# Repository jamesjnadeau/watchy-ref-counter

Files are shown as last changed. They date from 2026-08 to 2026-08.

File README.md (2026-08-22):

Intial prompt:

Based on the firmware available here: 

https://github.com/sqfmi/Watchy

I have clone the repo locally at ../Watchy

I'm creating a purpose built countdown timer used for reffing a football game. 

The user should see a countdown on the screen that updates every second. 
The count down should have 2 configurable start timers, start with 40 and 25 as defaults.
The user should use the two buttons on the right hand side of the device to start the timers. The top one should be the longer value
The timer buttons should have a configurable hold down before it acts as a reset of the timer, or to start the timer in general. Make it be 0.5 seconds as a default.

When the timer is up, it should buzz a configurable time, start with 1 second. 
Before the timer reaches a configurable number of seconds, default with 10 seconds, it should buzz a configurable number of times, start with 1. By default it should buzz once at 10 seconds. 

It should count down the last 5 seconds by buzzing at each second mark. So it should buzz at 5, 4, 3, 2, and 1, then do the finall configuable buzz time.
The top left button, after being held down for a configurable ammount of time, different than the above one, default 1 second, should then put the device into low power mode. The device should wake back up to normal operating mode if this button is pressed again, If in lower power mode, it should say sleeping on the display.

Please create a read me seciton below the line that documents the structure of the repo and how to install it on the device.

---

# Watchy Ref Counter

A countdown timer for sports officials, running on a
[Watchy](https://watchy.sqfmi.com) e-paper watch. Seven presets — football,
lacrosse, NCAA and NFHS baseball, NCAA and NFHS softball, and a custom slot —
each with two countdowns, big 7-segment digits, and a buzz pattern you can
follow without looking at your wrist.

**This repo stands alone.** It does not link against the
[Watchy library](https://github.com/sqfmi/Watchy); the panel is driven through
GxEPD2, the RTC chips directly over I2C, NTP through the ESP32 core's own SNTP
client, and the Bluetooth time sync through its BLE stack. Where the behaviour follows that firmware — the menu, the
set-time screen, the pin map — the comments credit it, but none of its code is
here. It builds with the reference repo nowhere on disk.

## Controls

Watchy's four buttons, by physical position:

```
   BACK (top left)  ----+---------+---- UP   (top right)
                        |  200 x  |
   MENU (bottom left) --|  200    |---- DOWN (bottom right)
                        +---------+
```

Watch out for the names: on Watchy, **MENU is the bottom-left button and BACK
is the top-left one**, which is the opposite of what they sound like.

| Button | Action | Default hold |
| --- | --- | --- |
| Top right | Start, or reset, the active preset's **long** clock | 0.5s |
| Bottom right | Start, or reset, the active preset's **short** clock | 0.5s |
| Top left | Enter low power mode; hold again to wake | 1.0s |
| Bottom left | On Ready, open the settings menu; otherwise clear the clock | 0.5s |

The two right-hand buttons always run whichever preset is active — see
*Sports* below — rather than a fixed 40 and 25 seconds.

The bottom-left button does two jobs because on the Ready screen there is no
clock to clear. Hold it there and you get the reference Watchy menu; hold it
while a clock is up and it clears back to Ready.

**A short tap does nothing.** Every action needs a deliberate hold, so a button
brushed against a sleeve mid-game cannot reset the play clock. A short
confirmation buzz fires the instant a hold registers, so you know the clock
started without looking down.

Holding a timer button while that clock is already running restarts it from
its full value.

## Sports

The right-hand buttons run whichever preset is active. Seven ship in the box
— six fixed sports plus one editable Custom slot:

| Name | Description |
| --- | --- |
| Football | football |
| Lacrosse | lacrosse shot |
| Base NCAA | NCAA baseball |
| Base NFHS | NFHS baseball |
| Soft NCAA | NCAA softball |
| Soft NFHS | NFHS softball |
| Custom | user set |

Their clock lengths and buzz marks are in *Buzz pattern*, below. `Football`
reproduces exactly what this firmware shipped with before presets existed, so
a watch that has never opened the menu behaves the same as it always did.

The active choice comes from the menu's `Sport` row, which opens a scrolling
picker: UP/DOWN moves, MENU selects and persists, BACK leaves the stored
choice alone. Like the time zone, it is kept in NVS, so it survives a
reflash — the sport a watch is set to is a property of who is carrying it,
not of the firmware on it.

Each row shows a preset's name and its two clock values; the footer below
shows the highlighted preset's description, its position in the list, and its
two warning marks as `warn <first>/<second>`. The final-countdown value isn't
there — it's 5 for every fixed preset, so it never tells two of them apart,
and it's shown spelled out on the Custom editor instead, the one preset that
can change it.

The six fixed presets are read-only. `Edit Custom` opens the one preset that
can be changed: five fields — Long, Short, Warn 1, Warn 2, Final — with
MENU stepping to the next field and committing once past the last one, BACK
stepping back, and UP/DOWN changing the value under the cursor, the same
interaction Set Time uses. The two clocks clamp to 1–199 seconds; the three
marks clamp to 0–199, where 0 turns that mark off. Editing Custom does not
select it — pick `Custom` from the `Sport` screen to make it active, the same
separation the zone picker keeps between "known" and "in use".

## Buzz pattern

Every preset buzzes on the same four events, at the marks that preset sets:

| Event | Buzz |
| --- | --- |
| First warning, at `warnAtSeconds` remaining | `WARNING_BUZZ_COUNT` (1) short buzz |
| Second warning, at `warn2AtSeconds` remaining | `WARNING_BUZZ_COUNT_2` (2) short buzzes |
| Final countdown, at or below `finalCountdownFrom` | 1 short buzz (150ms) on each second mark |
| Expire, at 0 | 1 long buzz (1000ms) |

A mark of 0 turns it off — Football's second warning ships off, which is why
the stock clock only ever buzzes once early. A mark that falls at or inside
the final countdown is silently swallowed by the per-second buzz, which
already covers it. The two buzz counts and the expire length are global, in
`settings.h`; the marks themselves are per-preset, in `RefSport.cpp`:

| Name | Long | Short | Warn 1 | Warn 2 | Final from |
| --- | --- | --- | --- | --- | --- |
| Football | 40 | 25 | 10 | – | 5 |
| Lacrosse | 120 | 20 | 30 | 10 | 5 |
| Base NCAA | 120 | 20 | 30 | 10 | 5 |
| Base NFHS | 80 | 20 | 30 | 10 | 5 |
| Soft NCAA | 90 | 20 | 30 | 10 | 5 |
| Soft NFHS | 60 | 20 | 20 | 10 | 5 |
| Custom | 40 | 25 | 10 | – | 5 |

Every mark above is in seconds **remaining**, matching what the clock counts
down. This is worth being deliberate about, because
[ReadyRef](https://ready-ref.com/personal-timers/) — the commercial timers
this preset table is modelled on — quote their pre-warnings in seconds
*elapsed*. Their football timer's "30 second pre-warning" on a 40 second
clock is the same moment as Football's `Warn 1` of 10 above: 30 seconds in is
10 seconds left. Getting that backwards would fire the warning at the wrong
end of the play.

Buzzes are deliberately blocking, and fire *before* the screen redraws: the
buzz is the cue you actually react to, and an e-paper refresh takes most of a
second. This costs no accuracy, because remaining time is always recomputed
from the timestamp the clock started at rather than accumulated tick by tick.

## Screens

Every screen carries the wall clock at the top left and a battery gauge at the
top right.

**Ready** — shown at boot and on wake. Both of the active preset's clocks
stacked to line up with the two right-hand buttons that start them. The
footer shows the active sport's name, in capitals, in place of `HOLD TO
START` — the thing worth checking before kickoff is which preset is loaded,
not how the buttons work.

**Running** — the current clock, large, updating every second. The header is
the same wall clock and battery gauge every screen carries; it does not say
which of the two clocks is counting.

**Time expired** — `00` holds for `EXPIRED_HOLD_MS` (3s), long enough to
register the delay of game, then the watch drops back to Ready on its own.
Starting a new clock during that window cancels the return.

**Sleeping** — low power mode.

**Menu** — held open from Ready. Navigation follows the reference: UP/DOWN to
move, MENU (bottom left) to select, BACK (top left) to leave. It also drops
back to Ready by itself after `MENU_TIMEOUT_MS`, so a menu opened by accident
cannot strand you mid-game. Nine entries do not fit the panel at once, so the
list scrolls a seven-row window, keeping the highlighted entry in view the same
way the time zone picker already does. Two of the nine are conditional — **Sync
NTP** and **Sync BT** — and with neither on offer the remaining seven fit
without scrolling at all.

Every screen the menu opens times out on the same rule, and a timeout always
**discards**: Set Time leaves the clock alone, Edit Custom leaves the stored
preset alone, and the two pickers leave their stored choice alone. Only
pressing MENU past the last field commits. This matters more than it sounds —
these screens repaint about twice a second, so one left open would otherwise
hold the panel refreshing until the battery went flat.

| Entry | What it does |
| --- | --- |
| About | Version, board name, battery, time, uptime, last sync, RTC type |
| Sync NTP | Connect and set the clock from `NTP_SERVER`. Only listed once **Setup WiFi** has connected |
| Sync BT | Set the clock from a phone over Bluetooth. Listed whenever `BT_TIME_SYNC` is on |
| TZ: *name* | Pick a US time zone from a scrolling list |
| DST: Auto/Off | Turn the daylight saving rule on or off |
| Set Time | Set the clock by hand, no WiFi needed |
| Setup WiFi | Captive portal to save credentials |
| Sport: *name* | Pick one of the seven presets from a scrolling list |
| Edit Custom | Set the five Custom fields by hand |

The **Sport**, **TZ** and **DST** rows show their current value rather than
fixed text, so the menu doubles as the status display for all three. **DST**
toggles in place and redraws with a fast partial refresh; everything else
opens a screen.

**Sync NTP** is hidden until **Setup WiFi** has connected successfully, since
with no credentials stored it could only ever report a failure. The watch
remembers that in NVS (`RefWifi.cpp`), so it survives a reflash — but a watch
upgraded from a firmware without that flag has nothing stored and will hide the
row until **Setup WiFi** is run once more. A setup that fails or times out
clears the flag again, correctly: that screen wipes the saved credentials
before it raises its access point.

**Sync BT** is the other way round: it needs nothing saved, so it is there from
the first boot. It advertises the watch for `BT_SYNC_TIMEOUT_MS` (60s) and
waits for a phone to write the time; the screen says when a phone has
connected, BACK gives up early, and the result screen names the zone the
conversion used. See *Setting the clock from a phone* below for what to press
on the phone.

There is no "Show Accelerometer". The reference has one, but nothing on a play
clock reads the sensor, and leaving it out means the BMA423 is never powered
up at all. There is no "Vibrate Motor" buzz test either — the buzzer announces
every warning mark and every expiry, so a dedicated screen for it earned a menu
row it did not need.

## Time zones and daylight saving

The RTC holds UTC. The zone offset is applied on the way out, every time the
clock is read, which is what makes the two menu entries cheap: changing zone or
flipping the DST switch takes effect on the next redraw and never rewrites the
clock chip.

The **TZ** entry lists all eleven US zones by name, with their standard offset
on the row and the abbreviations and region underneath:

| Zone | Standard | Daylight | Where |
| --- | --- | --- | --- |
| Eastern | UTC−5 EST | EDT | NY, DC, Atlanta, Miami |
| Central | UTC−6 CST | CDT | Chicago, Dallas, Minneapolis |
| Mountain | UTC−7 MST | MDT | Denver, Salt Lake, Albuquerque |
| Arizona | UTC−7 MST | — | most of Arizona |
| Pacific | UTC−8 PST | PDT | LA, Seattle, SF, Las Vegas |
| Alaska | UTC−9 AKST | AKDT | most of Alaska |
| Aleutian | UTC−10 HST | HDT | western Aleutians |
| Hawaii | UTC−10 HST | — | Hawaii |
| Samoa | UTC−11 SST | — | American Samoa |
| Atlantic | UTC−4 AST | — | Puerto Rico, USVI |
| Chamorro | UTC+10 ChST | — | Guam, N. Marianas |

**DST: Auto** means the US federal rule is applied when the date calls for it —
forward at 02:00 local standard on the second Sunday in March, back at 02:00
local daylight on the first Sunday in November — not that the clock is shifted
year round. Nothing needs doing at a changeover: the offset is computed from
the instant being displayed, so the watch is right on both sides of it and
right again if it is rebooted or asleep across it. **DST: Off** pins the zone
to standard time all year. The five zones with no daylight saving ignore the
switch either way.

Both settings are stored in NVS, so they survive a reflash — the zone is a
property of where the watch is, not of the firmware on it. `DEFAULT_TIME_ZONE`
and `DEFAULT_DST_AUTO` in `settings.h` are only the starting point, used until
the menu has been used once.

The rule is the one in force since 2007 (Energy Policy Act of 2005). It is
verified against the real transition dates for 2024–2027 and 2030 in every
zone; see *Testing* below. Set Time is exact except for the one hour a year
that springing forward deletes — typing 02:30 on that morning stores 01:30,
because 02:30 never happens.

## Timekeeping

The time comes from the watch's RTC chip, which `RefRtc` probes for at boot —
a PCF8563 at 0x51 on the V2.0, an RV-3028-C7 at 0x52 on the C6 board. It
keeps running through low power mode and
through a reflash, so the watch only needs setting once. The About screen
reports which one was found.

The chip is kept in UTC, not local time. That is what lets the zone and DST
settings change with no clock write and no drift, and it means an NTP sync
needs no offset applied to it.

Drift is handled three ways. **Set Time** sets it by hand, in local time.
**Sync BT** sets it from a phone over Bluetooth, with no WiFi involved.
**Sync NTP** sets it from the internet, on demand from the menu. It also runs
itself automatically once WiFi credentials have been saved, on a schedule
that needs both of these to be true: the watch has sat untouched — no button
press, no sleep entry — for `NTP_RESYNC_HOURS` (3 by default), and at least
`NTP_MIN_SYNC_INTERVAL_HOURS` (24) have passed since the last attempt, so a
run of idle moments in a row cannot trigger back-to-back radio activity.
Sleep entry counts as activity in its own right, so putting the watch away
resets the quiet clock rather than letting it tick through the night. Set
`NTP_RESYNC_HOURS` to 0 to only ever sync by hand. A PCF8563 drifts roughly a
minute a month, so even a daily sync keeps that under a second. The C6 board's
RV-3028-C7 is factory trimmed to about half a minute a year, and needs the
sync far less.

The two chips do not share a register layout, and the difference is the kind
that fails quietly: the PCF8563 holds the date at 0x05 and the weekday at
0x06, while the RV-3028 has the weekday at 0x03 and the date at 0x04. Decoding
one with the other's map yields a day of the month between 0 and 6 — wrong,
but shaped like a date. `tests/rtc_test.cpp` pins both layouts against a stub
I2C bus, which is the only part of this that can be checked without hardware.

An automatic sync blocks for several seconds while the radio comes up, which
is why it waits for quiet rather than firing the moment nobody is looking.
That holds even in low power mode: the watch arms a deep-sleep timer against
the same schedule, wakes itself when a sync falls due, syncs, and goes
straight back to sleep — the SLEEPING screen already on the panel is never
touched. It never runs while a clock is counting.

### Setting the clock from a phone

**Sync BT** is for the case WiFi does not cover: a field with no network you
have credentials for, and a phone in your pocket that knows the time.

The watch is the peripheral. While the screen is open it advertises the
standard Bluetooth **Current Time Service** (`0x1805`) under `BT_DEVICE_NAME`,
and the phone connects and *writes* the time into it. That direction is the
only one that works without an app written for this watch: neither iOS nor
Android will hand its clock to an arbitrary peripheral that asks for it, but
writing into a watch's Current Time Service is exactly what the service is
for. It is the same route the open source PineTime firmware takes, which is
why the apps that already do it work here unchanged:

| On the phone | What to do |
| --- | --- |
| **Gadgetbridge** (Android, F-Droid) | Pair the watch as a generic device; it syncs time to a connected device on its own |
| **nRF Connect** (Android / iOS) | Connect, open service `0x1805`, write characteristic `0x2A2B` |
| Anything else that syncs time to a BLE watch | Point it at the Current Time Service |

Two characteristics are accepted, both standard:

| UUID | What it carries |
| --- | --- |
| `0x2A2B` Current Time | year, month, day, hour, minute, second — the clock itself |
| `0x2A0F` Local Time Information | the UTC offset that clock is expressed in |

The first is the one that matters. The second decides how the wall clock a
phone writes becomes the UTC the RTC holds: with it, the phone's own offset is
used and the watch's **TZ** setting does not enter into it; without it, the
time is taken as local to whatever zone the watch is set to, exactly as a time
typed into **Set Time** would be. Most clients send only the first, which is
fine as long as the phone and the watch agree about the zone — and the result
screen says which of the two happened, so an hour out is diagnosable rather
than mysterious. A write is refused outright if it does not parse or falls
outside a sane range, so a stray or malformed packet cannot set the clock to
1970.

Nothing is bonded or encrypted. The only thing a stranger in radio range can
do is set the watch's clock, and only in the minute the screen is open; that
is not worth pairing every phone that might want to set it. The radio is up
only inside that window — `RefBleTime::begin()` starts the controller and
`end()` takes it back down — so a watch that never opens the screen pays
nothing for the feature but the flash it occupies.

Automatic sync stays with NTP by default. Set `BT_AUTO_SYNC_SECONDS` above 0
and a due sync that NTP could not satisfy — no credentials, or a failed
connection — falls back to advertising for that long, which is worth having
only if a companion app on a phone syncs time to this watch by itself. The two
radios are never up at once: WiFi is dropped before Bluetooth starts.

The header clock is repainted on its own partial window when the minute rolls
over, so keeping it live costs one ~400ms refresh a minute rather than a whole
screen. It is deliberately **not** updated while a clock is counting down: the
tick path stays reserved for the countdown, so the time can sit stale for as
long as the active clock runs — up to 199s on Custom at its ceiling — and
catches up as soon as the clock stops.

## Repo structure

```
watchy-ref-counter/
├── README.md          this file
├── platformio.ini     build config; one env per supported board (V2.0, C6)
└── RefCounter/        the sketch (also a valid Arduino IDE sketch folder)
    ├── RefCounter.ino main loop and the IDLE/RUNNING/EXPIRED/SLEEPING states
    ├── settings.h     every tunable number, and nothing else
    ├── board.h        the pin map, per revision, and button polarity
    ├── Buttons.h/.cpp debounced reads with one-shot hold detection
    ├── Buzzer.h/.cpp  vibration motor
    ├── RefPanel.h/.cpp    the GxEPD2 panel instance and its pins
    ├── RefDisplay.h/.cpp  screen layout and e-paper refresh strategy
    ├── RefRtc.h/.cpp      the PCF8563 and RV-3028-C7 clocks, over I2C
    ├── RefClock.h/.cpp    timekeeping, NTP sync, battery
    ├── RefZone.h/.cpp     US time zones and the daylight saving rule
    ├── RefSegments.h/.cpp  where the countdown digits land, host-tested
    ├── RefSport.h/.cpp     sport presets and the custom slot
    ├── RefWifi.h/.cpp      whether WiFi has ever been set up, host-tested
    ├── RefMenuItems.h/.cpp the menu's row order and labels, host-tested
    └── RefMenu.h/.cpp      the settings menu
```

### Dependencies

Three libraries, all from the registry:

| Library | For |
| --- | --- |
| GxEPD2 | the GDEY0154D67 panel, including fast partial update |
| Adafruit GFX | fonts and primitives |
| WiFiManager | the captive portal behind "Setup WiFi" |

Bluetooth adds no fourth: the BLE stack and its GATT server come with the
ESP32 Arduino core, and the Current Time Service is a handful of bytes this
project encodes itself, in `RefCtsTime.cpp`.

Everything else is either this project's own or comes with the ESP32 Arduino
core. Notably there is **no RTC library**: each RTC is a handful of BCD
registers, and talking to them directly avoids a dependency that caused
trouble — one whose `master` no longer compiles against a current core.

The folder is named `RefCounter/` so it satisfies the Arduino IDE's rule that a
sketch folder match its `.ino`, while `platformio.ini` points `src_dir` at the
same folder. One copy of the source, two build systems.

### Design notes

**Why none of the Watchy library is used.** Its `Watchy::init()` is the whole
lifecycle — wake, draw one frame, deep sleep — and it ends in `deepSleep()`
without returning, which cannot work for a clock that ticks every second. That
alone forced an own main loop. Reusing just the menu then proved impossible
too: `Watchy::showMenu()` hard-codes six entries, and `showBuzz()`, `setTime()`
and `showSyncNTP()` each finish by redrawing it, so "Show Accelerometer" could
not be dropped without it flashing back for 2.6s after most actions. With the
menu written here anyway, the remaining pieces — a GxEPD2 wrapper, two RTC
chips and an NTP call — were smaller than the dependency they justified.

**Digits are drawn, not typed.** The countdown is seven filled rectangles per
digit rather than a font glyph. That keeps the countdown's exact bounding box
knowable, which is what lets the partial-update window below be hard-coded
safely — the claim now rests on `layoutCount` in `RefSegments.cpp`, which is
host-tested against its own 199 ceiling, rather than on the countdown always
being exactly two digits — and it drops the 14KB DSEG7 font from the build.
The segment geometry is four numbers (`SegStyle`) per size, instantiated in
`RefDisplay.cpp`, so resizing the digits is a one-line change.

**Refresh strategy.** Three tiers, cheapest first:

| Call | Area | Cost | Used for |
| --- | --- | --- | --- |
| `renderDigits()` | 200x124 window | ~280ms | every second of a running clock |
| `render(v, false)` | whole screen, partial | ~400ms | state changes (start, expire, wake) |
| `render(v, true)` | whole screen, full | ~2.6s | returning to Ready |

`renderDigits()` repaints only the countdown into the framebuffer and calls
GxEPD2's `displayWindow()`, so only 62% of the panel is driven — the header,
footer and battery are left standing. The window widened from 176px to the
full 200px so it always covers the skinny hundreds bar; the extra cost every
second is the price of never leaving a stale leading `1` behind when a clock
crosses back under 100.

Partial refreshes leave faint ghosting, and only a full refresh clears it. Both
routes back to Ready arrange for one, but neither pays for it up front:

- **A clock expires.** `00` holds for three seconds, then the return to Ready
  is itself the full refresh. One redraw does both jobs, and by then play has
  stopped.
- **You clear it by hand.** The return is a *partial* refresh, so the button
  responds in ~400ms rather than freezing for 2.6s. The full refresh is queued
  for `SCREEN_TIDY_DELAY_MS` later and only fires once nothing is happening;
  starting a clock cancels it.

Either way the 2.6s stall never lands mid-down.

**Power.** The CPU drops to 80MHz, and the watch light-sleeps between button
polls whenever no clock is running, waking on a button GPIO with a 250ms timer
as a backstop. Low power mode is a real deep sleep with an `ext1` wake on the
top-left button, plus a timer wake armed against the NTP resync schedule so
the watch can correct its clock unattended. Set `LIGHT_SLEEP_WHEN_IDLE` to
`false` in `settings.h` to fall back to plain polling if your board misbehaves.

**Accuracy.** The countdown is derived from `esp_timer_get_time()` against the
main crystal. Light sleep during e-paper busy-waits is accounted for using the
calibrated RTC slow clock, which drifts a fraction of a percent — on the order
of a tenth of a second across a 40 second count.

## Configuring

Everything lives in [`RefCounter/settings.h`](RefCounter/settings.h). The ones
you are most likely to touch:

```c
static const char     DEFAULT_SPORT[]      = "Football"; // until set in the menu
static const uint16_t CUSTOM_LONG_SECONDS  = 40;  // the Custom slot's factory
static const uint16_t CUSTOM_SHORT_SECONDS = 25;  //   values, likewise only a
static const uint16_t CUSTOM_WARN_SECONDS  = 10;  //   starting point
static const uint16_t CUSTOM_WARN2_SECONDS = 0;   // 0 = off
static const uint16_t CUSTOM_FINAL_FROM    = 5;
static const uint32_t TIMER_HOLD_MS        = 500;  // hold to start / reset
static const uint32_t SLEEP_HOLD_MS        = 1000; // hold for low power mode
static const uint32_t BUZZ_EXPIRE_MS       = 1000; // buzz at zero
static const uint8_t  WARNING_BUZZ_COUNT   = 1;    // buzzes at the first mark
static const uint8_t  WARNING_BUZZ_COUNT_2 = 2;    // buzzes at the second
static const bool     DARK_MODE           = true;  // true = white on black
static const bool     CLOCK_24_HOUR       = false;
static const char     DEFAULT_TIME_ZONE[] = "Eastern"; // until set in the menu
static const bool     DEFAULT_DST_AUTO    = true; // apply the US rule by date
static const uint32_t NTP_RESYNC_HOURS    = 3;  // 0 = only sync by hand
static const uint32_t NTP_MIN_SYNC_INTERVAL_HOURS = 24; // floor since last try
static const bool     BT_TIME_SYNC        = true; // false drops the Sync BT row
static const char     BT_DEVICE_NAME[]    = "Ref Counter"; // as seen by phones
static const uint32_t BT_SYNC_TIMEOUT_MS  = 60000; // how long it waits
static const uint32_t BT_AUTO_SYNC_SECONDS = 0; // 0 = manual Bluetooth only
```

`DEFAULT_SPORT` and the five `CUSTOM_*` values are likewise only a starting
point. The clock lengths themselves moved to the on-watch menu — `Sport` picks
among the six fixed presets, and `Edit Custom` changes the Custom slot's
numbers on the watch, with both choices kept in NVS across a reflash. Editing
these constants and reflashing only changes what a watch starts on before
anyone has touched its menu.

`DEFAULT_TIME_ZONE` and `DEFAULT_DST_AUTO` are only defaults — the menu's
**TZ** and **DST** entries override them and the choice is kept in NVS across
reflashes.

`DARK_MODE` flips the whole theme, panel border included. The stock Watchy
`7_SEG` face ships with its own `DARKMODE true`, which is why it is white on
black; there is no inversion in the display driver itself.

Clock values are limited to 1–199. The display draws two full-size digits
plus, for 100 and up, a skinny leading `1` — just the two vertical bars of a
`1`, one segment thick — to their left; the two full digits shift right to
make room. There is no room for a fourth glyph, which is why 199 is the
ceiling.

The timing values are no longer reflash-only: they sit behind the on-watch
`Sport` and `Edit Custom` entries, which need a deliberate hold from the Ready
screen to reach and time out on their own if left open, the same protection
against a fumbled button that the rest of the menu has. The six fixed presets
cannot be edited at all — only the Custom slot can, and only from the watch.

If the buttons on your unit sit in different positions than the diagram above,
swap the four role defines at the bottom of
[`RefCounter/board.h`](RefCounter/board.h) rather than editing the sketch.

## Installing

This firmware supports two boards: the **Watchy V2.0** (ESP32) and **this
repo's own ESP32-C6-MINI-1 design** in [`board-files/`](board-files/). V1.0,
V1.5 and V3 were dropped — the V1 revisions put the up button and the battery
tap on other pins, V1.0 carries a different RTC chip entirely, and V3's ESP32-S3
target has been superseded by the C6 board. `board.h` stops the build if any of
their revision flags is set, rather than flashing a pin map built for other
hardware.

### Option A — PlatformIO (recommended)

Requires [PlatformIO Core](https://platformio.org/install/cli) or the VS Code
extension.

Nothing to check out first — the three libraries are pulled from the registry
on the first build. Plug the watch in, then build and flash. Pick the env for
your board — `watchy_v2` (the default) or `watchy_c6`:

```bash
pio run -e watchy_v2 -t upload
```

`watchy_c6` pulls a different PlatformIO platform — the pioarduino fork —
because the official `espressif32` tops out at Arduino-ESP32 2.0.17, which has
no ESP32-C6 support at all. Note that the board has never been fabricated, so
nothing in that env has run on anything.

The first build downloads about 1.5GB of ESP32 toolchain and takes a few
minutes; later builds take under a minute.

### Option B — Arduino IDE

1. **Board support.** In *Preferences → Additional Board Manager URLs* add:
   `https://raw.githubusercontent.com/espressif/arduino-esp32/gh-pages/package_esp32_index.json`
   then install **esp32** (2.0.5 or newer) from *Tools → Board → Boards Manager*.

2. **Libraries.** *Tools → Manage Libraries*, then install **GxEPD2**,
   **Adafruit GFX Library** and **WiFiManager** (tzapu). Accept the dependency
   prompts. Do *not* install the Watchy library; this sketch does not use it.

3. **Board target.** *Tools → Board → ESP32 Arduino* → **ESP32 Dev Module**
   for the V2.0. The pin map is this project's own, so the board only has to
   be the right chip. (The C6 board is PlatformIO-only here; the IDE's ESP32-C6
   support depends on a 3.x core that this project does not otherwise require.)

   Then set the revision. The IDE has no build-flag field, so uncomment this
   line near the top of [`RefCounter/board.h`](RefCounter/board.h) — it has to
   go in that header, which every source file includes, not in the `.ino`,
   which would only set it for itself:

   ```c
   // #define ARDUINO_WATCHY_V20
   ```

   Under PlatformIO this is handled by `build_flags` and no edit is needed.

   Also set *Tools → Partition Scheme* to **Huge APP**, or the WiFi and
   Bluetooth stacks will not fit.

4. **Open and upload.** Open `RefCounter/RefCounter.ino`, select the serial
   port under *Tools → Port*, and hit Upload.

### If upload fails

The watch must be awake to enumerate over USB. If it is in low power mode, hold
the top-left button to wake it first.

On the **C6 board**, there is no button to hold: the download-boot strapping
pin is IO9, and this board deliberately puts no button on it, so a stuck or
dirty button can never drop the watch into the bootloader by accident.
Forcing download mode means shorting the **TP1** test pad to ground at
reset. The V2.0 has no button on GPIO 0 and relies on the USB serial chip's
auto-reset instead, so there is no button to hold there either; if
auto-reset is not working, it is a cable or port problem rather than a
timing one.

## Testing

`RefZone.cpp`, `RefSegments.cpp`, `RefSport.cpp`, `RefWifi.cpp`,
`RefCtsTime.cpp` and `RefMenuItems.cpp` carry no panel, no GPIO and no radio,
so they compile on a host and the daylight saving rule, the digit layout, the
preset table, the WiFi flag, the Bluetooth time payloads and the menu's row
order are all checked off the watch — this is exactly the kind of bug (a
changeover date, a digit running off the panel, a clamp, a menu row in the
wrong place, a Bluetooth packet believed when it should not be) that is
expensive to find on hardware and cheap to catch here.

```bash
./tests/run.sh
```

`tests/tz_test.cpp` walks the exact transition instants for 2024, 2025, 2026,
2027 and 2030, checks January and July in all eleven zones, checks that
**DST: Off** pins every zone to standard time, and round-trips 1,460 local
times through local → UTC → local. `tests/tz_edges.cpp` prints what Set Time
does inside the two transition hours. Both build the shipped `RefZone.cpp`
against a stub `Preferences` that reports nothing stored, so the `settings.h`
defaults apply.

`tests/segments_test.cpp` pins `layoutCount`'s numbers for the two styles the
panel actually uses — the two-digit and three-digit layouts, the exact pixel
`x` positions, the 100/99 boundary where the hundreds bar appears and
disappears, and clamping above 199 — then checks, exhaustively and for both
the big (RUNNING/EXPIRED) and small (Ready) styles, that no digit runs off
either edge of the panel for every value 0 through 199. SMALL is not a
theoretical case: the Ready screen draws both of the active preset's clocks
in it, and Lacrosse, Base NCAA and Custom all reach past 100. It checks
`layoutRows` the same way, including the invariant that the upper, middle
and lower segment rows abut with no gap or overlap.

`tests/sport_test.cpp` checks the shipped preset table against the numbers in
*Buzz pattern* above, that `Custom` is always the last entry, that an out-of-range index
falls back to the first preset rather than reading off the end of the table,
and that every name and description fits the menu row and picker footer they
render into. It also exercises persistence itself: the stub `Preferences`
gained a switch (`PreferencesStub::enable`) so a test can turn storage on,
which the time zone tests deliberately never do. With it on, `sport_test`
confirms the selected sport and the edited Custom fields both survive a
simulated reboot (a fresh `RefSport::begin()` call), and that a garbage index
left in NVS clamps back to the first preset rather than being trusted.

`tests/wifi_test.cpp` checks that a watch with nothing stored — or with NVS
unavailable — reads as never set up, and that the flag survives a simulated
reboot in both directions.

`tests/cts_time_test.cpp` covers the Bluetooth Current Time payloads: the ten
byte layout a phone writes, every field's range, the month lengths and the
leap year rule, the year window that throws out a phone whose own clock has
never been set, the short writes that are still understood and the ones that
are not, that a rejected write leaves the caller's `struct tm` untouched, and
that a wrong day-of-week in the packet is recomputed rather than trusted. It
does the same for Local Time Information — negative zones, half hour zones,
the "unknown" values — and round-trips what the watch publishes back through
its own parser, since a phone reading the watch and a phone writing to it must
agree about the same offset.

`tests/menu_items_test.cpp` pins the menu's row order for all four
combinations of its two conditional rows, that **Sync NTP** is absent until
WiFi is set up and **Sync BT** is present from the first boot, and that
**Setup WiFi** shifts from slot 4 to slot 6 as they appear above it — which is
the case the menu's redraw depends on, since running **Setup WiFi** inserts a
row above the one the user is standing on. It also checks that every label fits
the 18 glyphs the panel has room for, and that the removed buzz test has not
crept back in.

Nothing else here has automated tests, and none of this has run on hardware —
see below.

`tests/board_test.cpp` and `tests/board_c6_test.cpp` add a second kind of
check: they assert the V2.0 and C6 pin maps and each board's `BOARD_NAME`,
which until now nothing did for the C6 at all. `tests/run.sh` then compiles
`board.h` three more times, once per retired revision flag, to confirm each is
rejected rather than quietly building the V2.0 map.

`tests/rtc_test.cpp` runs the real `RefRtc` against a stub I2C bus
(`tests/stub/Wire.h`), where a device is a flat file of registers. It covers
both chips' BCD decoding, both register layouts, the two "the time is not set"
flags — the PCF8563's low-voltage bit and the RV-3028's power-on reset bit —
and a write-then-read round trip. Mutating the RV-3028 reader to use the
PCF8563's date register, or to skip the power-on reset check, fails it.

## Known limitations

- **None of this has been run on a watch.** It builds clean for both supported
  boards and the time zone, digit-layout and sport-preset logic are tested
  on a host, but no part of it has been exercised on real hardware. The least
  proven pieces are `RefPanel::begin()` (GxEPD2's stock init rather than the
  reference firmware's tuned one), light sleep, and whether the four buttons
  are physically where `board.h` says they are. `RefRtc`'s BCD decoding and
  chip probing used to head that list; they are now covered by
  `tests/rtc_test.cpp` against a stub bus. That covers the register layouts,
  the BCD conversion in both directions and the failure paths; it says nothing
  about whether either chip answers at its address on a real board, and the
  stub models none of clock stretching, arbitration or the RV-3028's bus
  timeout.
- Sport presets add their own untested territory: whether the leading `1`
  actually clears from the panel when a clock crosses 100 → 99 (the widened
  refresh window is the fix; only a real panel confirms it), whether nine
  menu rows scroll legibly with the highlight landing on the right row, and
  whether the Custom editor's five rows fit without the descenders clipping.
  NVS is assumed to survive a reflash for the `refsport` namespace the way it
  reportedly does for `refzone`, but that has never been confirmed either.
- Longer presets mean longer runs of partial refreshes: a 40s Football clock
  was already 39 consecutive `displayWindow` ticks before the deferred full
  refresh, but a 120s Lacrosse clock is 119 and Custom at its 199 ceiling is
  198. The full refresh on the way back to Ready still runs and still clears
  it, so nothing is broken, but how much ghosting a run that long leaves on a
  real panel in between is untested like everything else here.
- Buttons are not sampled during a buzz or a screen refresh. A hold that starts
  and ends inside one of those windows is missed; a hold you keep held is
  always caught, up to ~400ms late.
- Continuous running is the worst case for battery. Expect several hours of
  active use on a full charge; use low power mode between games.
- Bringing up WiFi for an NTP sync blocks for several seconds, and buttons are
  ignored for that whole time. It only happens after 60s untouched, and never
  during a countdown, but it is a real pause if you catch it.
- Only US time zones are listed. Elsewhere, pick whichever standard offset
  matches and turn **DST** off, or add a row to the table in `RefZone.cpp`.
- The daylight saving rule is the current US one, hard-coded. If Congress makes
  daylight saving permanent, this needs a firmware change.
- Adding WiFi grew the binary from 402KB to 1.13MB and RAM use from 29KB to
  55KB. Both are comfortably within a 4MB / 320KB device. Bluetooth adds the
  BLE stack on top of that; the `huge_app` partition leaves room for it, but
  the exact figure has not been measured here — see below.
- **The Bluetooth sync has not been run against a phone.** The byte layouts
  are host-tested and the GATT calls are written to the API that every
  Arduino-ESP32 backend shares, but nothing has confirmed that a real phone
  finds the watch, writes to it and lands on the right minute. Nor has the
  build itself been compiled: the toolchain could not be fetched in the
  environment this was written in, so the firmware figures above are the
  pre-Bluetooth ones.
- A phone will not volunteer its clock. **Sync BT** needs an app on the phone
  that writes the Current Time Service — Gadgetbridge does it by itself, nRF
  Connect does it by hand — and there is no route that works from a stock
  phone with nothing installed.
- Nothing is bonded or encrypted, so anyone in radio range can set the clock
  while the **Sync BT** screen is open. That window is a minute long and the
  worst outcome is a wrong time, which is why it is left open.
- A phone that sends no zone with the time is assumed to be in the zone the
  watch is set to. Travel to a different zone with **TZ** left behind and the
  clock lands an hour or more out; the result screen says which assumption it
  made.

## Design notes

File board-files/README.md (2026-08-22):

# Watchy Ref — ESP32-C6-MINI-1 / RV-3028-C7 board

A Watchy-compatible watch board carrying an ESP32-C6-MINI-1 module and an
RV-3028-C7 real-time clock, with the accelerometer, the USB-serial bridge and
the UART console deleted and USB-C in place of micro-USB. Derived from
[sqfmi/watchy-hardware](https://github.com/sqfmi/watchy-hardware) `v2.0`
(MIT), which supplies the e-paper, charging, power and motor circuitry
unchanged.

Design rationale, with the reasoning behind every decision:
[`docs/superpowers/specs/2026-08-18-c6-mini-rv3028-board.md`](../docs/superpowers/specs/2026-08-18-c6-mini-rv3028-board.md).

> **Never fabricated, never powered, never tested.** Read
> [`UNVERIFIED.md`](UNVERIFIED.md) before doing anything with these files.

## The design is code

The electrical design is not a drawn schematic. It is
[atopile](https://atopile.io) source under `elec/src/`, compiled to a KiCad
netlist. Reading `elec/src/watchy.ato` top to bottom tells you what is
connected to what, and `git diff` on it says exactly what a change did —
which is not true of a `.kicad_sch`.

The tradeoff is real and worth stating: there is no schematic sheet to print
and hand to someone. `ato view` draws a block diagram, but it is not a
schematic. If you want one, KiCad's netlist import gives you a rat's nest, not
a drawing.

```
board-files/
  ato.yaml                          project and build config
  requirements.txt                  the compiler version, pinned exactly
  elec/src/watchy.ato               the board: every part and every connection
  elec/src/parts.ato                passives, discretes, connectors, switches
  elec/src/mcu.ato                  ESP32-C6-MINI-1
  elec/src/rtc.ato                  RV-3028-C7
  elec/src/usb.ato                  USB-C receptacle and the ESD array
  elec/footprints/footprints.pretty custom footprints
  elec/layout/default/              the PCB (see "Layout" below)
  checks/netlist_check.py           design assertions against the netlist
  checks/drc_check.py               runs KiCad's DRC and judges the result
  checks/make_bom.py                fab BOM generator
  checks/run.sh                     build, assert, generate, check the board
  elec/layout/v2-baseline.kicad_pcb V2's layout, untouched; the overlap reference
  scripts/apply_netlist.py          netlist -> PCB, headless (mutates the board)
  scripts/route.py                  routes the board, headless (mutates it too)
  scripts/check_board.py            asserts the PCB matches the netlist
  fab/BOM.csv                       generated, committed
  vendor/                           upstream licence notices
```

## Building and checking it

```bash
python3 -m venv ~/.venvs/ato
~/.venvs/ato/bin/pip install -r requirements.txt
ATO=~/.venvs/ato/bin/ato ./checks/run.sh
```

That compiles the sources to `build/default.net`, runs the assertions, writes
`fab/BOM.csv`, checks the board against the netlist and runs DRC. Expect
`0 problem(s)` and 54 placements.

**Install from `requirements.txt`, not `pip install atopile`.** The pin is
`atopile==0.2.67` and it is exact on purpose: the floating install now gets
0.12.6, which refuses to run at all ("the CLI has been replaced by the app at
app.atopile.io"). `checks/run.sh` checks the version and stops if it is
wrong. `requirements.txt` records what every newer release does — the short
version is that 0.3 through 0.11 reject these sources, 0.12 is dead, 0.14 and
0.15 need Python 3.14, and 0.16+ is a hosted application rather than a CLI.
There is no upgrade that keeps this a headless build.

The assertions encode the constraints the spec cares about and that no
compiler can see:

| Check | What it catches |
| --- | --- |
| pin map | any GPIO that drifted from the spec's table |
| deep-sleep wake pins | a button or `RTC_INT` on a pin above IO21, which cannot wake `ext1` |
| battery ADC on ADC1 | the battery tap landing on ADC2, which is dead while WiFi is on |
| strapping pins | anything but the `TP_BOOT` test pad touching IO9 |
| USB-C CC pulldowns | a missing or shared 5.1k, and D+/D- halves left untied |
| RV-3028-C7 wiring | `VDD` off `+BATT`, or `VBACKUP` fed from a rail |
| bus pull-ups | I2C or `RTC_INT` pulled to `+BATT`, putting 4.2V on C6 inputs |
| buttons active low | a switch still wired to `+3V3`, or a leftover pull-down |
| battery divider | the divider back at 100k, or missing its filter cap |
| MCU power | the `-N4R2` variant, a floating module ground pad, EN misrouted |
| V2 blocks carried over | any drift across the 106 pads of the 43 parts transcribed from V2 |
| deleted parts | the PICO-D4, CP2102, BMA423, PCF8563, crystal or antenna creeping back |

And on the board (`scripts/check_board.py`):

| Check | What it catches |
| --- | --- |
| components | a netlist part with no footprint, or a footprint the netlist does not name |
| nets | any pad on the wrong net, or on a net where the netlist says nothing |
| mechanical | the four switches, the FPC and the battery connector drifting off V2's coordinates |
| stackup | the board falling back to 2 layers, or a missing GND / +3V3 plane |
| outline | Edge.Cuts not closing, or a cutout reappearing inside the board |
| pads on board | any pad off the edge — this is how the USB-C was found facing the wrong way |
| antenna | the module's keepout allowing pour, or not overhanging the board edge |

And DRC itself (`checks/drc_check.py`), which runs `kicad-cli pcb drc` and
holds the result to a policy rather than to a count: zero unconnected items,
zero errors except an allowlist that names each accepted violation and says
why. It also reports allowlist entries that no longer occur, so the list
cannot quietly rot.

All of these were mutation-tested: the netlist or the board was deliberately
broken in the way each check describes, and the check caught it. A check that
cannot fail is not a check.

**What is not checked: ERC — and it cannot be.** `kicad-cli sch erc` reads a
`.kicad_sch`, and this project has none; the design is atopile source
compiled straight to a netlist. Nothing looks for driven-output conflicts or
unconnected pins beyond what the assertions above happen to cover. That is a
standing cost of defining the design in code, not a temporary gap. See
[`UNVERIFIED.md`](UNVERIFIED.md).

## Layout

`elec/layout/default/watchy-ref-c6.kicad_pcb` started as V2's board, converted
from KiCad 5 and switched to a 4-layer stackup. Two scripts turn it into this
design, in order, and both are re-runnable:

```bash
python3 scripts/apply_netlist.py --dry-run   # report only
python3 scripts/apply_netlist.py             # placement, nets, planes, outline
python3 scripts/route.py                     # copper
python3 scripts/check_board.py               # verify, independently
```

They need the interpreter KiCad's `pcbnew` bindings were built against — the
system `python3`, not a venv.

### apply_netlist.py — everything except the copper

KiCad's "Import Netlist" is a GUI dialog and `kicad-cli` has no equivalent, so
this does the job with `pcbnew`. It removes the interior cutouts from
Edge.Cuts and the rule areas V2 no longer needs, deletes the parts the netlist
dropped, replaces the ones whose footprint changed *while preserving V2's
position* (most of those swaps are only a KiCad 5→7 library rename, and losing
placement over a rename would defeat the point of pinning the designators),
adds the new parts, assigns all 249 pads to their 73 nets, and lays the GND,
`+3V3` and `VBUS` pour outlines.

It also strips V2's branding — the `watchy` and `SQFMI` lettering on the mask
layers, and the two sqfmi logo footprints. This is a derivative reference
design and should not be fabricated carrying another project's marks; the
attribution belongs in this file, not etched into the board. It happens to be
worth 119 DRC errors as well: mask lettering is drawn as *apertures*, so the
word is bare copper, and every via, track and pad passing beneath one bridged
to it. The display outline (`REF**` on B.Fab) is kept — it comes from the same
library and carries the name, but it is a mechanical outline rather than a
mark, and it is what stops anything being placed under the panel.

Placement comes from a table in the script, and that table is authoritative —
it is re-applied on every run, to parts already on the board as well as to new
ones. The board is generated from these sources, so a position that only
exists because somebody dragged it in the GUI is a position nothing records.
Move a part by editing the table; the script reports every courtyard overlap
the table produces, and the fix is to edit the table again.

### route.py — the copper

There is no autorouter in KiCad and no routing API, so this is a maze router
written against `pcbnew`. It deletes every existing track and via first —
V2's routing was still on the board, and routed for V2's netlist it shorted
nets rather than connecting them — then:

- drops a via into each of the module's thermal pads. It has to: the array is
  1.2mm pads on a 1.65mm pitch, and the 0.45mm gaps are too narrow for a pour
  to enter and too narrow for a via to sit beside. Espressif's reference
  layout does the same.
- ties every pad on a poured net to its pour through its own via, except
  where the pour already touches the pad. Which nets are poured, and which of
  their pads the pour reaches, are read off the board rather than listed in
  the router -- so the two scripts cannot drift apart, and a pour that covers
  only part of its net leaves the rest as ordinary routing work.
- routes the signal nets with A* on F.Cu and B.Cu over a 0.1mm grid, hardest
  first: the differential pair and the charge-pump loop before anything can
  cross them, then whichever nets have the least room to escape their pads.
- rips up and re-routes. A net that cannot get through has usually lost a lane
  to one that went first, so a second search finds which nets are in the way,
  deletes their copper, puts the stuck net through the gap and re-routes them
  somewhere else. This is what takes the board from "almost" to finished.
- stitches GND between F.Cu, In1.Cu and B.Cu on a 3mm grid, last, in whatever
  room the signals left.
- fills the zones and reports what is still unconnected.

Power is mostly not routed as copper. GND and `+3V3` are whole-board planes
on In1.Cu and In2.Cu and a pad reaches them through a via, which is what buys
the space to route everything else on two layers.

`VBUS` is a third pour, and a bounded one. It carries the charge current -- in
at the USB-C, out through the Schottky to VSYS and into the TP4054 -- so it
wants copper rather than a track, and as eleven thin tracks fighting for lanes
it was the net the router most often failed to place. It sits on In2.Cu at a
higher priority than `+3V3`, over the block that actually carries the current:
`J2`'s four VBUS pads, `U3.5`, `C11.2`, `R14.1`, `Q4.1` and `U5.4`.

It is sized to that block and not to the net. A hull around all eleven VBUS
pads is a 202mm2 diagonal band that reaches clear across the board to collect
`D4` and `D5`, and swallows `U2.5` -- the LDO 3V3 output -- on the way, which
would strand it. Bounded to the block it costs 82mm2, traps nothing, and
leaves `D4` and `D5` as two ordinary tracks, which is what they are: stubs
hanging off the block.

In2.Cu rather than B.Cu, which is where an earlier note here suggested putting
it. Both work, but In2.Cu is already a power layer so the pour costs no
routing space, whereas the same shape on B.Cu would sit straight on top of the
`J2`/`U3`/`U5`/`Q4` congestion -- the most contested copper on the board. The
cost is a split in the `+3V3` plane under one corner of B.Cu, a return-path
discontinuity for anything crossing it, which at SPI and 12Mbps USB is not a
real concern. `VBUS_POUR_LAYER` in `apply_netlist.py` moves it.

The pour is not free. The nine covered pads are all on F.Cu, so each needs a
through via to reach In2.Cu, and a through via blocks all four layers -- nine
of them land in the tightest part of the board. `VBUS` itself routes now, and
one fewer net fails overall, but those vias took lanes `USB_DM` and `VSYS` had
been using. It is the right shape for the current path either way; it is not
the thing that finishes the board.

Every via the router places is tented on both sides. Half of them sit in a pad
field or inside a thermal pad, where a bare mask aperture would bridge to the
neighbouring pad and wick solder off the joint.

#### The board is the only source of truth

The router keeps an occupancy grid to search over, and the grid has to agree
with the copper. It used not to. There were three stores of truth rather than
two: the board, the grid, and `owned` -- a side table of which items belong to
which net -- and the grid was rebuilt from `owned`, never from the board. Any
copper that fell out of that table, or was added without updating it, was
still physically on the board and completely invisible to the router.

That is not a hypothetical. It is where `SCL` came to cross `EPD_DC` and
`EPD_BUSY` on B.Cu: a failed attempt left a partial path behind, `owned` was
overwritten with the retry, and every later rebuild pretended the old copper
was not there. Eight shorts, and nothing in the router could have noticed.

So `rebuild()` now stamps from `board.GetTracks()` and the grid is a pure
function of the board. `owned` survives as an index -- it is how a net's items
are found when it is ripped up -- but nothing is derived from it. A net can
drop out of it and the grid stays correct.

That needed one snapshot split into two, because they were doing different
jobs under one name:

| | |
| --- | --- |
| `blank` | the board with **no** copper: outline, keepouts, pads, holes. `rebuild()` and `audit()` start here, so a recomputation owes nothing to the router's own record of itself |
| `immovable` | `blank` plus the power copper. What the rip-up scout treats as *hard*: a cell blocked here is a pad or a plane drop and cannot move, while one blocked only in the live grid is some signal's track and can be ripped |

Handing the scout `blank` would let it plan routes straight through power it
may not touch, which is the bug you get for free by moving the snapshot
without noticing it had two roles.

Searching still stamps incrementally -- rebuilding after every track would be
far too slow -- so correctness rests on the incremental path matching a fresh
one. `audit()` proves it: recompute from the board, compare cell by cell,
report any difference with its coordinates and both values. This is sound
because stamping is monotone: a cell goes free -> one net -> contested and
never back, so re-stamping the same items always lands in the same state
whatever order they arrive in. A fresh rebuild is therefore the ground truth
an incrementally-updated grid must equal.

It runs every pass and prints under "GRID DISAGREED WITH THE BOARD". Anything
it reports is a bug in `route.py`; no board can legitimately make the grid and
the copper disagree. It is mutation-tested in both directions -- copper added
to the board without telling the grid, and copper removed from it -- and
catches each with the cell coordinates and both values.

#### What it does not finish

The router does not get everything. It routes the power, every ground pad and
41 of the 44 signal nets; **three are left unrouted** — `EPD_SCK` at `U1.28`,
`PREVGH` at `J1.21` and `USB_DM` at `J2.A7` — for 3 unconnected items on the
board. `route.py` exits non-zero, and `drc_check.py` and `checks/run.sh` fail,
until they are cleared. That is deliberate: a board that is 93% routed should
not be able to look finished.

`route.py` also exits non-zero on a stranded ground pad — one the pours never
reached and no via was dropped into — because a floating return is a defect
and not a cosmetic complaint. There are none at present, but they are the
failure this board produces when the right-hand side gets crowded, and they
were invisible until the pour slivers hiding them were deleted.

Which nets and which pads move between runs — the router is not deterministic
across attempts, because each attempt feeds the previous one's failures back
in. The counts are stable; the names are not.

What the router does lay down is clean. On the current board it produces **no
shorts, no crossing tracks and no clearance violations of its own**, and DRC
reports **zero errors that are not on `drc_check.py`'s accepted list** — every
clearance and hole-clearance error left is internal to a footprint (`Q4`/`R15`
at 0.165mm, inherited from V2; `J2`'s own mounting holes against its own
pads). Getting there took four fixes, each found by DRC rather than by design,
and they are worth knowing before trusting the next change:

| Bug | Symptom |
| --- | --- |
| overlapping clearance halos resolved last-writer-wins | a cell claimed by two nets became one net's, and that net then routed through the other's clearance. 96 clearance errors |
| diagonal steps cut corners | a 45° step passes between two cells it never occupies, so two opposite diagonals cross without ever sharing one. KiCad calls that a short |
| the grid went stale after rip-up | ground stitching dropped vias on top of signal vias, 0.4mm apart |
| pads keyed by (ref, name) | `J2` has four separate shield pads all called `S1`, and covering one counted as covering all four |
| pads were treated as their bounding boxes | the test points are 1mm circles and the motor's pad is an oval, so the bbox corners are outside the copper. A track that ended in one stopped short of the pad it had been routed to — and the router counted the net done, because its own reachability test used the same bbox. Six nets were "routed" and not connected |
| fill islands with nothing to reach | a pour pinched off between two tracks is still copper, still floating, and counted as unconnected. `route.py` now vias any island big enough to take one, and `apply_netlist.py` sets the zones to delete the rest |
| drilled holes were invisible to the router | an NPTH pad is a hole with no copper, so it is on no copper layer, so the pad loop skipped it entirely. Tracks routed straight over `J2`'s mounting holes and the four switches' |
| the design rules reverted behind the router's back | the rules live in the `.kicad_pro`, and loading a second board anywhere in `apply_netlist.py` makes KiCad's settings manager flush a stale copy of the project over them. 0.15 went quietly back to 0.2, and a board routed at 0.15 came back with 76 clearance errors against a rule nobody had meant to change. `apply_netlist.py` now writes them last and `check_board.py` asserts them |

Finish them in the GUI, or improve the router. What was already tried, so the
next person does not repeat it:

| Lever | Result |
| --- | --- |
| via cost swept 6 → 80 | 25 is the best; cheap vias cost more board than they save |
| ordering by pad count, by escape room, by span | all help a little; none alone gets below 5 |
| re-ordering by accumulated failure pressure, 14 attempts | the natural order won every time |
| rip-up and re-route | 5 → 3, and the only thing that moved the number much |
| search budget 80k → 250k | fixed searches that were being cut off, not the remainder |
| `VBUS` as a pour instead of a signal net | `VBUS` routes, and one fewer net fails overall — but the nine through vias it needs land in the tightest part of the board, and cost `USB_DM` and `VSYS` their lanes |

Those that remain are not walled in — each routes on its own on an empty
board — so this is congestion, not geometry, and measurably so: the pads that
*failed* have more room around them than the ones that succeeded. `J1`'s
tightest pins have 177 free cells within 1.2mm and all of them routed; the
eight that did not had 201 to 542, against a board median of 383. Nothing
failed for want of space at the pad. They failed for want of a lane, and the
lane went to whichever net asked first.

Five of the seven are at the display connector `J1` or the module pins feeding
it, which is the densest corner of the board. The lever there is not the FPC
pinout — that is fixed by the panel — but the *module* side: `EPD_SCK`,
`EPD_MOSI`, `EPD_CS`, `EPD_DC`, `EPD_RST` and `EPD_BUSY` are assigned to
`IO15`, `IO14`, `IO8`, `IO18`, `IO19` and `IO20` in `elec/src/watchy.ato`,
and those are general-purpose pins. Re-ordering them so the fan-out crosses
itself less is a change to the source, which is where this design's decisions
are supposed to live, and it is the one move the router cannot make for
itself.

Clearance is modelled as the true offset of each pad shape, not its bounding
box grown by the clearance. The difference is only at the corners, and the
corners are the whole game on a 0.5mm-pitch connector: a pad in a row that
close can only be escaped along its own axis, and squaring off the
neighbours' clearance closes exactly that lane. With bounding boxes, six of
the USB-C's pads were unreachable from anywhere.

### Placement

The parts the new layout displaced are placed by anchoring each to the pad it
actually serves and taking the nearest clear spot to it — which is what you
would do by hand, and is what decoupling wants anyway:

| Part | Anchored to | Distance |
| --- | --- | --- |
| `C12` +3V3 bulk | `U1` pad 3 (3V3) | 3.00 mm |
| `C1` EN cap | `U1` pad 45 (EN) | 2.00 mm |
| `R1` EN pull-up | `U1` pad 45 | 3.20 mm |
| `R7` RTC_INT pull-up | `U6` pin 2 (INT) | 2.12 mm |
| `Q5` motor driver | `M1` pad 2 | 3.50 mm |
| `U2` LDO | `Q4` pad 2 | **11.07 mm — review** |
| `D4` OR-ing diode | `Q4` pad 2 | **12.81 mm — review** |

`U2` and `D4` are flagged because the area around `Q4` is dense — the charger,
its programming resistors and the FPC connector are all there — and the
nearest clear space is a long way off. Both carry DC power rather than a
switching node, so the distance is tolerable, but it is worth a look before
you trust the routing there.

### The USB-C, and what it costs

`J2` is rotated 90°, with the front face of its housing flush with the board
edge at x=102.5. This matters more than it sounds: the footprint's solder tabs
are at its local −y end and the mating opening at +y, so at 0° the connector
faces *down the board* and six of its pads — including both shield tabs — hang
over the right-hand edge in mid-air. It was at 0°. `check_board.py` now
asserts every pad is on the board.

The receptacle does not really fit where V2's micro-USB was. There is 9.15mm
between the battery connector and the charger; a USB-C shell is 9.04mm wide
and its courtyard is 10.73mm. So three courtyard overlaps remain and are
accepted on purpose: `J2`/`J3` by 0.61mm, `J2`/`R16` by 0.49mm, `J2`/`Q4` by
0.13mm. The parts themselves clear each other. Moving `J2` anywhere else means
moving a part the case is cut to, or putting the port on an edge that has no
room for a 7.5mm-deep connector.

Everything else V2 carried is left where V2 had it — including a handful of
courtyard overlaps of 0.05–0.25mm that come from KiCad 9's footprints being
fractionally larger than KiCad 5's. Lifting `R8` and `R9` 0.3mm to clear one
of them was tried and reverted: it moved two parts of the charge-pump loop
off the geometry V2 proved, which is a bad trade for a rectangle that does not
touch any copper.

### Board outline

The Edge.Cuts outline measures **33.800 × 45.960 mm** on the centreline
(33.950 × 46.110 mm including the 0.15mm line width). sqfmi's published figure
of 35.5 × 46.0 mm is wrong, or at least does not describe this outline.

**V2's two watch-strap slots have been removed.** They ran at y 72.15–74.15
and y 111.61–114.11, straight through the board, and the module and its
decoupling were placed across the top one — `U1` pads 2, 3, 43 and 44, both
pads of `R1`, both of `C12` and one of `C1` were over a hole. Removing the
slots was chosen over moving the module.

The consequence is mechanical and it belongs to the case: **there is nothing
on this PCB for a strap to pin through any more, and nothing to take the
load.** The case has to carry the entire band attachment. See
[`docs/superpowers/specs/2026-08-18-waterproof-case-design.md`](../docs/superpowers/specs/2026-08-18-waterproof-case-design.md).

Board thickness stays 1.6mm so the case stack is unchanged.

### Why there is a second copy of the board

`elec/layout/v2-baseline.kicad_pcb` is V2's layout converted and given the
4-layer stackup, otherwise untouched. The overlap report diffs against it.
Diffing against the working board instead would be self-excusing: after one
run the working board *is* this script's output, so every overlap it
introduced would come back labelled "V2 already had this one". Do not edit it.

### KiCad 9 notes

- `pcbnew`'s bindings are on the system `python3` (3.13 here), not the
  `python3.12` the older instructions named.
- `board.Remove()` hands ownership of the item to Python, and freeing it there
  corrupts the SWIG type registry — the *next* `LoadBoard` comes back as a
  bare `SwigPyObject` with no methods. Use `RemoveNative()`, which deletes it
  in C++. Both scripts do.
- `PCB_VIA.SetWidth()` needs a layer argument now.
- Opening the project in KiCad 9 rewrites `watchy-ref-c6.kicad_pro` into the
  new format. No design rule changed in that upgrade; `hole_near_hole` was
  renamed `hole_to_hole` and demoted to a warning, and `text_on_edge_cuts` was
  added as an error.

## Fabrication

Nothing here is ready to order — see [`UNVERIFIED.md`](UNVERIFIED.md) — but
when it is:

- 4 layers, 1.6mm, ENIG. The module, the RV-3028 and the 0.5mm FPC connector
  are all fine pitch; HASL is not worth the yield risk.
- Tracks are 0.15mm with 0.15mm clearance, vias 0.6mm with 0.3mm drills. Any
  fab that will build a 4-layer board at all will build 0.15/0.15; it is not
  an "advanced" option and carries no price break to avoid. The board was
  0.2/0.2, inherited from V2, and on a board whose problem is corridors that
  was costing a quarter of every one of them.
- Solder mask expansion is 0.05mm. V2 had 0.2mm, which makes every opening
  0.4mm wider than its pad — on 0.5mm-pitch parts that guarantees neighbouring
  openings merge, and once the tracks came down to 0.15mm it bridged them to
  passing copper too. It was worth 155 DRC violations on its own.
- GND pads connect to the F.Cu and B.Cu pours **solidly**, not through thermal
  spokes. This is a trade: thermal relief exists to stop a pour sinking heat
  away from a small pad during reflow, and solid connections raise the risk of
  a 0402 tombstoning. Against that, GND pads get no via down to the In1.Cu
  plane — the router skips them because the outer pours already touch them —
  so the pour *is* the ground connection, and on twenty of them it could only
  reach with a single 0.15mm spoke. If a fab pushes back, the other fix is to
  keep thermal relief and give every GND pad its own via to In1.Cu, which
  costs routing space this board does not have spare.
- **Vias in pads**, in the module's thermal array only, where nothing else
  reaches. Ask for them plugged and capped, or expect solder to wick off
  those pads into the barrel.
- Single-sided assembly: every part is on F.Cu.

Order `ESP32-C6-MINI-1-N4` (4MB flash) or `-H8` (8MB). There is no PSRAM
variant to get wrong, unlike the S3-MINI-1's `-N4R2`. Specify genuine Micro
Crystal for the RV-3028-C7.

The display, battery, vibration motor and case assembly are hand work. No
assembly house will finish this board into a watch.

## Firmware

Firmware support for this board does not exist. `RefRtc` short-circuits to the
internal clock on any C6 build and has no RV-3028 driver. The
"Firmware impact" section of the spec lists what is needed; it is a separate
plan and nothing in this directory implements any of it.

The panel the firmware drives is now the **GDEY0154D67**, which replaces the
end-of-life GDEH0154D67. Same SSD1681 controller, same 200x200, same 24-pin
FPC, and GxEPD2 takes the same four-pin constructor — but the GDEY's FPC
pinout has not been read off a datasheet and compared against `J1` pin by
pin. Do that before you power a panel.

## Licences

- The V2 design this is derived from: MIT, `vendor/LICENSE-watchy-hardware.txt`.
- The ESP32-C6-MINI-1 footprint: CC-BY-SA 4.0 from
  [espressif/kicad-libraries](https://github.com/espressif/kicad-libraries),
  `vendor/LICENSE-espressif-kicad-libraries.md`.

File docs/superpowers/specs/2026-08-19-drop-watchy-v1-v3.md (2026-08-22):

# Drop Watchy V1.0, V1.5 and V3 Support

**Date:** 2026-08-19
**Status:** accepted

## Problem

The firmware supports five boards: Watchy V1.0, V1.5, V2.0 (ESP32), V3
(ESP32-S3), and this repo's own ESP32-C6-MINI-1 design in `board-files/`.
Three of those five are dead weight:

- **V1.0 and V1.5** cost `board.h` a three-way `#if` over the up button and the
  battery tap, and cost `RefRtc` a whole second driver — the DS3231, fitted
  only to V1.0, with its own BCD decode, register write and probe. V1.5 ships
  the same PCF8563 as V2.0, so it buys nothing at all beyond a `#if` in
  `RefClock::boardRevision()` to tell the two apart.
- **V3** is a stock ESP32-S3 dev board target that this repo's own C6 board has
  superseded. It carries its own pin map, its own `RefRtc` branch for the S3's
  internal clock, and it is the flag guarding two blocks that the C6 actually
  needs.

None of the five has ever been run on hardware — see the README's *Known
limitations* — so the three being removed are untested code carrying untested
branches.

The V3 flag also masks two live defects on the C6:

1. `RefPanel::begin()` calls `SPI.begin(SCK, MISO, MOSI, SS)` under
   `#ifdef ARDUINO_ESP32S3_DEV`. The C6's SPI pins are 15/23/14/8, not the
   default bus, so the C6 needs that call and does not get it. The panel would
   not talk.
2. `RefCounter.ino`'s deep-sleep block and `RefRtc::begin()` both branch on the
   S3 flag, so removing V3 without touching them changes C6 behaviour by
   accident.

## Decision

Remove V1.0, V1.5 and V3. The supported set becomes:

| Board | Env | SoC | RTC |
| --- | --- | --- | --- |
| Watchy V2.0 | `watchy_v2` (default) | ESP32 | PCF8563 @ 0x51 |
| This repo's board | `watchy_c6` | ESP32-C6-MINI-1 | RV-3028-C7 (see *Known gap*) |

## Requirements

1. **Envs.** `[env:watchy_v10]`, `[env:watchy_v15]` and `[env:watchy_v3]` are
   gone from `platformio.ini`. `watchy_v2` stays the default env; `watchy_c6`
   keeps its pinned pioarduino platform.

2. **Pin maps.** `board.h` holds exactly two: the C6 map under
   `ARDUINO_ESP32C6_DEV` and the V2.0 map under everything else. The V2.0 map
   is unconditional — `PIN_BTN_UP 35`, `PIN_BATT_ADC 34` — with no
   per-revision `#if`.

3. **Retired flags fail the build.** `-D ARDUINO_WATCHY_V10`,
   `-D ARDUINO_WATCHY_V15` and `-D ARDUINO_ESP32S3_DEV` must each stop the
   compile with a message naming the supported envs. They must *not* fall
   through to the V2.0 map: on that hardware the battery would be read off the
   wrong pin and the up button would never be seen, and an S3 has no GPIO 26 or
   35 at all. The exact text:

   ```
   Watchy V1.0, V1.5 and V3 are no longer supported; build watchy_v2 or watchy_c6
   ```

   `ARDUINO_ESP32S3_DEV` matters most here, because it comes from the board
   choice rather than from a build flag a user typed.

4. **RTC kinds.** `RefRtc::Kind` becomes `{NONE, PCF8563}`. `DS3231` goes with
   V1.0 and `INTERNAL` — the S3's own 32kHz-backed clock — goes with V3.

5. **The C6 keeps the blocks it needs.** Every `ARDUINO_ESP32S3_DEV`
   conditional is resolved deliberately, not deleted wholesale:
   - `RefPanel::begin()`'s `SPI.begin(...)` becomes `#ifdef ARDUINO_ESP32C6_DEV`
     — a fix, not a rename: the C6 needs it and never had it.
   - `RefCounter.ino`'s `rtc_gpio_*` deep-sleep block becomes
     `#ifdef ARDUINO_ESP32C6_DEV`, keeping today's behaviour for both boards.
   - `RefRtc::begin()`'s `INTERNAL` branch is deleted, so the C6 probes I2C
     like V2.0 does.

6. **Board identity.** `RefClock::boardRevision()` returned 10/15/20/30 and the
   About screen printed it as `v2.0`. Two boards remain and one of them has no
   revision number, so the number is replaced by a name: `board.h` defines
   `BOARD_NAME` as `"V2.0"` or `"C6"`, the About screen prints it directly, and
   `boardRevision()` and its `esp_chip_info` probe are deleted.

7. **Docs match.** `README.md` and `settings.h` carry no instructions, pin
   numbers, drift figures or chip references for V1.0, V1.5 or V3. The C6 stops
   being described as "a fifth env … ignore it" and becomes one of the two
   supported targets.

8. **Tests.** The host suite pins both surviving pin maps and both `BOARD_NAME`
   values, pins the surviving `RefRtc::Kind` values, and proves each retired
   flag is rejected with the message from requirement 3. The C6 map has never
   had a test — `board.h` says so itself — and gets one here.

## Known gap — the C6 has no RTC driver

> **Closed 2026-08-19**, after this spec's work landed. `RefRtc` now drives the
> RV-3028-C7 at 0x52 and a C6 build keeps time. The section is left as written
> because it is what the removal was scoped against; read it as history.

The C6 board carries an RV-3028-C7 at 0x52. `RefRtc` has never known about it:
today the C6 build probes for a DS3231 and a PCF8563, finds neither, and lands
on `Kind::NONE`, which means no timekeeping at all. That is the state before
this work and the state after it.

It is called out here because after this change the C6 is one of only two
supported boards, so the gap is more visible — but adding a driver is a
feature, not part of a removal, and it is **out of scope for this spec**. It
wants its own spec and plan.

## Out of scope

- The RV-3028-C7 driver, per above.
- `board-files/` — the hardware design is untouched.
- Existing plan and spec documents under `docs/superpowers/` are historical
  records of work already done and are not rewritten.
- No runtime behaviour changes for V2.0 or C6 beyond the `SPI.begin()` fix in
  requirement 5, which is a bug fix the removal forces into the open.

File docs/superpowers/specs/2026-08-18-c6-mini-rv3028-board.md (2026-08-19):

# C6-MINI-1 + RV-3028-C7 Watchy Board — Design

> Renamed from `2026-08-18-s3-mini-rv3028-board.md`. The design started on an
> ESP32-S3-MINI-1 and moved to an ESP32-C6-MINI-1; the reasoning is in D1.

Status: draft, pending review
Date: 2026-08-18
Derived from: sqfmi/watchy-hardware `v2.0` branch (KiCad 5, MIT, OSHWA certified)

## Purpose

A Watchy-compatible board that pairs V3's silicon with V2's independent
timekeeping, drops the parts this project never uses, and lands on USB-C.

The ref counter needs three things the shipping revisions each get half right:

- **Time that survives without WiFi.** V3 deleted the external RTC and made the
  ESP32-S3's own 32kHz domain the only clock. A crash, a brownout or a bad OTA
  loses the time, and drift is bounded only by how often NTP is reachable. V2
  keeps a PCF8563 that counts through all of it.
- **Modern silicon.** The ESP32-PICO-D4 in V2 is old, and V2 spends ~$2 and 25
  solder joints on a CP2102 that an S3 does not need.
- **No accelerometer.** `ENABLE_ACCELEROMETER` is `false` in `settings.h` and
  `RefMenu.cpp` documents why: nothing on a play clock reads a sensor. The
  BMA423 is a part we pay for, place, and never power.

## Decisions

### D1 — ESP32-C6-MINI-1 module, not a bare chip

The module carries the 40MHz crystal, flash, RF matching and antenna, and it
comes with FCC/CE modular certification. A bare chip means designing an RF
front end and paying for standalone radio certification if the board is ever
sold. The module costs roughly $1 more than the bare part and removes the
single largest respin risk in the project.

`ESP32-C6-MINI-1-N4` (4MB embedded quad flash) or `-H8` for 8MB. There is no
PSRAM variant to get wrong, unlike the S3-MINI-1's `-N4R2`.

**This was an ESP32-S3-MINI-1 until the pin budget was re-counted.** The S3
fits comfortably and would still work. Two things moved the decision:

- **Size.** The C6-MINI-1 is 13.2 x 16.6mm against the S3-MINI-1's
  15.4 x 20.5mm -- 219mm^2 against 316mm^2, **31% less module** on a board
  where routing congestion, not board area, is the binding constraint. On the
  layout that reclaims 4.3mm of full-width board directly above `J1`, which is
  exactly where the density was worst.
- **Headroom.** The C6 brings out 22 GPIO against this design's 17, so five
  stay spare -- including both UART0 pads.

An ESP32-C3-MINI-1 was costed too and **does not fit**: it brings out only 15
GPIO, and the deep-sleep and ADC1 constraints consume IO0-IO5 exactly, leaving
seven pins for ten signals. Making it fit means tying `EPD_CS` low and giving
up an independent panel reset. The C6 is the same physical size for none of
that, and it keeps `esp_sleep_enable_ext1_wakeup` with `ESP_EXT1_WAKEUP_ANY_LOW`,
which the C3 drops in favour of a different API.

What the C6 gives up against the S3: a single RISC-V core at 160MHz instead of
two Xtensa cores at 240MHz, and 4MB of flash instead of 8MB on the recommended
part. Neither binds this workload -- the app partition is 3MB and the watch is
asleep almost always.

### D2 — RV-3028-C7, not the PCF8563 V2 uses

| | PCF8563 (V2) | RV-3028-C7 |
| --- | --- | --- |
| Accuracy | ~±20ppm, set by an external crystal and its load caps | ±1ppm, factory trimmed |
| Drift | ~1 min/month | ~30 s/year |
| Current | ~250nA | ~40nA |
| External crystal | required (Y1, plus the load-cap matching that sets the ±20ppm) | integrated |
| Cost | ~$0.60 + crystal | ~$2.50-3.50 |

Paying ~$2 to go from a minute a month to half a minute a year is the best
value on the board, because it is the whole reason this variant exists. It
also deletes a part (the crystal) and the tuning problem that comes with it.

The PCF8563 remains a valid fallback if the RV-3028 cannot be sourced: it is
pin-incompatible but functionally equivalent, and `RefRtc` already speaks it.

### D3 — RTC powered from +BATT, backup switchover unused

`VDD` to `+BATT`, `VSS` and `VBACKUP` to `GND`, `EVI` to `GND`. This is what
V2 already does with the PCF8563 and it keeps the clock alive independently of
the LDO.

**The I2C and INT pull-ups go to +3V3, not +BATT.** With `VDD` at up to 4.2V
the RV-3028's `VIH` is 0.7 x VDD = 2.94V, which a 3.3V bus clears, while the
S3's inputs never see more than 3.3V. Pulling the bus up to +BATT instead would
put 4.2V on S3 pins. This is the one place on the board where the obvious
simplification is wrong.

`VBACKUP` is deliberately **not** fed from +BATT. In direct switching mode the
part runs from whichever supply is higher and disables SDA (high impedance) in
the backup power state, which would break I2C on a board whose battery is
always the highest rail. If a supercap is ever added, `VBACKUP` is where it
goes.

### D4 — Buttons active-low on RTC GPIOs, nothing on a strapping pin

V1-V2 buttons are active-high because the original ESP32's `ext1` deep-sleep
wake only supports `ALL_LOW` or `ANY_HIGH`; waking on any of four buttons
forced `ANY_HIGH` and external pull-downs. The S3 adds
`ESP_EXT1_WAKEUP_ANY_LOW`, so this board uses active-low buttons with internal
pull-ups, and **the RTC interrupt joins the same `ext1` mask** — one wake
source configuration for five wake reasons, read back from the wake status.

V3 puts UP on GPIO0, the strapping pin: a held or dirty button at reset drops
the watch into the bootloader instead of the watchface. This board does not put
any button on a strapping pin. GPIO0 gets a 10k pull-up to +3V3 and a test pad,
so download mode is still forceable with a jumper.

### D5 — No 32.768kHz crystal

V2 feeds the PCF8563's CLKOUT into the ESP32 as its external 32kHz slow clock
through an attenuator (R11/R19). That whole block is deleted. With the wake
source being the RTC's own alarm and the time read over I2C on every wake, the
S3's slow-clock accuracy no longer matters — it can run on the internal RC.
This removes a part and the entire class of "firmware selected the wrong RTC
clock source and the watch drifts 5%" failures.

`CLKOUT` goes to a test pad, unloaded.

### D6 — USB-C, native USB, no bridge

USB-C 16-pin receptacle. **Two 5.1k CC pulldowns, one per CC pin** — without
them a C-to-C cable delivers no power at all, which is the single most common
failure in this swap. `D+`/`D-` to IO20/IO19, which is fixed by the silicon.
USBLC6-2P6 for ESD.

The CP2102 and the UMH3N auto-reset pair are deleted. The S3's USB-Serial/JTAG
is in ROM, so esptool can drive download mode over USB without strapping.

What is given up: the serial port now only exists while firmware runs. V2's
TX/RX/GND test points are kept so a $3 USB-serial dongle recovers a console
when firmware is wedged.

### D7 — Battery divider raised to 1M/1M

V2 uses two 100k, which draws 4.2V/200k = 21uA continuously — about 15mAh a
month out of a 200mAh cell, or 7.5% of the battery to measure the battery.
1M/1M with a 100nF cap at the tap draws 2.1uA for the same 2:1 ratio.

The ratio is unchanged on purpose: firmware's `BATT_DIVIDER 2.0f` stays
correct. The cost is source impedance — the ADC must discard its first reading
after the mux settles.

### D8 — Mechanical envelope preserved

Board outline, display position, button positions, battery connector and
mounting features stay exactly where V2 puts them, so existing cases fit. The
USB-C cutout is the only mechanical change, and the case work is tracked
separately in `2026-08-18-waterproof-case-design.md`.

**Dimension conflict — resolved by measurement.** The Edge.Cuts outline in
V2's `Watchy.kicad_pcb`, measured with `pcbnew`, is **33.800 x 45.960mm** on
the centreline (33.950 x 46.110mm including the 0.15mm line width). sqfmi's
published figure, and the waterproof case spec, both say **35.5 x 46.0mm**;
that figure does not describe this outline. The case model should be worked
against 33.800 x 45.960mm, and
`2026-08-18-waterproof-case-design.md` needs correcting.

### D9 — Four layers

V2 is 2-layer, 1.6mm. This board goes to 4 (signal / GND / +3V3 / signal). The
MINI-1's 65 pads plus its antenna keepout make a solid reference plane worth
the ~$1-2 per board at quantity 25, and V3 made the same call for the same
reason. Thickness stays 1.6mm so the case stack is unchanged.

### D10 — No UART console

There are no `TP_TX`/`TP_RX` pads and no UART0 connection. The C6's USB
Serial/JTAG controller carries the console, flashing and automatic download
mode over `USB_DP`/`USB_DM` with no external bridge, and `TP1` on IO9 forces
download mode by hand if firmware ever misconfigures USB.

The cost is real and worth writing down: **the USB controller powers down in
deep sleep**, so nothing prints across a sleep/wake cycle -- which is the
behaviour this watch is mostly made of. UART would have survived that. It was
dropped because the two nets cost 78mm of copper, 11.3% of all signal routing,
to reach test pads 30mm away from the module, and the board could not afford
it. IO16 and IO17 are left unconnected precisely so a console can be soldered
back on without moving a signal.

## Bill of material changes from V2

**Deleted:** U1 ESP32-PICO-D4, U3 CP2102, U4 BMA423, U6 PCF8563BS, Y1 32.768kHz
crystal, AE1 SWRA117D chip antenna, Q2 UMH3N auto-reset pair, J2 Micro-USB, the
CLKOUT attenuator (R11 680k, R19 100k), and the BMA423's decoupling.

**Added:** U1 ESP32-S3-MINI-1, U6 RV-3028-C7, J2 USB-C 16-pin receptacle,
2x 5.1k CC pulldowns, USBLC6-2P6 ESD array, 10k GPIO0 pull-up, 100nF ADC filter.

**Changed:** battery divider 100k/100k to 1M/1M.

**Unchanged, carried over verbatim:** the entire e-paper block (FPC24, the
L1/Q1/D1-D4/R9 boost and its VGH/VGL/VCOM capacitors), the TP4054 charger with
its PROG resistor and status LED, the CJ2301 + MBR0530 VBUS/battery OR-ing, the
ME6211C33M5G-N LDO, the S8050 vibration motor driver with its 1N4001 flyback,
the JST battery connector, and the four tactile switches.

Net effect: roughly $6-9 per board cheaper than V2 and ~7 fewer placements,
while keeping a better clock than either shipping revision.

## Pin map

Authoritative. Pad numbers are from the ESP32-C6-MINI-1 datasheet v1.5,
Table 3-1. The module has 53 pads; GND is 1, 2, 11, 14 and 36-53, and pads
4, 7, 21 and 32-35 are NC.

Three datasheet facts fix most of this map, and none are guessable from the
pin names:

- **IO0-IO7 are the only deep-sleep wake pins** (LP_GPIO0-7). Everything else
  can only wake the chip from light sleep. Four buttons plus `RTC_INT` take
  five of the eight.
- **IO0-IO6 are the only ADC1 channels.** There is no usable second ADC while
  WiFi is running.
- **IO9 must be high when reset is released** or the chip boots into download
  mode (Table 4-3). IO8 is `Any value` for SPI boot, so it is an ordinary pin.

Those eight wake/ADC pins are all on the module's left column and the left
half of its bottom row, which is why the buttons and the RTC sit there and
everything else is further right.

| Net | GPIO | Pad | Constraint |
| --- | --- | --- | --- |
| `BTN_UP` (top right) | IO2 | 5 | LP GPIO, `ext1` wake, active low |
| `BTN_DOWN` (bottom right) | IO3 | 6 | LP GPIO, `ext1` wake, active low |
| `RTC_INT` | IO4 | 9 | LP GPIO, `ext1` wake, open drain + 10k to 3V3 |
| `BATT_ADC` | IO5 | 10 | **ADC1_CH5** |
| `BTN_MENU` (bottom left) | IO0 | 12 | LP GPIO, `ext1` wake, active low |
| `BTN_BACK` (top left) | IO1 | 13 | LP GPIO, `ext1` wake, active low |
| `SCL` | IO6 | 15 | 4.7k to +3V3 |
| `SDA` | IO7 | 16 | 4.7k to +3V3 |
| `USB_DM` | IO12 | 17 | fixed by silicon |
| `USB_DP` | IO13 | 18 | fixed by silicon |
| `EPD_MOSI` | IO14 | 19 | pad order = FPC order (see below) |
| `EPD_SCK` | IO15 | 20 | pad order = FPC order |
| `EPD_CS` | IO8 | 22 | pad order = FPC order |
| `TP_BOOT` | IO9 | 23 | strapping; 10k to +3V3, test pad only |
| `EPD_DC` | IO18 | 24 | pad order = FPC order |
| `EPD_RST` | IO19 | 25 | pad order = FPC order |
| `EPD_BUSY` | IO20 | 26 | pad order = FPC order |
| `VIB_PWM` | IO21 | 27 | LEDC |
| `EN` | — | 8 | 10k to +3V3, 100nF to GND, test pad |

IO16, IO17, IO22 and IO23 are unconnected. IO16/IO17 are the UART0 pads: this
board has no serial console (see D10), and those two are where one would go
back if it ever needs one.

`RTC_INT` on IO4 and `BATT_ADC` on IO5 are also latched at reset, as MTMS and
MTDI, but those only select the SDIO sampling clock edge and this design has
no SDIO. IO15 is latched as the JTAG source select, and Table 4-7 makes it
`Ignored` unless `EFUSE_JTAG_SEL_ENABLE` is burnt, which it is not.

### The six display pins are ordered for the layout

The panel's FPC pinout is fixed. Reading `J1` left to right the display
signals arrive in the order MOSI, SCK, CS, DC, RST, BUSY. The six signals are
assigned to the six live module pads that run in that same direction --
19, 20, 22, 24 along the bottom row, then 25 and 26 up the right column --
so the fan-out is planar: six parallel tracks, no crossings.

Pad 21 is NC, so it is a gap with no copper rather than an obstacle. Pad 23 is
IO9, which has to carry `TP_BOOT` because it is the only pin that decides boot
mode; it sits in the middle of the fan and costs one via to drop the net onto
an inner layer and out from under the bundle, but it does not cost a crossing.

This is worth stating as a rule because getting it wrong is invisible. A
mis-ordered fan-out is not a DRC error and not a netlist error -- it just
quietly makes three or four of these nets unroutable. On the earlier S3
layout `EPD_MOSI` sat fourth along the module but landed first at the
connector, so it had to cross SCK, CS and DC in the densest corner of the
board, and three of the seven nets the router could not place were in that
bundle. `checks/netlist_check.py` now asserts the order directly, under
`display fan-out order`.

**Stock Watchy firmware compatibility is gone, deliberately.** It went when
the module changed: a C6 has no IO33-IO48 to match V3 with. `RefCounter/board.h`
under `ARDUINO_ESP32C6_DEV` is the authoritative map.

## Firmware impact — out of scope here, do not implement

This spec covers the board only. The firmware follow-up is a separate plan:

- `RefRtc::begin()` short-circuits to `INTERNAL` on any S3 build
  (`RefRtc.cpp:57-61`). That must become an I2C probe, with `INTERNAL` as the
  fallback when nothing answers.
- `RefRtc` needs an `RV3028` kind: address 0x52, BCD time at registers
  0x00-0x06, status/control at 0x0E-0x10.
- `RefClock.cpp:196` assumes "an S3 here means V3" for the drift budget. That
  must key off the detected chip, not the SoC.
- `board.h` needs a revision block for this board.
- The battery divider's 1M source impedance (D7) means the ADC must discard
  its first reading after the mux settles. `BATT_DIVIDER` stays `2.0f`; only
  the sampling changes.
- The `ext1` wake mask must gain `RTC_INT` alongside the four buttons, and the
  wake handler must clear the RTC alarm flag over I2C before sleeping again —
  the interrupt is level-triggered and stays asserted until cleared, so a
  missed clear means the watch wakes in a loop until the battery is flat.

## Risks

- **Nothing here can be verified without fabricating a board.** DRC and
  netlist checks prove the design is self-consistent; they prove nothing about
  whether it works. No task may claim otherwise.
- **There is no ERC and there cannot be one.** `kicad-cli sch erc` reads a
  `.kicad_sch`, and this design has none -- it is atopile source compiled
  straight to a netlist. Driven-output conflicts and unconnected pins are
  caught only insofar as `checks/netlist_check.py` happens to assert them.
  That is a standing cost of defining the design in code, and it is the one
  place where the GUI workflow this spec rejected is genuinely ahead.
- **The RV-3028-C7 footprint is not in KiCad's standard library.** It has to be
  sourced from Micro Crystal or drawn from the datasheet and checked against a
  1:1 print before fab.
- **The MINI-1 antenna keepout** must overhang the board edge with no copper,
  no plane and no traces beneath it, on all four layers. The consequence is
  that the module hangs about 5mm off the top edge of the PCB: only 15.5mm of
  its 20.8mm length is over board. The case has to accommodate a part that
  overhangs the board it is mounted on.
- **KiCad 5 to modern conversion** is one-way. The V2 files are imported into a
  new project; the upstream repo is never modified.

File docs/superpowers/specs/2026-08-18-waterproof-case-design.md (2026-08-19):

# Waterproof Case for Watchy — Design

Status: approved in principle, pending final spec review
Date: 2026-08-18
Target hardware: Watchy V3 (ESP32-S3), modelled on documented V2 geometry
with a USB-C port substituted for micro-USB.

## Purpose

The ref counter is used outdoors, on a field, in whatever weather the game is
played in. sqfmi lists the stock Watchy's waterproof rating as "No" — it is
open at the buttons and at the port. This design replaces the stock case with
a sealed enclosure that survives rain, sweat and wet hands for the length of a
game, and that can still be opened to charge and service the watch.

## Protection target

**IPX4-IPX5.** Splashing and low-pressure jets from any direction: heavy rain,
a sideline downpour, a wet towel, a rinse under a tap.

**Not IPX7/IPX8.** The case is not rated for submersion and must not be worn
swimming. A submersion rating would require potting the electronics, which
makes the watch unserviceable and unchargeable — an unacceptable trade for a
device whose battery is its consumable.

FDM prints are porous between layers under sustained pressure. The print
settings in the case README mitigate this but do not eliminate it; the rating
above assumes those settings are followed.

## Reference dimensions

The V3 board's mechanical drawings are not published — sqfmi's
`watchy-hardware` repository carries no ESP32-S3 files and `watchy-cases`
ships STEP bodies without a dimension table. Per direction, the model is built
against documented V2 geometry with USB-C assumed in place of micro-USB.

| Quantity | Value | Confidence |
| --- | --- | --- |
| PCB | 33.80 x 45.96mm | **Measured** — see below |
| PCB thickness | 1.6mm | Published |
| Stock assembled watch | 34 x 46 x 9mm, 18g | Published |
| Display | 1.54", 200x200 | Published |
| Battery | 200mAh, 3.7V | Published |
| Battery thickness | ~3.0mm | Derived from the 9mm stack |
| Button positions | Display corners, side-actuated | User-confirmed |
| USB-C opening | 9.0 x 3.2mm | Connector standard |

The 46mm PCB length includes integral strap-lug tabs. Those tabs sit *inside*
the sealed volume — the case provides its own lugs — which is why the case is
appreciably longer than it is wide.

### The width figure is settled, and it was not 35.5mm

The published 35.5 x 46.0mm was never measured; it was taken from sqfmi's
listing. The Edge.Cuts outline of the board this case is for has since been
measured with `pcbnew`: **33.800 x 45.960mm** on the centreline, 33.950 x
46.110mm including the 0.15mm outline width. The assembled watch being listed
at 34mm is the figure consistent with that; the 35.5mm one is not.

Build the pocket against 33.80 x 45.96mm. That is 1.7mm narrower than this
document previously assumed, so a pocket cut to the old figure is loose
rather than tight — foam takes it up, but the lugs and the USB-C opening
shift with it and those do not.

### The buttons are all at V2's positions after all

An earlier revision of this design moved `SW2` -- the BACK button -- 0.2mm up
the board, and this section used to say the case had to follow. It does not.
The move has been reverted and all four buttons sit exactly where V2 has them.

The reason it was needed is worth keeping, because it constrains any future
change in this corner. The USB-C receptacle's shield tabs are through-hole and
stick out past the housing, and the battery connector `J3` had a mounting pad
sitting *on* one -- 0.067mm of overlap, which is a short, not a tight
clearance. `J3` is pinched between that tab and this button, in a corridor of
5.430mm, and `J3` is 5.082mm long. At the 0.2mm copper clearance the board
used to carry it needed 5.482mm and did not fit, so the button gave up the
difference. The board now runs 0.15mm rules, where it needs 5.382mm and fits
with 0.174mm at each end, so `J3` alone carries the fix -- it sits 0.241mm up
the board from V2, and nothing case-facing has moved.

**No dimension in this document changes.** The section is kept because the
corridor is now spoken for to within 0.05mm: anything that widens `J3`, moves
`SW2`, or takes the copper clearance back to 0.2mm puts the shield tab back on
the battery connector.

### Superseded: SW2 moved 0.2mm, and the case must follow

`SW2` -- the BACK button -- sits at (100.57, 79.73) in board coordinates,
0.2mm further up the board than V2 put it.

The reason is copper, not ergonomics. The USB-C receptacle's shield tabs are
through-hole and stick out past its housing, and the receptacle is 9.04mm wide
in a 9.15mm gap. Left where V2 had them, the battery connector `J3` and the
charger `U5` both had a pad sitting *on* a tab -- 0.067mm and 0.120mm of
overlap, which is a short rather than a tight clearance. `U5` moved down 0.45mm
and `J3` up 0.28mm to clear them, but `J3` is pinched between the tab and this
button and the corridor was 0.05mm too narrow to fit it with clearance at both
ends, so the button yielded the difference.

0.2mm is far inside any FDM case tolerance and inside the pusher travel, so no
dimension in this document changes. It is recorded because it is a real
mechanical change to a case-facing part, and because the button positions in
the constraint table above are marked *User-confirmed* -- if those positions
were measured off a physical stock case rather than off the board, this is the
one that no longer matches.

### The board no longer has strap slots

V2 cut two 2 x 28mm slots through the PCB, at y 72.15–74.15 and 111.61–114.11
in board coordinates, for the strap to pin through. This board does not have
them: they ran directly under the module and its decoupling, and they were
removed rather than move the module (`board-files/README.md`, "Board
outline").

**The case must therefore carry the entire strap attachment.** There is no
longer anything on the PCB for a spring bar or a pin to pass through, and
nothing to take the load. The lugs, and whatever anchors them to the sealed
body, are now the only mechanical path between the watch and the band. The
20mm spring-bar lugs in the parts list below already assume case-mounted
lugs, so the design does not change -- but it is no longer a choice, and a
case that relied on the board's slots would have nothing to grip.

Everything above is tagged in `params.scad` as `PUBLISHED`, `DERIVED` or
`ESTIMATED`. The derived and estimated values must be confirmed with calipers
before committing to a full print.

## Architecture

**The case splits horizontally through the button axis.** This is the decision
everything else follows from.

Because the buttons are pressed inward from the side edges, a split at that
height puts every button on the parting line. The consequence is that the
gasket and the button seals become *one part*: a single planar TPU gasket with
a perimeter sealing bead that detours outward into a dome at each of the four
button stations. The seal line stays continuous — bead, bead, dome, bead — and
the domes are simply local excursions of it.

That matters for two reasons. It gives a continuous elastomer boundary with no
joints between separate sealing elements, which is stronger than two seals in
series. And it costs one land in the flange instead of two, which is worth
about 9mm across the watch — the difference between a large watch and an
unwearable one.

Rigid shells were chosen over an all-TPU tub because TPU shrinks
unpredictably and its screw bosses pull through under clamp load. Only the
gasket is soft, and it is the one part whose dimensions are forgiving.

O-ring pushrod buttons were rejected: four sliding seals in FDM bores are four
leak paths, and the dome removes the through-hole entirely.

## Sealing

Four paths water can take in. Each is closed independently.

| Path | Closure |
| --- | --- |
| Parting line | 1.5mm bead on the TPU gasket, in a 1.9 x 1.1mm groove, 27% compression |
| Four buttons | Integral domes on the same gasket; pushers ride outside the boundary |
| USB-C port | Recessed well in the sidewall, tethered TPU bung; well is drained |
| Display window | 1mm clear pane bonded into an internal rabbet with RTV |

### Parting line and buttons

```
   outside                                        inside
      |                                              |
      v                                              v

              pusher (free, unsealed, in split channel)
                    |
                    v
     ==========+   ___   +===================   TOP SHELL
               |  /   \  |
        wall   | ( dome )|   <- TPU gasket, one part
               |  \___/  |
     ==========+         +===================   BOTTOM SHELL
                    ^
                    |
            bead in 1.9 x 1.1 groove
            (the dome is a local outward
             excursion of the same bead line)

   shells bottom out flange-to-flange: compression is
   limited by a hard stop, not by screw torque
```

Groove cross-section is 2.09mm2 against a 1.767mm2 bead, leaving 18% room for
displaced material, so the bead is not extruded out of the groove when the
screws are driven. Compression is (1.5 - 1.1) / 1.5 = 27%, inside the 20-30%
band an elastomer wants for a static face seal. At full torque the two flanges
meet, so the gasket cannot be crushed however hard the screws are tightened.

Each printed pusher rides in a half-round channel split between the two
shells, and presses the dome, which presses the tact switch. The pusher lives
entirely outside the sealed boundary. Water in its channel is stopped by the
dome and drains back out of the channel mouth.

### Port

The USB-C opening sits at the bottom of a recessed well, so water running down
the case does not pool at the connector. The well drains through a slot in its
lower lip. A TPU bung, tethered to the case so it cannot be lost on a field,
closes the well.

### Window

The e-paper module is not itself waterproof — its glass front terminates in an
FPC ribbon. A 1mm clear pane is bonded from the inside into a rabbet in the
top shell with neutral-cure RTV, and the display sits behind it on a
closed-cell foam spacer that holds it against the pane and takes up stack
tolerance. Bonding the pane rather than the display keeps the display
removable.

## Battery

The pocket depth is parametric, with two rendered variants.

| Variant | Pocket | Cell | Case thickness |
| --- | --- | --- | --- |
| `standard` | 3.5mm | Stock 200mAh | ~12mm |
| `extended` | 6.0mm | ~400-500mAh | ~14mm |

Thickness budget, standard variant:

| Layer | mm |
| --- | --- |
| Bottom shell floor | 1.8 |
| Battery pocket | 3.5 |
| PCB | 1.6 |
| Components above PCB to display glass | 2.0 |
| Foam spacer | 0.8 |
| Clear pane | 1.0 |
| Top shell over pane | 1.2 |
| Total | 11.9 |

The extended variant adds 2.5mm to the pocket and nothing else. Since a sealed
case is one you want to open as rarely as possible, roughly doubling runtime
for 2mm of thickness is a good trade — but both are built, and the choice is a
build target rather than an edit.

## Size

| | Stock | This case |
| --- | --- | --- |
| Width | 34mm | ~43mm |
| Length | 46mm | ~53mm |
| Thickness | 9mm | ~12mm / ~14mm |

Per side the flange costs 0.3mm of board clearance plus a 3.4mm sealing land.
Sealing a 35.5 x 46mm board costs roughly 7mm in each in-plane direction and
there is no way around it that does not compromise the seal. This is a large
watch — chunky G-Shock territory. That is a deliberate, stated cost of the
protection target, not an oversight.

## Ergonomics

The four buttons do not have equal roles in this firmware, and the case should
reflect that. From the control map in the repo README:

| Button | Role | Pusher |
| --- | --- | --- |
| Top right | Long clock (40s) | Wide, 1.5mm proud |
| Bottom right | Short clock (25s) | Wide, 1.5mm proud |
| Top left | Sleep | Narrow, flush |
| Bottom left | Menu / clear | Narrow, flush |

The two clock buttons are found and pressed mid-play, possibly with gloves, so
they are large and stand proud of the wall. Sleep and menu are setup-time
controls whose accidental activation during a drive would be costly, so they
sit flush with the wall and need a deliberate fingertip. This asymmetry is the
reason to build a case for this firmware rather than print a generic one.

## Parts

Printed rigid (PETG or ASA):

- `shell_bottom` — tub, battery pocket, PCB standoffs, gasket groove, port well, lugs
- `shell_top` — bezel, window rabbet, gasket land, screw counterbores, lugs
- `pusher` x4 — two wide, two narrow

Printed TPU:

- `gasket` — one part: perimeter bead plus four integral button domes
- `port_bung` — tethered

Bought:

- 6x M2x10 socket head screws
- 6x M2 heat-set inserts, 3.2mm OD, 4.0mm long
- 1mm clear acrylic or PET pane, cut to the rabbet
- Closed-cell foam sheet, ~1mm
- Neutral-cure RTV silicone
- Extended variant only: one 400-500mAh LiPo with a 1.25mm 2-pin connector

Six screws rather than four: the sealing perimeter is about 190mm, and four
screws would leave 48mm spans between clamping points, which is too far to
hold even compression in a printed flange. Six gives roughly 32mm spacing.
The count is parametric.

## Repository layout

```
case/
  params.scad          every dimension, hardware vs design, tagged for confidence
  case.scad            top level; renders one part, selected by -D part="..."
  lib/shapes.scad      rounded box, gasket groove, boss and insert helpers
  parts/shell_bottom.scad
  parts/shell_top.scad
  parts/pusher.scad
  parts/gasket.scad
  parts/port_bung.scad
  parts/coupon.scad
  Makefile             render targets, plus check
  README.md            print settings, assembly order, BOM, measuring worksheet
  stl/                 rendered output
```

`case.scad` dispatches on a `part` variable so every part is generated from
one consistent parameter set, and on a `battery` variable selecting the
standard or extended pocket.

## Fit-test coupon

A full case is a multi-hour print, and the derived dimensions above mean the
first one is unlikely to be right. `case.scad` renders a `coupon` part: one
corner of the enclosure carrying the PCB pocket edge, one complete button
station with its groove and dome seat, and the port well — roughly twenty
minutes of filament.

The workflow is: measure, render coupon, print, correct `params.scad`, repeat
until it fits, then print the case.

## Verification

Three levels, and it matters which claims each one supports.

**Geometry.** `make check` renders every part through CGAL and asserts the
output reports exactly two volumes — one solid plus the infinite outer volume.
Any other count means the part is non-manifold or has split into pieces, and
the build fails. This proves each part is printable geometry.

**Consistency.** `params.scad` carries `assert()` calls for the relationships
that must hold: groove shallower than the flange, insert shorter than its
boss, button stations clear of the screw bosses, PCB pocket larger than the
PCB by the stated clearance, dome excursion inside the flange width. These
catch a parameter edit that silently breaks the design.

**Fit.** The coupon print, against the actual watch. Nothing in the software
toolchain substitutes for this.

To be explicit about the limits: the first two confirm the model compiles to
closed, printable solids with self-consistent parameters. They cannot confirm
the case fits a Watchy, that the parting line seals, or that the print is
watertight. Those are physical claims, and they need the coupon and a hose
test.

## Out of scope

- Any submersion rating
- A strap: standard 20mm spring-bar lugs, use a commercial strap
- Pressure equalisation venting, which IPX4-5 does not require
- Wireless charging

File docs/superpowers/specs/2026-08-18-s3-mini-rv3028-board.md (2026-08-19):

# S3-MINI-1 + RV-3028-C7 Watchy Board — Design

Status: draft, pending review
Date: 2026-08-18
Derived from: sqfmi/watchy-hardware `v2.0` branch (KiCad 5, MIT, OSHWA certified)

## Purpose

A Watchy-compatible board that pairs V3's silicon with V2's independent
timekeeping, drops the parts this project never uses, and lands on USB-C.

The ref counter needs three things the shipping revisions each get half right:

- **Time that survives without WiFi.** V3 deleted the external RTC and made the
  ESP32-S3's own 32kHz domain the only clock. A crash, a brownout or a bad OTA
  loses the time, and drift is bounded only by how often NTP is reachable. V2
  keeps a PCF8563 that counts through all of it.
- **Modern silicon.** The ESP32-PICO-D4 in V2 is old, and V2 spends ~$2 and 25
  solder joints on a CP2102 that an S3 does not need.
- **No accelerometer.** `ENABLE_ACCELEROMETER` is `false` in `settings.h` and
  `RefMenu.cpp` documents why: nothing on a play clock reads a sensor. The
  BMA423 is a part we pay for, place, and never power.

## Decisions

### D1 — ESP32-S3-MINI-1 module, not a bare ESP32-S3FN8

The module carries the 40MHz crystal, flash, RF matching and antenna, and it
comes with FCC/CE modular certification. A bare chip means designing an RF
front end and paying for standalone radio certification if the board is ever
sold. The module costs roughly $1 more than the bare part and removes the
single largest respin risk in the project.

`ESP32-S3-MINI-1` (embedded 8MB quad flash, no PSRAM). **Not** the `-N4R2`
variant: that one uses IO26 for PSRAM.

### D2 — RV-3028-C7, not the PCF8563 V2 uses

| | PCF8563 (V2) | RV-3028-C7 |
| --- | --- | --- |
| Accuracy | ~±20ppm, set by an external crystal and its load caps | ±1ppm, factory trimmed |
| Drift | ~1 min/month | ~30 s/year |
| Current | ~250nA | ~40nA |
| External crystal | required (Y1, plus the load-cap matching that sets the ±20ppm) | integrated |
| Cost | ~$0.60 + crystal | ~$2.50-3.50 |

Paying ~$2 to go from a minute a month to half a minute a year is the best
value on the board, because it is the whole reason this variant exists. It
also deletes a part (the crystal) and the tuning problem that comes with it.

The PCF8563 remains a valid fallback if the RV-3028 cannot be sourced: it is
pin-incompatible but functionally equivalent, and `RefRtc` already speaks it.

### D3 — RTC powered from +BATT, backup switchover unused

`VDD` to `+BATT`, `VSS` and `VBACKUP` to `GND`, `EVI` to `GND`. This is what
V2 already does with the PCF8563 and it keeps the clock alive independently of
the LDO.

**The I2C and INT pull-ups go to +3V3, not +BATT.** With `VDD` at up to 4.2V
the RV-3028's `VIH` is 0.7 x VDD = 2.94V, which a 3.3V bus clears, while the
S3's inputs never see more than 3.3V. Pulling the bus up to +BATT instead would
put 4.2V on S3 pins. This is the one place on the board where the obvious
simplification is wrong.

`VBACKUP` is deliberately **not** fed from +BATT. In direct switching mode the
part runs from whichever supply is higher and disables SDA (high impedance) in
the backup power state, which would break I2C on a board whose battery is
always the highest rail. If a supercap is ever added, `VBACKUP` is where it
goes.

### D4 — Buttons active-low on RTC GPIOs, nothing on a strapping pin

V1-V2 buttons are active-high because the original ESP32's `ext1` deep-sleep
wake only supports `ALL_LOW` or `ANY_HIGH`; waking on any of four buttons
forced `ANY_HIGH` and external pull-downs. The S3 adds
`ESP_EXT1_WAKEUP_ANY_LOW`, so this board uses active-low buttons with internal
pull-ups, and **the RTC interrupt joins the same `ext1` mask** — one wake
source configuration for five wake reasons, read back from the wake status.

V3 puts UP on GPIO0, the strapping pin: a held or dirty button at reset drops
the watch into the bootloader instead of the watchface. This board does not put
any button on a strapping pin. GPIO0 gets a 10k pull-up to +3V3 and a test pad,
so download mode is still forceable with a jumper.

### D5 — No 32.768kHz crystal for the S3

V2 feeds the PCF8563's CLKOUT into the ESP32 as its external 32kHz slow clock
through an attenuator (R11/R19). That whole block is deleted. With the wake
source being the RTC's own alarm and the time read over I2C on every wake, the
S3's slow-clock accuracy no longer matters — it can run on the internal RC.
This removes a part and the entire class of "firmware selected the wrong RTC
clock source and the watch drifts 5%" failures.

`CLKOUT` goes to a test pad, unloaded.

### D6 — USB-C, native USB, no bridge

USB-C 16-pin receptacle. **Two 5.1k CC pulldowns, one per CC pin** — without
them a C-to-C cable delivers no power at all, which is the single most common
failure in this swap. `D+`/`D-` to IO20/IO19, which is fixed by the silicon.
USBLC6-2P6 for ESD.

The CP2102 and the UMH3N auto-reset pair are deleted. The S3's USB-Serial/JTAG
is in ROM, so esptool can drive download mode over USB without strapping.

What is given up: the serial port now only exists while firmware runs. V2's
TX/RX/GND test points are kept so a $3 USB-serial dongle recovers a console
when firmware is wedged.

### D7 — Battery divider raised to 1M/1M

V2 uses two 100k, which draws 4.2V/200k = 21uA continuously — about 15mAh a
month out of a 200mAh cell, or 7.5% of the battery to measure the battery.
1M/1M with a 100nF cap at the tap draws 2.1uA for the same 2:1 ratio.

The ratio is unchanged on purpose: firmware's `BATT_DIVIDER 2.0f` stays
correct. The cost is source impedance — the ADC must discard its first reading
after the mux settles.

### D8 — Mechanical envelope preserved

Board outline, display position, button positions, battery connector and
mounting features stay exactly where V2 puts them, so existing cases fit. The
USB-C cutout is the only mechanical change, and the case work is tracked
separately in `2026-08-18-waterproof-case-design.md`.

**Dimension conflict — resolved by measurement.** The Edge.Cuts outline in
V2's `Watchy.kicad_pcb`, measured with `pcbnew`, is **33.800 x 45.960mm** on
the centreline (33.950 x 46.110mm including the 0.15mm line width). sqfmi's
published figure, and the waterproof case spec, both say **35.5 x 46.0mm**;
that figure does not describe this outline. The case model should be worked
against 33.800 x 45.960mm, and
`2026-08-18-waterproof-case-design.md` needs correcting.

### D9 — Four layers

V2 is 2-layer, 1.6mm. This board goes to 4 (signal / GND / +3V3 / signal). The
MINI-1's 65 pads plus its antenna keepout make a solid reference plane worth
the ~$1-2 per board at quantity 25, and V3 made the same call for the same
reason. Thickness stays 1.6mm so the case stack is unchanged.

## Bill of material changes from V2

**Deleted:** U1 ESP32-PICO-D4, U3 CP2102, U4 BMA423, U6 PCF8563BS, Y1 32.768kHz
crystal, AE1 SWRA117D chip antenna, Q2 UMH3N auto-reset pair, J2 Micro-USB, the
CLKOUT attenuator (R11 680k, R19 100k), and the BMA423's decoupling.

**Added:** U1 ESP32-S3-MINI-1, U6 RV-3028-C7, J2 USB-C 16-pin receptacle,
2x 5.1k CC pulldowns, USBLC6-2P6 ESD array, 10k GPIO0 pull-up, 100nF ADC filter.

**Changed:** battery divider 100k/100k to 1M/1M.

**Unchanged, carried over verbatim:** the entire e-paper block (FPC24, the
L1/Q1/D1-D4/R9 boost and its VGH/VGL/VCOM capacitors), the TP4054 charger with
its PROG resistor and status LED, the CJ2301 + MBR0530 VBUS/battery OR-ing, the
ME6211C33M5G-N LDO, the S8050 vibration motor driver with its 1N4001 flyback,
the JST battery connector, and the four tactile switches.

Net effect: roughly $6-9 per board cheaper than V2 and ~7 fewer placements,
while keeping a better clock than either shipping revision.

## Pin map

Authoritative. Pad numbers are from the ESP32-S3-MINI-1 datasheet v1.7,
Table 3-1. The module has 65 pads; GND is 1, 2, 42, 43 and 46-65.

| Net | GPIO | Pad | Constraint |
| --- | --- | --- | --- |
| `BTN_MENU` (bottom left) | IO4 | 8 | RTC_GPIO, `ext1` wake, active low |
| `BTN_BACK` (top left) | IO5 | 9 | RTC_GPIO, `ext1` wake, active low |
| `BTN_UP` (top right) | IO6 | 10 | RTC_GPIO, `ext1` wake, active low |
| `BTN_DOWN` (bottom right) | IO7 | 11 | RTC_GPIO, `ext1` wake, active low |
| `RTC_INT` | IO8 | 12 | RTC_GPIO, `ext1` wake, open drain + 10k to 3V3 |
| `BATT_ADC` | IO9 | 13 | **ADC1_CH8** — ADC2 is unusable with WiFi on |
| `SCL` | IO11 | 15 | 4.7k to +3V3 |
| `SDA` | IO12 | 16 | 4.7k to +3V3 |
| `VIB_PWM` | IO17 | 21 | LEDC |
| `USB_DM` | IO19 | 23 | fixed by silicon |
| `USB_DP` | IO20 | 24 | fixed by silicon |
| `EPD_SCK` | IO47 | 27 | matches V3's map |
| `EPD_CS` | IO33 | 28 | matches V3's map |
| `EPD_DC` | IO34 | 29 | matches V3's map |
| `EPD_MOSI` | IO48 | 30 | matches V3's map |
| `EPD_RST` | IO35 | 31 | matches V3's map |
| `EPD_BUSY` | IO36 | 32 | matches V3's map |
| `TP_BOOT` | IO0 | 4 | strapping; 10k to +3V3, test pad only |
| `TP_TX` | TXD0 | 39 | test pad |
| `TP_RX` | RXD0 | 40 | test pad |
| `EN` | — | 45 | 10k to +3V3, 100nF to GND, test pad |

Deliberately left unconnected: IO3, IO45, IO46 (strapping pins with the correct
internal defaults), IO15/IO16 (the XTAL_32K pair, unused per D5), and IO1, IO2,
IO10, IO13, IO14, IO18, IO21, IO26, IO37-IO42.

The display pins deliberately reuse V3's numbers so firmware's existing V3
block needs no display changes.

## Firmware impact — out of scope here, do not implement

This spec covers the board only. The firmware follow-up is a separate plan:

- `RefRtc::begin()` short-circuits to `INTERNAL` on any S3 build
  (`RefRtc.cpp:57-61`). That must become an I2C probe, with `INTERNAL` as the
  fallback when nothing answers.
- `RefRtc` needs an `RV3028` kind: address 0x52, BCD time at registers
  0x00-0x06, status/control at 0x0E-0x10.
- `RefClock.cpp:196` assumes "an S3 here means V3" for the drift budget. That
  must key off the detected chip, not the SoC.
- `board.h` needs a revision block for this board.
- The battery divider's 1M source impedance (D7) means the ADC must discard
  its first reading after the mux settles. `BATT_DIVIDER` stays `2.0f`; only
  the sampling changes.
- The `ext1` wake mask must gain `RTC_INT` alongside the four buttons, and the
  wake handler must clear the RTC alarm flag over I2C before sleeping again —
  the interrupt is level-triggered and stays asserted until cleared, so a
  missed clear means the watch wakes in a loop until the battery is flat.

## Risks

- **Nothing here can be verified without fabricating a board.** ERC, DRC and
  netlist checks prove the design is self-consistent; they prove nothing about
  whether it works. No task may claim otherwise.
- **The RV-3028-C7 footprint is not in KiCad's standard library.** It has to be
  sourced from Micro Crystal or drawn from the datasheet and checked against a
  1:1 print before fab.
- **The MINI-1 antenna keepout** must overhang the board edge with no copper,
  no plane and no traces beneath it, on all four layers.
- **KiCad 5 to modern conversion** is one-way. The V2 files are imported into a
  new project; the upstream repo is never modified.

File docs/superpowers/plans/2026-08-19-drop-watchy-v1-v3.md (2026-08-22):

# Drop Watchy V1.0, V1.5 and V3 Implementation Plan

> **For agentic workers:** REQUIRED SUB-SKILL: Use superpowers:subagent-driven-development (recommended) or superpowers:executing-plans to implement this plan task-by-task. Steps use checkbox (`- [ ]`) syntax for tracking.

**Goal:** Cut the supported boards from five to two — Watchy V2.0 (`watchy_v2`) and this repo's own ESP32-C6 board (`watchy_c6`) — removing V1.0, V1.5 and V3 from the build, the pin map, the RTC layer and the docs.

**Architecture:** Mostly deletion. `board.h` goes from four pin maps to two, `RefRtc::Kind` from four values to two (`NONE`, `PCF8563`), and `RefClock` loses its `esp_chip_info` probe. The one non-deletion is that three `ARDUINO_ESP32S3_DEV` conditionals scattered through the firmware have to be resolved by hand rather than deleted: two of them guard blocks the C6 needs, and one of those — `RefPanel::begin()`'s explicit `SPI.begin()` — is a live C6 defect the removal exposes. A `#error` guard replaces all three retired flags so a stale `-D`, or simply picking an S3 board, fails loudly instead of silently building a pin map for other hardware.

**Tech Stack:** C++17, Arduino/ESP32 core, PlatformIO (`espressif32` for `watchy_v2`, pinned pioarduino fork for `watchy_c6`), GxEPD2. Host tests are plain `g++` binaries driven by `tests/run.sh`.

**Spec:** [`docs/superpowers/specs/2026-08-19-drop-watchy-v1-v3.md`](../specs/2026-08-19-drop-watchy-v1-v3.md)

## Global Constraints

- **Supported boards after this work:** Watchy V2.0 (`watchy_v2`, the default env, ESP32, PCF8563 @ 0x51) and this repo's C6 board (`watchy_c6`, ESP32-C6-MINI-1). Nothing else.
- **Every task ends with both envs building:** `pio run -e watchy_v2 -e watchy_c6`. The first `watchy_c6` build pulls the pioarduino platform and takes several minutes; later ones are quick.
- **Every task ends with the host suite passing:** `./tests/run.sh`.
- **Guard message, verbatim, in `board.h`:** `Watchy V1.0, V1.5 and V3 are no longer supported; build watchy_v2 or watchy_c6`
- **V2.0 pin numbers are facts, not choices,** and do not change in this work: `PIN_BTN_UP 35`, `PIN_BATT_ADC 34`, `PIN_BTN_MENU 26`, `PIN_BTN_BACK 25`, `PIN_BTN_DOWN 4`, `PIN_I2C_SDA 21`, `PIN_I2C_SCL 22`, `PIN_SPI_SCK 18`, `PIN_SPI_MOSI 23`, `PIN_DISPLAY_CS 5`, `PIN_DISPLAY_RST 9`, `PIN_DISPLAY_DC 10`, `PIN_DISPLAY_BUSY 19`, `PIN_VIB_MOTOR 13`, `BTN_PRESSED_LEVEL HIGH`.
- **C6 pin numbers likewise,** and they come from `board-files/elec/src/watchy.ato`: `PIN_I2C_SDA 7`, `PIN_I2C_SCL 6`, `PIN_SPI_SCK 15`, `PIN_SPI_MISO 23`, `PIN_SPI_MOSI 14`, `PIN_SPI_SS 8`, `PIN_BTN_MENU 0`, `PIN_BTN_BACK 1`, `PIN_BTN_UP 2`, `PIN_BTN_DOWN 3`, `PIN_DISPLAY_CS 8`, `PIN_DISPLAY_DC 18`, `PIN_DISPLAY_RST 19`, `PIN_DISPLAY_BUSY 20`, `PIN_VIB_MOTOR 21`, `PIN_BATT_ADC 5`, `BTN_PRESSED_LEVEL LOW`. **Do not edit the C6 block** except to add `BOARD_NAME` in Task 4.
- **The RV-3028-C7 driver is out of scope.** The C6 board's RTC has never been supported and still will not be after this work. Do not add it; do not "fix" `RefRtc` to probe 0x52. It has its own spec coming.
- **The working tree has large unrelated in-progress changes** under `board-files/`, plus modifications to `README.md` and `RefCounter/`. Do **not** run `git add -A` or `git commit -a`. Every commit step below lists exact paths; use those, and check `git status --short` afterwards to confirm `board-files/` is still dirty and unstaged.
- **Comment style:** this codebase explains *why*, in full sentences, in the file the reader will be in. Match it. Never leave a bare `// removed V3` marker.

---

## File Structure

**Modified:**

| File | Responsibility after this work |
| --- | --- |
| `platformio.ini` | Two envs: `watchy_v2` (default) and `watchy_c6` |
| `RefCounter/board.h` | Two pin maps (C6, V2.0), the `#error` guard for retired flags, and `BOARD_NAME` |
| `RefCounter/RefRtc.h` | `Kind` = `{NONE, PCF8563}` |
| `RefCounter/RefRtc.cpp` | PCF8563 probe/read/write only |
| `RefCounter/RefPanel.cpp` | `SPI.begin()` under the C6 flag — the fix |
| `RefCounter/RefCounter.ino` | Deep-sleep GPIO prep under the C6 flag |
| `RefCounter/RefClock.h` / `.cpp` | No `boardRevision()`, no `esp_chip_info` |
| `RefCounter/RefMenu.cpp` | About screen prints `BOARD_NAME`; no DS3231 or internal-clock labels |
| `RefCounter/settings.h` | Drift comment for the two surviving boards |
| `README.md` | Two supported boards throughout |
| `tests/run.sh` | Runs both board tests, plus a negative-compile check per retired flag |

**Created:**

| File | Responsibility |
| --- | --- |
| `tests/stub/Arduino.h` | Minimal host stub so `board.h` and `RefRtc.h` compile off-target |
| `tests/board_test.cpp` | Asserts the V2.0 pin map, its `BOARD_NAME`, and the surviving `RefRtc::Kind` values |
| `tests/board_c6_test.cpp` | Asserts the C6 pin map and its `BOARD_NAME` — `board.h` notes that nothing asserts this half; this is that assertion |

---

## Task 1: Retire the V1.0 and V1.5 build envs and pin map

Removes the two v1 envs and the per-revision `#if` in `board.h`, and makes the retired v1 flags a build error. Ships the host-side scaffolding the later tasks assert against.

**Files:**
- Modify: `platformio.ini`
- Modify: `RefCounter/board.h` (the revision-selection comment block and the trailing ESP32 branch)
- Create: `tests/stub/Arduino.h`
- Create: `tests/board_test.cpp`
- Modify: `tests/run.sh`

**Interfaces:**
- Consumes: nothing from earlier tasks.
- Produces: `board.h` exports the same macro names it does today. No macro is renamed or removed in this task; only the V1.0/V1.5 *values* disappear.
- Produces: `tests/stub/Arduino.h` defines `LOW` (0x0) and `HIGH` (0x1) and includes `<cstdint>`. Tasks 2 and 4 use it via `RefRtc.h` and `board.h`.
- Produces: `tests/run.sh` gains a `board_test` entry with an empty source list, and a `board_guard` block after the main loop that later tasks extend.

- [ ] **Step 1: Create the host stub for `Arduino.h`**

`board.h` includes `<Arduino.h>` and takes exactly two things from it: the `LOW` and `HIGH` pin levels used by `BTN_PRESSED_LEVEL`. Its other core references (`ESP_EXT1_WAKEUP_ANY_HIGH`, `GPIO_INTR_HIGH_LEVEL`) sit inside `#define` bodies that nothing on the host expands.

Create `tests/stub/Arduino.h`:

```c
#pragma once

// Host stub for the ESP32 core's Arduino.h.
//
// board.h is the only header the host tests pull in that needs it, and all it
// takes from Arduino.h are the two pin levels. board.h's other core
// references -- the ext1 wake mode and the light sleep level -- sit inside
// #define bodies that nothing on the host expands, so they are not needed
// here. Keep this file that small: it is a stub, not a second core.

#include <cstdint>

#define LOW  0x0
#define HIGH 0x1
```

- [ ] **Step 2: Write the V2.0 pin-map test**

This one passes before the change as well as after — the V2.0 numbers are what a flagless build already selects. It is here so that collapsing the `#if` in Step 6 is provably a no-op for V2.0, and so a later edit that moves a pin fails a test instead of a watch.

Create `tests/board_test.cpp`:

```cpp
// The pin map is a fact about the hardware, not a preference, so it gets a
// test that fails loudly if a define moves. These are the V2.0 numbers; the
// C6 board's are in board_c6_test.cpp.
//
// V1.0, V1.5 and V3 are no longer supported and board.h #errors on their
// flags. That half is checked by tests/run.sh, because a compile that has to
// fail cannot live in a file that has to compile.

#define ARDUINO_WATCHY_V20 // as platformio.ini's watchy_v2 env does

#include <stdio.h>

#include "board.h"

static_assert(PIN_BTN_MENU == 26, "V2.0 menu button is GPIO 26");
static_assert(PIN_BTN_BACK == 25, "V2.0 back button is GPIO 25");
static_assert(PIN_BTN_DOWN == 4, "V2.0 down button is GPIO 4");
static_assert(PIN_BTN_UP == 35, "V2.0 up button is GPIO 35, not V1's 32");
static_assert(PIN_BATT_ADC == 34, "V2.0 battery tap is GPIO 34, not V1.0's 33 "
                                  "or V1.5's 35");
static_assert(PIN_I2C_SDA == 21 && PIN_I2C_SCL == 22, "V2.0 I2C pins");
static_assert(PIN_SPI_SCK == 18 && PIN_SPI_MOSI == 23, "V2.0 SPI pins");
static_assert(PIN_DISPLAY_CS == 5 && PIN_DISPLAY_RST == 9 &&
                  PIN_DISPLAY_DC == 10 && PIN_DISPLAY_BUSY == 19,
              "V2.0 panel control pins");
static_assert(PIN_VIB_MOTOR == 13, "V2.0 vibration motor is GPIO 13");
static_assert(BTN_PRESSED_LEVEL == HIGH,
              "the ESP32 board reads high when a button is pressed");

int main() {
  printf("board: V2.0 pin map ok\n");
  return 0;
}
```

- [ ] **Step 3: Wire the test and the guard check into the runner**

Three edits to `tests/run.sh`.

First, add `board_test` to the table and the loop — it needs no source files of its own, so its entry is an empty string:

```bash
declare -A SOURCES=(
  [tz_test]="RefCounter/RefZone.cpp"
  [tz_edges]="RefCounter/RefZone.cpp"
  [segments_test]="RefCounter/RefSegments.cpp"
  [sport_test]="RefCounter/RefSport.cpp"
  [sync_schedule]="RefCounter/RefSyncSchedule.cpp"
  [wifi_test]="RefCounter/RefWifi.cpp"
  [menu_items_test]="RefCounter/RefMenuItems.cpp RefCounter/RefSport.cpp RefCounter/RefZone.cpp"
  [board_test]=""
)

for t in tz_test tz_edges segments_test sport_test sync_schedule wifi_test menu_items_test board_test; do
```

Second, append this block at the end of the file, after the loop:

```bash
# board.h has to refuse the retired revision flags outright. A leftover -D, or
# an Arduino IDE user's stale #define, must stop the build rather than quietly
# selecting the V2.0 map -- on V1 hardware the battery tap and the up button
# are on other pins entirely. This is a compile that has to fail, which is why
# it lives here rather than in a .cpp.
echo "=== board_guard"
for flag in ARDUINO_WATCHY_V10 ARDUINO_WATCHY_V15; do
  if err=$($CXX -std=c++17 -Itests/stub -IRefCounter -fsyntax-only \
                -D "$flag" -xc++ - <<<'#include "board.h"' 2>&1); then
    echo "FAIL: board.h accepted -D $flag" >&2
    exit 1
  fi
  case "$err" in
    *"no longer supported"*) echo "  -D $flag rejected" ;;
    *) echo "FAIL: -D $flag failed, but not on the guard:" >&2
       echo "$err" >&2
       exit 1 ;;
  esac
done
echo
```

Third, update the comment block at the top of the file so its file list is not stale. Replace:

```bash
# RefZone.cpp, RefSegments.cpp, RefSport.cpp, RefSyncSchedule.cpp, RefWifi.cpp
# and RefMenuItems.cpp are the files with logic worth testing off the watch: no
```

with:

```bash
# RefZone.cpp, RefSegments.cpp, RefSport.cpp, RefSyncSchedule.cpp, RefWifi.cpp
# and RefMenuItems.cpp are the files with logic worth testing off the watch,
# and board.h's pin maps are checked here too. Between them: no
```

- [ ] **Step 4: Run the tests and watch the guard check fail**

Run: `./tests/run.sh`

Expected: `board_test` prints `board: V2.0 pin map ok` and passes. Then `board_guard` fails with `FAIL: board.h accepted -D ARDUINO_WATCHY_V10` and the script exits non-zero. That is the red test — `board.h` has no guard yet.

- [ ] **Step 5: Add the guard and drop the v1 flags from `board.h`**

In `RefCounter/board.h`, replace the revision-selection prose — from `// The revision is selected by the build:` down to the `#endif` that closes the `#warning` block — with this, keeping the existing `// ----` rule and `#include <Arduino.h>` line where they already sit:

```c
// The revision is selected by the build: ARDUINO_WATCHY_V20 for the Watchy
// V2.0 (ESP32), ARDUINO_ESP32C6_DEV for this repo's own ESP32-C6-MINI-1
// board. See platformio.ini.
// ---------------------------------------------------------------------------

#include <Arduino.h>

// PlatformIO sets the revision from platformio.ini. The Arduino IDE has no
// build-flag field, so IDE users on a V2.0 uncomment the line below -- it has
// to live in this header, which every source file includes, rather than in
// the .ino, which only sets it for itself.
//
// #define ARDUINO_WATCHY_V20
//
// The C6 board needs nothing: selecting an ESP32-C6 board defines
// ARDUINO_ESP32C6_DEV.

// V1.0 and V1.5 are no longer supported. Their up button and battery tap sat
// on other pins than V2.0's -- 32/33 on V1.0 and 32/35 on V1.5, against
// 35/34 here -- so quietly building the V2.0 map for one of them would read
// the battery off the wrong pin and never see the up button at all. A stale
// build flag or an old #define left in this file therefore stops the build.
#if defined(ARDUINO_WATCHY_V10) || defined(ARDUINO_WATCHY_V15)
#error "Watchy V1.0, V1.5 and V3 are no longer supported; build watchy_v2 or watchy_c6"
#endif

#if !defined(ARDUINO_ESP32S3_DEV) && !defined(ARDUINO_ESP32C6_DEV) &&          \
    !defined(ARDUINO_WATCHY_V20)
#warning "No Watchy revision defined; assuming V2.0"
#define ARDUINO_WATCHY_V20
#endif
```

The message names V3 already even though the S3 flag is not caught until Task 3; that keeps one message string in the file rather than two, and Task 3 only widens the `#if`.

- [ ] **Step 6: Collapse the ESP32 pin map to V2.0**

In the same file, replace the final `#else` branch — the one headed `// --- V1.0 / V1.5 / V2.0 (ESP32) ---` — down to just before `// Buttons pull their pin high when pressed.`, with:

```c
#else
// --- Watchy V2.0 (ESP32) ---------------------------------------------------
#define PIN_I2C_SDA 21
#define PIN_I2C_SCL 22

#define PIN_SPI_SCK  18
#define PIN_SPI_MOSI 23

#define PIN_BTN_MENU 26
#define PIN_BTN_BACK 25
#define PIN_BTN_DOWN 4
#define PIN_BTN_UP   35

#define PIN_DISPLAY_CS   5
#define PIN_DISPLAY_RST  9
#define PIN_DISPLAY_DC   10
#define PIN_DISPLAY_BUSY 19

#define PIN_VIB_MOTOR 13
#define PIN_BATT_ADC  34

```

Everything after that — the button-polarity comment and its three defines, the divider comment, `#define BATT_DIVIDER 2.0f`, and the closing `#endif` — stays exactly as it is. The `ARDUINO_ESP32C6_DEV` and `ARDUINO_ESP32S3_DEV` branches above are untouched in this task.

- [ ] **Step 7: Run the tests and watch them pass**

Run: `./tests/run.sh`

Expected: everything passes, ending with

```
=== board_guard
  -D ARDUINO_WATCHY_V10 rejected
  -D ARDUINO_WATCHY_V15 rejected
```

and exit status 0.

- [ ] **Step 8: Remove the v1 envs from `platformio.ini`**

Delete these two blocks entirely:

```ini
[env:watchy_v15]
board = esp32dev
build_flags = -D ARDUINO_WATCHY_V15

[env:watchy_v10]
board = esp32dev
build_flags = -D ARDUINO_WATCHY_V10
```

Then fix the ESP32 section header just above them, which now describes one env rather than three. Replace:

```ini
; --- ESP32 revisions -------------------------------------------------------
; Generic ESP32 boards; the pin map is this project's own, in board.h. The
; revision define is what selects between them.
```

with:

```ini
; --- Watchy V2.0 (ESP32) ---------------------------------------------------
; A generic ESP32 board; the pin map is this project's own, in board.h. The
; revision define is what selects it over the C6 map.
```

Leave the file's opening comment block and the `watchy_v3` env alone — Task 3 rewrites both.

- [ ] **Step 9: Verify the builds**

Run: `pio run -e watchy_v2 -e watchy_c6`
Expected: two `SUCCESS` lines.

Run: `pio run -e watchy_v10`
Expected: failure — `Unknown environment names 'watchy_v10'`.

Clear the stale build directories:

```bash
rm -rf .pio/build/watchy_v10 .pio/build/watchy_v15
```

- [ ] **Step 10: Commit**

```bash
git add platformio.ini RefCounter/board.h tests/stub/Arduino.h tests/board_test.cpp tests/run.sh
git commit -m "board: drop the V1.0 and V1.5 revisions

Their up button and battery tap sat on different pins from V2.0's, which
is the only reason board.h's ESP32 branch had a three-way #if. Neither
revision has ever been run against this firmware. The retired flags now
stop the build rather than silently selecting the V2.0 map, and the
surviving pin map is pinned by a host test."
```

---

## Task 2: Remove the DS3231 driver

The DS3231 was fitted only to V1.0. With that revision gone, the chip has no board to sit on.

**Files:**
- Modify: `RefCounter/RefRtc.h`
- Modify: `RefCounter/RefRtc.cpp`
- Modify: `RefCounter/RefClock.cpp` (`boardRevision()`)
- Modify: `RefCounter/RefMenu.cpp` (`showAbout`)
- Modify: `tests/board_test.cpp`

**Interfaces:**
- Consumes: `tests/stub/Arduino.h` and `tests/board_test.cpp` from Task 1; the runner entry for `board_test` already exists.
- Produces: `RefRtc::Kind` is `enum Kind : uint8_t { NONE, PCF8563, INTERNAL }` — values 0, 1, 2. Task 3 removes `INTERNAL` and leaves `{NONE, PCF8563}`.
- Produces: `RefRtc`'s public surface is otherwise unchanged: `void begin()`, `Kind kind() const`, `bool read(struct tm &out)`, `bool set(const struct tm &t)`, `time_t epoch()`.
- Produces: `uint8_t RefClock::boardRevision()` still exists and still returns 30 for a non-ESP32 SoC; Task 4 deletes it.

- [ ] **Step 1: Write the failing test**

Append to `tests/board_test.cpp`, after the existing `static_assert`s and before `main()`:

```cpp
// The RTC kinds this firmware still knows about. DS3231 sat between NONE and
// PCF8563 and was fitted only to V1.0, so these values are what its removal
// leaves behind -- and asserting on them is the cheapest way to notice if it
// ever creeps back.
#include "RefRtc.h"

static_assert(RefRtc::NONE == 0, "no clock found");
static_assert(RefRtc::PCF8563 == 1, "V2.0's chip; the DS3231 slot is gone");
```

and update `main()`:

```cpp
int main() {
  printf("board: V2.0 pin map and RTC kinds ok\n");
  return 0;
}
```

- [ ] **Step 2: Run the test to verify it fails**

Run: `./tests/run.sh`

Expected: the `board_test` compile fails with

```
static assertion failed: V2.0's chip; the DS3231 slot is gone
note: the comparison reduces to '(2 == 1)'
```

because `DS3231` still occupies value 1.

- [ ] **Step 3: Drop DS3231 from `RefRtc.h`**

Replace the class comment and enum — from `// The watch's real time clock.` through the `Kind` line — with:

```c
// The watch's real time clock.
//
// Which one that is depends on the board, so this probes for what is actually
// on the bus:
//   V2.0  PCF8563  at 0x51
//   C6    nothing this firmware can read yet; the board's RV-3028-C7 has no
//         driver here, so it reports NONE
//
// The chip is talked to directly over Wire in binary coded decimal. That is a
// handful of register reads, and doing it here keeps the project free of the
// RTC libraries the reference firmware pulls in -- one of which no longer
// compiles against a current ESP32 core.
//
// Credit for the chip choice and the address: sqfmi/Watchy.
class RefRtc {
public:
  enum Kind : uint8_t { NONE, PCF8563, INTERNAL };
```

Then delete this line from the private section:

```c
  bool readDS3231(struct tm &out);
```

- [ ] **Step 4: Drop DS3231 from `RefRtc.cpp`**

Delete the `ADDR_DS3231` constant, leaving `const uint8_t ADDR_PCF8563 = 0x51;`.

Replace the non-S3 half of `begin()` — the `if (present(ADDR_DS3231)) { ... } else if (present(ADDR_PCF8563)) { ... } else { ... }` chain — with:

```c
  if (present(ADDR_PCF8563)) {
    _kind = PCF8563;
    // Control 1 and 2 cleared: run normally, no alarm or timer interrupts.
    const uint8_t control[2] = {0x00, 0x00};
    writeRegisters(ADDR_PCF8563, 0x00, control, 2);
  } else {
    _kind = NONE;
  }
```

Leave the `#ifdef ARDUINO_ESP32S3_DEV` / `#else` structure around it alone — Task 3 removes it.

Delete the whole `readDS3231` function together with the two-line `// DS3231 registers 0x00..0x06: ...` comment above it, the `case DS3231:` from `read()`, and the `case DS3231: { ... }` block from `set()`.

- [ ] **Step 5: Drop the DS3231 arms from `boardRevision()` and the About screen**

In `RefCounter/RefClock.cpp`, replace the `switch` inside `boardRevision()` and the comment above it with:

```c
  // V2.0 ships a PCF8563. Finding nothing means the chip did not answer,
  // which is worth reporting as unknown rather than guessing a revision.
  return _rtc.kind() == RefRtc::PCF8563 ? 20 : 0;
```

so the function reads:

```c
uint8_t RefClock::boardRevision() {
  esp_chip_info_t info;
  esp_chip_info(&info);
  if (info.model != CHIP_ESP32) {
    return 30; // an S3 here means V3
  }
  // V2.0 ships a PCF8563. Finding nothing means the chip did not answer,
  // which is worth reporting as unknown rather than guessing a revision.
  return _rtc.kind() == RefRtc::PCF8563 ? 20 : 0;
}
```

(Task 4 deletes this function outright; it just has to compile and stay honest in between.)

In `RefCounter/RefMenu.cpp`, delete this line from the `switch` in `showAbout`:

```c
  case RefRtc::DS3231:   rtcName = "DS3231"; break;
```

- [ ] **Step 6: Run the tests to verify they pass**

Run: `./tests/run.sh`
Expected: all pass; `board_test` prints `board: V2.0 pin map and RTC kinds ok`.

Run: `pio run -e watchy_v2 -e watchy_c6`
Expected: two `SUCCESS` lines, with no unhandled-enumeration warnings — the `read()` and `set()` switches keep their `default` labels.

- [ ] **Step 7: Confirm nothing still references the chip**

Run: `grep -rn "DS3231" RefCounter tests platformio.ini`
Expected: no output. (`README.md` still mentions it; Task 5 handles the docs.)

- [ ] **Step 8: Commit**

```bash
git add RefCounter/RefRtc.h RefCounter/RefRtc.cpp RefCounter/RefClock.cpp RefCounter/RefMenu.cpp tests/board_test.cpp
git commit -m "rtc: remove the DS3231 driver with V1.0

It was fitted only to V1.0. V1.5 and V2.0 both ship the PCF8563, which
is why boardRevision() needed a build-time #if to tell those two apart;
with V1.5 gone the probe answers on its own."
```

---
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

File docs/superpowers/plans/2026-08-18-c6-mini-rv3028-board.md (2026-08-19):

# C6-MINI-1 + RV-3028-C7 Board Implementation Plan

**Status:** the electrical design is done and green, and the netlist is
applied to the PCB. Routing is not done and cannot be done here. See "Where
this stands" below.

**Goal:** A Watchy-compatible board in `board-files/` that replaces V2's
ESP32-PICO-D4 with an ESP32-C6-MINI-1 module and its PCF8563 with an
RV-3028-C7, drops the CP2102 and BMA423, and lands on USB-C — keeping V2's
mechanical envelope and its entire e-paper, charging and motor circuitry.

**Spec:** [`docs/superpowers/specs/2026-08-18-c6-mini-rv3028-board.md`](../specs/2026-08-18-c6-mini-rv3028-board.md)

---

## The approach changed: the board is defined in code

The original version of this plan assumed KiCad's GUI — import V2's schematic,
edit it block by block, run ERC and DRC. That is not executable in this
environment, and the reasons are worth recording because they constrain
anything done here later:

- **There is no GUI.** This runs in a headless container.
- **KiCad 8+ cannot be installed.** The agent proxy denies
  `ppa.launchpadcontent.net`, so the newest available version is Ubuntu's
  **KiCad 7.0.11**. `kicad-cli sch erc` and `pcb drc` were added in 8.0, so
  the original plan's entire verification strategy is unavailable.
- **pypi is reachable**, so code-based EDA tooling is.
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

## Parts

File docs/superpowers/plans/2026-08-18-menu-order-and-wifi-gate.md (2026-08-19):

# Settings Menu Order and the WiFi Gate Implementation Plan

> **For agentic workers:** REQUIRED SUB-SKILL: Use superpowers:subagent-driven-development (recommended) or superpowers:executing-plans to implement this plan task-by-task. Steps use checkbox (`- [ ]`) syntax for tracking.

**Goal:** Reorder the settings menu to About, Sync NTP, TZ, DST, Set Time, Setup WiFi, Sport, Edit Custom; hide `Sync NTP` until WiFi credentials have been saved; and delete the `Vibrate Motor` row.

**Architecture:** Two new host-testable translation units carved out of what is otherwise watch-only code. `RefWifi` owns a single "credentials have been saved" flag in NVS, following the `RefZone`/`RefSport` persistence shape exactly. `RefMenuItems` owns the menu's row order, the visibility rule and the row labels, so the ordering can be tested on a host — `RefMenu.cpp` itself pulls in GxEPD2, WiFiManager and GPIO and cannot be compiled off the watch. `RefMenu.cpp` keeps only drawing and button handling, and its highlight index becomes a *slot* into a rebuilt list of visible rows rather than an `Item` id.

**Tech Stack:** C++11 (Arduino ESP32 core), GxEPD2, Adafruit GFX, WiFiManager, ESP32 `Preferences` (NVS). Host tests are plain g++ against `tests/stub/Preferences.h`.

**Spec:** [`docs/superpowers/specs/2026-08-18-menu-order-and-wifi-gate.md`](../specs/2026-08-18-menu-order-and-wifi-gate.md)

## Global Constraints

- **No new libraries.** GxEPD2, Adafruit GFX and WiFiManager stay the only three.
- **Final menu order is fixed:** `About`, `Sync NTP`, `TZ: <name>`, `DST: Auto/Off`, `Set Time`, `Setup WiFi`, `Sport: <name>`, `Edit Custom`. `Sync NTP` is the only conditional row.
- **`MENU_VISIBLE` stays 7.** Eight rows scroll; seven do not.
- **Menu labels are 18 glyphs or fewer.** `FreeMonoBold9pt7b` advances 11 pixels a glyph on a 200 pixel panel, so 18 glyphs is 198 pixels. The label buffer stays 24 bytes.
- **New persistence follows the `RefZone` pattern:** its own NVS namespace, a `Preferences` handle opened and closed per read/write, the value cached in a file-static so reads cost nothing, defaults applied when nothing is stored.
- **`RefWifi.cpp` and `RefMenuItems.cpp` must compile on a host** with no Arduino headers beyond the `Preferences` stub. Neither may include `RefPanel.h`, `board.h`, `WiFi.h`, `WiFiManager.h` or anything from GxEPD2.
- **Nothing in the menu may power up the WiFi radio to decide what to draw.** The gate reads a cached bool, never the ESP32's stored STA config.
- **Every task ends with all four PlatformIO envs building:** `watchy_v2`, `watchy_v15`, `watchy_v10`, `watchy_v3`.
- **Nothing here can be verified on hardware.** The repo has never run on a watch (README *Known limitations*). "Verify" means the host tests pass and all four envs compile; do not claim otherwise in commit messages.

## File Structure

| File | Responsibility |
| --- | --- |
| `RefCounter/RefWifi.h` / `.cpp` | **new.** The "WiFi has been set up" flag: `begin()`, `configured()`, `setConfigured()`. Pure NVS, no radio. |
| `RefCounter/RefMenuItems.h` / `.cpp` | **new.** `enum Item`, `buildVisible()`, `slotOf()`, `itemLabel()`. No drawing, no buttons, no Arduino headers. |
| `RefCounter/RefMenu.cpp` | **modified.** Loses the enum, `itemLabel` and `showBuzz`; gains a visible-row list and slot-based navigation. |
| `RefCounter/RefCounter.ino` | **modified.** One `RefWifi::begin()` call in `setup()`. |
| `tests/wifi_test.cpp` | **new.** The flag's default, its persistence across a simulated reboot, and the storage-unavailable fallback. |
| `tests/menu_items_test.cpp` | **new.** Both row orders, the slot shift when `Sync NTP` appears, the label widths, and that `Vibrate Motor` is gone. |
| `tests/run.sh` | **modified.** Two more suites. |
| `README.md` | **modified.** Menu table, row count, the upgrade note about re-running Setup WiFi, source tree, testing section. |

---

### Task 1: The WiFi-configured flag

A one-value persistence module. It goes first because `RefMenuItems` and `RefMenu` both depend on it, and because it is the only piece with a user-visible upgrade consequence worth pinning down in a test.

**Files:**
- Create: `RefCounter/RefWifi.h`
- Create: `RefCounter/RefWifi.cpp`
- Create: `tests/wifi_test.cpp`
- Modify: `tests/run.sh`

**Interfaces:**
- Consumes: nothing.
- Produces:
  - `void RefWifi::begin()` — load the flag from NVS; nothing stored means false.
  - `bool RefWifi::configured()` — the cached flag.
  - `void RefWifi::setConfigured(bool on)` — set and persist immediately.

- [ ] **Step 1: Write the failing test**

Create `tests/wifi_test.cpp`:

```cpp
// Host test for the "WiFi has been set up" flag in RefWifi.cpp. Compiles the
// real source against a stub Preferences, so what is under test is the shipped
// code. The flag is what decides whether the menu offers "Sync NTP" at all,
// so its default matters as much as its persistence: a watch that has never
// been through the setup screen must read false.
#include "RefWifi.h"

#include <Preferences.h>
#include <cstdio>

static int failures = 0;

static void expectBool(const char *what, bool got, bool want) {
  if (got != want) {
    printf("FAIL %-46s want %s got %s\n", what, want ? "true" : "false",
           got ? "true" : "false");
    failures++;
  } else {
    printf("ok   %-46s %s\n", what, got ? "true" : "false");
  }
}

int main() {
  // Storage unavailable: begin() must still leave a defined value, and it must
  // be false. A watch whose NVS will not open has no credentials either.
  PreferencesStub::enable(false);
  RefWifi::setConfigured(true); // write goes nowhere, but caches true
  RefWifi::begin();
  expectBool("no storage reads as not set up", RefWifi::configured(), false);

  // Storage available but empty: the same, by way of the default rather than
  // by way of a failed open.
  PreferencesStub::enable(true);
  PreferencesStub::clear();
  RefWifi::begin();
  expectBool("nothing stored reads as not set up", RefWifi::configured(), false);

  // Setting it takes effect immediately, without a begin() in between.
  RefWifi::setConfigured(true);
  expectBool("set true is visible at once", RefWifi::configured(), true);

  // ...and survives a reboot, which is the whole point of it being in NVS:
  // "Sync NTP" must still be there the next time the watch comes up.
  RefWifi::begin();
  expectBool("true survives restart", RefWifi::configured(), true);

  // Clearing it persists too. A failed run of Setup WiFi wipes the stored
  // credentials, so the row has to go away again.
  RefWifi::setConfigured(false);
  RefWifi::begin();
  expectBool("false survives restart", RefWifi::configured(), false);

  PreferencesStub::enable(false);
  printf("\n%s (%d failures)\n", failures ? "FAILED" : "PASSED", failures);
  return failures != 0;
}
```

- [ ] **Step 2: Add the suite to the test runner**

In `tests/run.sh`, add the entry to the `SOURCES` map:

```bash
declare -A SOURCES=(
  [tz_test]="RefCounter/RefZone.cpp"
  [tz_edges]="RefCounter/RefZone.cpp"
  [segments_test]="RefCounter/RefSegments.cpp"
  [sport_test]="RefCounter/RefSport.cpp"
  [sync_schedule]="RefCounter/RefSyncSchedule.cpp"
  [wifi_test]="RefCounter/RefWifi.cpp"
)
```

and to the loop:

```bash
for t in tz_test tz_edges segments_test sport_test sync_schedule wifi_test; do
```

- [ ] **Step 3: Run the test to verify it fails**

Run: `./tests/run.sh`
Expected: FAIL — the compile of `wifi_test` errors with `RefWifi.h: No such file or directory`. The five existing suites still pass first.

- [ ] **Step 4: Write the header**

Create `RefCounter/RefWifi.h`:

```cpp
#ifndef REF_WIFI_H
#define REF_WIFI_H

// Whether the menu's "Setup WiFi" screen has ever saved working credentials.
//
// Nothing here touches the radio. The flag is a single bool in NVS, written by
// the setup screen and read by the menu, so deciding whether to offer "Sync
// NTP" costs nothing -- asking the ESP32 for its stored SSID instead would
// mean powering the WiFi driver up every time the menu drew a row.
//
// The flag is cleared as well as set. "Setup WiFi" wipes the saved credentials
// before it raises its access point, so a setup that fails or times out really
// has left the watch with nothing to connect to, and the row it gates has to
// go away with them.
namespace RefWifi {

// Load the saved flag out of NVS. Nothing stored means "never set up", which
// is also what a watch upgraded from a firmware without this flag reads --
// running "Setup WiFi" once more is what brings "Sync NTP" back.
// Call once at startup.
void begin();

bool configured();
void setConfigured(bool on); // persists immediately

} // namespace RefWifi

#endif // REF_WIFI_H
```

- [ ] **Step 5: Write the implementation**

Create `RefCounter/RefWifi.cpp`:

```cpp
#include "RefWifi.h"

#include <Preferences.h>

namespace RefWifi {
namespace {

// NVS. Its own namespace alongside "refzone" and "refsport", so clearing one
// setting never disturbs another.
const char *NVS_NAMESPACE = "refwifi";
const char *NVS_KEY_SETUP = "setup";

// Cached, so the menu can ask on every redraw without reopening NVS.
bool wasSetUp = false;

} // namespace

void begin() {
  wasSetUp = false;
  Preferences prefs;
  if (prefs.begin(NVS_NAMESPACE, true)) { // read only
    wasSetUp = prefs.getBool(NVS_KEY_SETUP, false);
    prefs.end();
  }
}

bool configured() { return wasSetUp; }

void setConfigured(bool on) {
  wasSetUp = on;
  Preferences prefs;
  if (prefs.begin(NVS_NAMESPACE, false)) {
    prefs.putBool(NVS_KEY_SETUP, wasSetUp);
    prefs.end();
  }
}

} // namespace RefWifi
```

- [ ] **Step 6: Run the tests to verify they pass**

Run: `./tests/run.sh`
Expected: `run.sh` exits 0, with a `=== wifi_test` block of five `ok` lines.
`run.sh` runs under `set -e`, so a failing suite aborts it -- the exit status
is the check, not a count of `PASSED` lines (`tz_test` prints `all checks
passed` and `tz_edges` prints a report with no verdict at all).

- [ ] **Step 7: Commit**

```bash
git add RefCounter/RefWifi.h RefCounter/RefWifi.cpp tests/wifi_test.cpp tests/run.sh
git commit -m "feat: remember whether WiFi has ever been set up"
```

---

### Task 2: The menu's row list

Pull the menu's order, its labels and the new visibility rule out of `RefMenu.cpp` into a pure translation unit, in the new order and without the buzz row. `RefMenu.cpp` is not touched yet — this task adds the module and its test, and the next one switches the menu over to it. Splitting there is deliberate: this half is testable on a host and the next half is not, so a reviewer can accept the ordering logic on evidence before reading the display code.

**Files:**
- Create: `RefCounter/RefMenuItems.h`
- Create: `RefCounter/RefMenuItems.cpp`
- Create: `tests/menu_items_test.cpp`
- Modify: `tests/run.sh`

**Interfaces:**
- Consumes: `RefSport::active()`, `RefZone::name()`, `RefZone::index()`, `RefZone::dstAuto()` — all already shipped.
- Produces:
  - `enum RefMenu::Item : uint8_t { ITEM_ABOUT, ITEM_SYNC, ITEM_ZONE, ITEM_DST, ITEM_SET_TIME, ITEM_WIFI, ITEM_SPORT, ITEM_EDIT_CUSTOM, ITEM_COUNT }`
  - `static const size_t RefMenu::ITEM_LABEL_MAX = 24`
  - `uint8_t RefMenu::buildVisible(bool wifiConfigured, uint8_t *out)` — fills `out[0..n)` with item ids in menu order, returns `n`. `out` must hold `ITEM_COUNT` entries.
  - `int8_t RefMenu::slotOf(const uint8_t *visible, uint8_t count, uint8_t item)` — position of `item` in that list, or `-1`.
  - `void RefMenu::itemLabel(uint8_t item, char *buf, size_t n)`

- [ ] **Step 1: Write the failing test**

Create `tests/menu_items_test.cpp`:

```cpp
// Host test for the settings menu's row list in RefMenuItems.cpp. Compiles the
// real source, so the order under test is the shipped order.
//
// RefMenu.cpp itself cannot be built here -- GxEPD2, WiFiManager and GPIO --
// which is exactly why the list lives in its own file: the order, the
// conditional "Sync NTP" row and the slot arithmetic behind them are cheap to
// check here and expensive to check on a watch.
#include "RefMenuItems.h"

#include "RefSport.h"
#include "RefZone.h"

#include <Preferences.h>
#include <cstdio>
#include <cstring>

static int failures = 0;

static void expectEq(const char *what, long got, long want) {
  if (got != want) {
    printf("FAIL %-46s want %ld got %ld\n", what, want, got);
    failures++;
  } else {
    printf("ok   %-46s %ld\n", what, got);
  }
}

static void expectStr(const char *what, const char *got, const char *want) {
  if (strcmp(got, want) != 0) {
    printf("FAIL %-46s want %s got %s\n", what, want, got);
    failures++;
  } else {
    printf("ok   %-46s %s\n", what, got);
  }
}

// The order the list must come back in, with and without the WiFi row.
static const uint8_t WANT_NO_WIFI[] = {
    RefMenu::ITEM_ABOUT, RefMenu::ITEM_ZONE,  RefMenu::ITEM_DST,
    RefMenu::ITEM_SET_TIME, RefMenu::ITEM_WIFI, RefMenu::ITEM_SPORT,
    RefMenu::ITEM_EDIT_CUSTOM};

static const uint8_t WANT_WITH_WIFI[] = {
    RefMenu::ITEM_ABOUT, RefMenu::ITEM_SYNC, RefMenu::ITEM_ZONE,
    RefMenu::ITEM_DST,   RefMenu::ITEM_SET_TIME, RefMenu::ITEM_WIFI,
    RefMenu::ITEM_SPORT, RefMenu::ITEM_EDIT_CUSTOM};

static void expectOrder(const char *what, const uint8_t *got, uint8_t gotCount,
                        const uint8_t *want, uint8_t wantCount) {
  char label[80];
  snprintf(label, sizeof(label), "%s row count", what);
  expectEq(label, gotCount, wantCount);
  const uint8_t n = gotCount < wantCount ? gotCount : wantCount;
  for (uint8_t i = 0; i < n; i++) {
    snprintf(label, sizeof(label), "%s slot %u", what, (unsigned)i);
    expectEq(label, got[i], want[i]);
  }
}

int main() {
  // Nothing stored, so the labels that read a value read the settings.h
  // defaults: Eastern, DST auto, Football.
  PreferencesStub::enable(false);
  RefZone::begin();
  RefSport::begin();

  uint8_t visible[RefMenu::ITEM_COUNT];

  // WiFi never set up: seven rows and no Sync NTP, because with no credentials
  // stored that row could only ever fail.
  uint8_t n = RefMenu::buildVisible(false, visible);
  expectOrder("no wifi", visible, n, WANT_NO_WIFI,
              (uint8_t)(sizeof(WANT_NO_WIFI) / sizeof(WANT_NO_WIFI[0])));
  expectEq("sync absent without wifi",
           RefMenu::slotOf(visible, n, RefMenu::ITEM_SYNC), -1);
  expectEq("setup wifi sits at slot 4",
           RefMenu::slotOf(visible, n, RefMenu::ITEM_WIFI), 4);

  // WiFi set up: eight rows, Sync NTP second.
  n = RefMenu::buildVisible(true, visible);
  expectOrder("with wifi", visible, n, WANT_WITH_WIFI,
              (uint8_t)(sizeof(WANT_WITH_WIFI) / sizeof(WANT_WITH_WIFI[0])));
  expectEq("sync is second with wifi",
           RefMenu::slotOf(visible, n, RefMenu::ITEM_SYNC), 1);
  // The case the menu depends on: running Setup WiFi inserts a row *above* it,
  // so the highlight has to be moved by item, not left on slot 4.
  expectEq("setup wifi shifts down one",
           RefMenu::slotOf(visible, n, RefMenu::ITEM_WIFI), 5);
  expectEq("unknown item has no slot",
           RefMenu::slotOf(visible, n, RefMenu::ITEM_COUNT), -1);

  // Labels. Fixed text where it is fixed, and the three value-carrying rows
  // reading their defaults.
  char label[RefMenu::ITEM_LABEL_MAX];
  RefMenu::itemLabel(RefMenu::ITEM_ABOUT, label, sizeof(label));
  expectStr("about label", label, "About");
  RefMenu::itemLabel(RefMenu::ITEM_SYNC, label, sizeof(label));
  expectStr("sync label", label, "Sync NTP");
  RefMenu::itemLabel(RefMenu::ITEM_SET_TIME, label, sizeof(label));
  expectStr("set time label", label, "Set Time");
  RefMenu::itemLabel(RefMenu::ITEM_WIFI, label, sizeof(label));
  expectStr("setup wifi label", label, "Setup WiFi");
  RefMenu::itemLabel(RefMenu::ITEM_EDIT_CUSTOM, label, sizeof(label));
  expectStr("edit custom label", label, "Edit Custom");
  RefMenu::itemLabel(RefMenu::ITEM_ZONE, label, sizeof(label));
  expectStr("zone label reads the zone", label, "TZ: Eastern");
  RefMenu::itemLabel(RefMenu::ITEM_DST, label, sizeof(label));
  expectStr("dst label reads the switch", label, "DST: Auto");
  RefMenu::itemLabel(RefMenu::ITEM_SPORT, label, sizeof(label));
  expectStr("sport label reads the sport", label, "Sport: Football");

  // Every row has to fit the panel: FreeMonoBold9pt7b advances 11 pixels a
  // glyph and the panel is 200 wide, so 18 glyphs is the ceiling. The buzz
  // test is gone, and must not creep back in.
  for (uint8_t i = 0; i < RefMenu::ITEM_COUNT; i++) {
    RefMenu::itemLabel(i, label, sizeof(label));
    char what[80];
    snprintf(what, sizeof(what), "%s fits 18 glyphs", label);
    expectEq(what, (long)strlen(label) <= 18, 1);
    snprintf(what, sizeof(what), "%s is not the buzz test", label);
    expectEq(what, strcmp(label, "Vibrate Motor") != 0, 1);
  }

  printf("\n%s (%d failures)\n", failures ? "FAILED" : "PASSED", failures);
  return failures != 0;
}
```

- [ ] **Step 2: Add the suite to the test runner**

In `tests/run.sh`, add the entry to the `SOURCES` map — three sources, since the value-carrying labels read the real sport and zone tables:

```bash
  [menu_items_test]="RefCounter/RefMenuItems.cpp RefCounter/RefSport.cpp RefCounter/RefZone.cpp"
```

and to the loop:

```bash
for t in tz_test tz_edges segments_test sport_test sync_schedule wifi_test menu_items_test; do
```

Also update the comment at the top of `tests/run.sh`, which currently names only four testable files:

```bash
# RefZone.cpp, RefSegments.cpp, RefSport.cpp, RefSyncSchedule.cpp, RefWifi.cpp
# and RefMenuItems.cpp are the files with logic worth testing off the watch: no
# panel, no GPIO, and the sort of bugs -- a daylight saving date, a digit
# running off the edge of the screen, a clamp, a due-time boundary, a menu row
# in the wrong place -- that are expensive to find on hardware. They compile
# here against a stub Preferences; everything else is the shipped source.
```

- [ ] **Step 3: Run the test to verify it fails**

Run: `./tests/run.sh`
Expected: FAIL — the compile of `menu_items_test` errors with `RefMenuItems.h: No such file or directory`. The six earlier suites still run clean first.

- [ ] **Step 4: Write the header**

Create `RefCounter/RefMenuItems.h`:

```cpp
#ifndef REF_MENU_ITEMS_H
#define REF_MENU_ITEMS_H

#include <stddef.h>
#include <stdint.h>

// The settings menu's row list: which rows exist, what order they come in, and
// what each one says.
//
// Split out of RefMenu.cpp so it can be compiled and tested on a host --
// RefMenu.cpp pulls in GxEPD2, WiFiManager and the GPIO layer, none of which
// build off the watch. Nothing here draws anything or reads a button.
namespace RefMenu {

// Menu order. About first, because that is the row the menu opens on, then the
// three rows that touch the clock and the two that touch the radio. The sport
// rows are last: they are set once for the season, where everything above them
// is either read or adjusted in the field.
enum Item : uint8_t {
  ITEM_ABOUT,
  ITEM_SYNC,
  ITEM_ZONE,
  ITEM_DST,
  ITEM_SET_TIME,
  ITEM_WIFI,
  ITEM_SPORT,
  ITEM_EDIT_CUSTOM,
  ITEM_COUNT,
};

// The widest label is "Sport: Base NCAA" at 16 glyphs, and the panel fits 18.
// 24 leaves room rather than sizing the buffer to the exact width and hoping
// nothing grows past it.
static const size_t ITEM_LABEL_MAX = 24;

// Fill `out` -- which must hold ITEM_COUNT entries -- with the items to show,
// in menu order, and return how many there are. "Sync NTP" is left out until
// WiFi credentials have been saved: with none stored it could only ever fail.
uint8_t buildVisible(bool wifiConfigured, uint8_t *out);

// Which slot of a list built by buildVisible holds `item`, or -1 when that
// item is not currently shown. This is how the highlight follows a row across
// a rebuild: running "Setup WiFi" can make "Sync NTP" appear *above* it, which
// moves it and every row below it down one.
int8_t slotOf(const uint8_t *visible, uint8_t count, uint8_t item);

// The row's text. Three rows read their current value rather than being fixed
// text, so the menu doubles as the status display for the sport, the zone and
// the DST switch.
void itemLabel(uint8_t item, char *buf, size_t n);

} // namespace RefMenu

#endif // REF_MENU_ITEMS_H
```

- [ ] **Step 5: Write the implementation**

Create `RefCounter/RefMenuItems.cpp`:

```cpp
#include "RefMenuItems.h"

#include <stdio.h>

#include "RefSport.h"
#include "RefZone.h"

namespace RefMenu {

uint8_t buildVisible(bool wifiConfigured, uint8_t *out) {
  uint8_t count = 0;
  for (uint8_t i = 0; i < ITEM_COUNT; i++) {
    if (i == ITEM_SYNC && !wifiConfigured) {
      continue;
    }
    out[count++] = i;
  }
  return count;
}

int8_t slotOf(const uint8_t *visible, uint8_t count, uint8_t item) {
  for (uint8_t s = 0; s < count; s++) {
    if (visible[s] == item) {
      return (int8_t)s;
    }
  }
  return -1;
}

void itemLabel(uint8_t item, char *buf, size_t n) {
  switch (item) {
  case ITEM_ABOUT:    snprintf(buf, n, "About"); break;
  case ITEM_SYNC:     snprintf(buf, n, "Sync NTP"); break;
  case ITEM_ZONE:     snprintf(buf, n, "TZ: %s", RefZone::name(RefZone::index())); break;
  case ITEM_DST:      snprintf(buf, n, "DST: %s", RefZone::dstAuto() ? "Auto" : "Off"); break;
  case ITEM_SET_TIME: snprintf(buf, n, "Set Time"); break;
  case ITEM_WIFI:     snprintf(buf, n, "Setup WiFi"); break;
  case ITEM_SPORT:    snprintf(buf, n, "Sport: %s", RefSport::active().name); break;
  case ITEM_EDIT_CUSTOM: snprintf(buf, n, "Edit Custom"); break;
  default:            snprintf(buf, n, "?"); break;
  }
}

} // namespace RefMenu
```

- [ ] **Step 6: Run the tests to verify they pass**

Run: `./tests/run.sh`
Expected: `run.sh` exits 0. `=== menu_items_test` reports both orders, both `Setup WiFi` slots (4 without the sync row, 5 with it), the eight labels, and 16 width/no-buzz checks.

- [ ] **Step 7: Commit**

```bash
git add RefCounter/RefMenuItems.h RefCounter/RefMenuItems.cpp tests/menu_items_test.cpp tests/run.sh
git commit -m "feat: give the menu's row list its own host-tested module"
```

---
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

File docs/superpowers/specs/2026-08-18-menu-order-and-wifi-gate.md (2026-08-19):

# Settings Menu Order, the WiFi Gate and Dropping the Buzz Test

**Date:** 2026-08-18
**Status:** agreed, ready to implement

## What is being asked for

Three changes to the on-watch settings menu (`RefCounter/RefMenu.cpp`):

1. **Reorder the rows.** The requested order is About, Sync NTP, TZ, DST, Set
   Time, Setup WiFi.
2. **Hide "Sync NTP" until WiFi has been set up.** With no credentials stored
   the row can only ever fail, so it should not be offered.
3. **Remove the "Vibrate Motor" row** and the buzz-test screen behind it.

## Decisions taken

**Where the two sport rows go.** The requested list names six rows; the menu
also carries `Sport: <name>` and `Edit Custom`. Both stay, at the **bottom** of
the list, so the six requested rows appear in exactly the order given, at the
top. Final order:

| Slot | Row | Shown when |
| --- | --- | --- |
| 1 | `About` | always |
| 2 | `Sync NTP` | only once WiFi has been set up |
| 3 | `TZ: <name>` | always |
| 4 | `DST: Auto/Off` | always |
| 5 | `Set Time` | always |
| 6 | `Setup WiFi` | always |
| 7 | `Sport: <name>` | always |
| 8 | `Edit Custom` | always |

Seven rows when WiFi has never been set up, eight once it has. `MENU_VISIBLE`
is 7, so the menu scrolls only in the eight-row case.

**How "WiFi has been setup" is decided.** A persisted flag in NVS, owned by a
new `RefWifi` module, following the shape of `RefZone` and `RefSport`: one
value cached in RAM, loaded once by `begin()`, written through on change.

- `setupWifi()` sets the flag true when `WiFiManager::autoConnect` succeeds and
  false when it fails or times out. Clearing on failure is correct rather than
  merely tidy: that screen calls `resetSettings()` before it raises its access
  point, so a failed setup really has left the watch with no credentials.
- Reading a cached bool costs nothing. The alternative — asking the ESP32 for
  its stored STA SSID — requires powering up the WiFi driver, which would run
  every time the menu opened or scrolled. Rejected on power grounds.

**Consequence, accepted:** a watch that already has credentials saved from
before this change has no flag stored, so `Sync NTP` is hidden until **Setup
WiFi** is run once more. This must be called out in the README.

**Removing the buzz test.** `showBuzz()` and the `ITEM_BUZZ` row go entirely.
`Buzzer` itself stays — the confirmation pulse, the warning marks and the
expiry buzz all still use it.

## Design

The menu's row list is pulled out of `RefMenu.cpp` into a new pure
`RefMenuItems` translation unit — the order, the visibility rule and the row
labels. `RefMenu.cpp` cannot be compiled on a host (GxEPD2, WiFiManager, GPIO),
and this logic is exactly the sort that is expensive to check on hardware. The
split follows the precedent set by `RefSegments`, which was carved out of
`RefDisplay.cpp` for the same reason.

```
RefMenuItems.h/.cpp   enum Item, buildVisible(), slotOf(), itemLabel()   host-testable
RefWifi.h/.cpp        begin(), configured(), setConfigured()              host-testable
RefMenu.cpp           drawing and button handling only                    watch only
```

`RefMenu.cpp` keeps an array of visible item ids and a count, and its
highlight index becomes a **slot** index into that array rather than an item
id. Wrapping and scrolling use the visible count.

**The one non-obvious case:** running **Setup WiFi** can make **Sync NTP**
appear above it, which shifts `Setup WiFi` and everything below it down a slot.
So after every action the list is rebuilt and the highlight is moved to
`slotOf(<the item the user just ran>)`, not left on its old slot number.

## Out of scope

- Gating the automatic NTP resync (`RefClock`) on the same flag. It is already
  off by default (`NTP_RESYNC_HOURS = 0`) and the ask is about the menu.
- Any change to what the six retained screens do once opened.
- Hardware verification. This firmware has never run on a watch; see the
  README's *Known limitations*.

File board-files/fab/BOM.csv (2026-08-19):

Quantity | Value | Footprint | Library | Designators
1 | JST 1.25mm battery connector | 1.25T-2PWT (Molex 532610271) | footprints | J3
1 | FPC24 0.5mm ZIF | 24_Pins_0.5mm_Pitch_ZIF_Connector_UP | footprints | J1
2 | 100nF | C_0402_1005Metric | Capacitor_SMD | C15,C16
1 | 4.7uF | C_0402_1005Metric | Capacitor_SMD | C11
2 | 100nF | C_0603_1608Metric | Capacitor_SMD | C1,C14
7 | 1uF/50V | C_0603_1608Metric | Capacitor_SMD | C2,C5,C6,C7,C8,C9,C10
3 | 4.7uF/50V | C_0805_2012Metric | Capacitor_SMD | C3,C4,C12
4 | MBR0530 Schottky | D_SOD-123 | Diode_SMD | D1,D2,D3,D4
1 | 1N4001 | D_SOD-123F | Diode_SMD | D6
1 | ESP32-C6-MINI-1 | ESP32-C6-MINI-1 | footprints | U1
4 | Side tactile switch | K2-1114SA-A4SW-06 | footprints | SW1,SW2,SW3,SW4
1 | LED (charge status) | LED_0603_1608Metric | LED_SMD | D5
1 | 10uH 1A | L_Taiyo-Yuden_NR-40xx | Inductor_SMD | L1
1 | Vibration motor pads | Motor_Header | footprints | M1
1 | RV-3028-C7 RTC | RV-3028-C7 | footprints | U6
1 | 100k | R_0402_1005Metric | Resistor_SMD | R20
6 | 10k | R_0402_1005Metric | Resistor_SMD | R1,R7,R8,R14,R15,R23
2 | 1M | R_0402_1005Metric | Resistor_SMD | R12,R13
2 | 1k | R_0402_1005Metric | Resistor_SMD | R16,R17
1 | 3R | R_0402_1005Metric | Resistor_SMD | R9
2 | 4.7k | R_0402_1005Metric | Resistor_SMD | R2,R3
2 | 5.1k | R_0402_1005Metric | Resistor_SMD | R21,R22
1 | AO3400A N-channel MOSFET | SOT-23 | Package_TO_SOT_SMD | Q1
1 | CJ2301 P-channel MOSFET | SOT-23 | Package_TO_SOT_SMD | Q4
1 | S8050 NPN | SOT-23 | Package_TO_SOT_SMD | Q5
1 | ME6211C33M5G-N 3.3V LDO | SOT-23-5 | Package_TO_SOT_SMD | U2
1 | TP4054 Li-ion charger | SOT-23-5 | Package_TO_SOT_SMD | U5
1 | USBLC6-2P6 USB ESD array | SOT-666 | Package_TO_SOT_SMD | U3
1 | USB-C 2.0 receptacle, 16 pin | USB_C_Receptacle_XKB_U262-16XN-4BVC11 | Connector_USB | J2

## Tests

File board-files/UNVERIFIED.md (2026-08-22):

# What has not been checked

`checks/run.sh` proves the netlist matches the spec. That is the only thing
that has been proved. Everything below is open, and every item is blocking
before this board is sent to a fab house.

- **The RV-3028-C7 driver was written from the Application Manual, not from a part.** `RefCounter/RefRtc.cpp` uses I2C address 0x52, BCD time at registers 0x00-0x06 (seconds, minutes, hours, weekday, date, month, year), status at 0x0E with the power-on reset flag in bit 0, and control 2 at 0x10. Those were taken from published register maps for the part -- a widely used Arduino library's header, corroborated by a second reading of the Application Manual -- rather than from the PDF directly, which would not render in the environment this was written in. No register has been read off a real chip, and nobody has held the datasheet's register table beside the code. `tests/rtc_test.cpp` proves the decoding is self-consistent and that the two chips' register layouts are not confused with each other -- it cannot prove the addresses are right.
- **The RV-3028's 12/24-hour and EEPROM behaviour is assumed, not observed.** `begin()` writes control 2 to zero, which the manual says selects 24-hour mode and disables every interrupt. Control 1, which holds the automatic EEPROM refresh setting, is deliberately left as the part ships. Neither has run.
- **The RV-3028-C7 footprint is provisional.** `elec/footprints/footprints.pretty/RV-3028-C7.kicad_mod` was drawn from the C7 package outline (3.20 x 1.50 x 0.80mm, 8 terminals, 4 per long side) with a reconstructed land pattern: 0.90mm pitch, 0.50 x 0.50mm pads, rows 1.20mm centre to centre. Those numbers were NOT read off the datasheet's recommended-solder-pad drawing -- network egress to microcrystal.com and every datasheet mirror is blocked in the environment this was built in. Get the datasheet, correct the footprint, then print it at 1:1 and lay the real part on it. A footprint wrong by half a pitch is invisible on screen and obvious on paper.
- **The RV-3028-C7 pin numbering is provisional for the same reason.** The pin functions (1 CLKOUT, 2 INT, 3 SCL, 4 SDA, 5 VSS, 6 VBACKUP, 7 VDD, 8 EVI) come from the spec; which physical corner is pin 1, and whether numbering runs counter-clockwise, was assumed when drawing the footprint. Confirm both against the datasheet.
- **No ERC has been run, and none can be.** atopile has no ERC, and `kicad-cli sch erc` reads a `.kicad_sch`, which this project does not have -- the design is atopile source compiled straight to a netlist. Nothing has checked for driven-output conflicts or unconnected pins beyond what the netlist assertions cover. This is a real cost of the "design is code" choice and it is not going away.
- **DRC now runs, and `checks/run.sh` fails on it.** KiCad 9.0.2 is installed and `checks/drc_check.py` holds the board to zero errors and zero unconnected items against a written allowlist. What DRC does *not* tell you is whether the design is right -- only that the copper obeys the rules.
- **Three signal nets are not routed:** `EPD_C24` at `J1.24`, `EPD_CS` at `J1.12` and `USB_DM` at `J2.A7`. Every ground pad is connected as of the current run, but stranded ground pads -- reached by no pour and given no via -- are the failure this layout produces when the right-hand side gets crowded, and earlier runs stranded `U3.2` and `C11.1`, an ESD array's return and a bulk capacitor's ground. They were invisible until the floating pour slivers concealing them were deleted, so treat a run that reports none as a result of that run rather than a property of the design. `scripts/route.py` finishes the power and all but three of the signal nets and leaves the rest; it exits non-zero and `checks/run.sh` fails while they are outstanding. The board is not finished and nothing in this repository should be read as saying it is. The README lists what was tried and what to try next.
- **DRC has no unaccepted errors left, which is not the same as the board being right.** 39 violations remain and every one is on `checks/drc_check.py`'s allowlist with a written reason: `U1`'s 17 pads 0.30mm from the top edge (the module's position is fixed by its antenna having to overhang), 18 courtyard overlaps, and `J2`'s own mounting holes against its own pads. An allowlist is a record of decisions, not a proof that the decisions were good -- read it before trusting it. What DRC still reports as outstanding is connectivity: 4 unconnected items, from the three unrouted nets and one stranded ground pad. Superseded figures, for reference: 128 errors: 63 solder-mask bridges, 21 board-edge-clearance, 21 starved thermals, 18 courtyard overlaps, 4 hole-clearance, 1 clearance. Every mask bridge is now between pads of one fine-pitch footprint (`J1` 22, `J2` 19, `U3` 4) or between two adjacent 0402s, which is ordinary aperture merging and what a fab expects; every edge-clearance hit is a pad rather than a track; and the clearance and hole-clearance errors are internal to `Q4`/`R15` and to `J2`. What is *not* yet done is writing each of those into `checks/drc_check.py`'s allowlist with a reason, so the suite still fails on all 128 rather than on the ones that matter.
- **V2's branding has been taken off the board.** The `watchy` and `SQFMI` mask lettering (19 text objects) and the two sqfmi logo footprints are deleted by `apply_netlist.py` on every run. This is a derivative reference design and should not be fabricated carrying another project's marks; it also removed 119 solder-mask bridges, because mask lettering is drawn as bare-copper apertures and everything passing beneath one bridged to it. The display outline (`REF**`, B.Fab) is kept -- it comes from V2's library and carries the name, but it is a mechanical outline rather than a mark. Attribution to sqfmi stays in the documentation, where it belongs.
- **The routing is machine-generated and has never been reviewed by eye.** `scripts/route.py` is a maze router written for this board. It gets the connectivity right, DRC agrees, and the differential pair and charge-pump loop are routed first and never ripped up -- but "DRC-clean" is a very long way from "well routed". Nobody has looked at the return paths, the loop areas, or what the USB pair actually does between the connector and the module. Do that before ordering.
- **The USB pair is not impedance-controlled.** `USB_DP` and `USB_DM` are routed first, together, on F.Cu over the In1.Cu ground plane, at the board's default 0.2mm width. Nothing has computed what that geometry gives for a 90-ohm differential pair against the stackup, and the stackup itself is nominal.
- **Three courtyard overlaps remain and are accepted on purpose**, all of them the USB-C receptacle against its neighbours: `J2`/`R16` by 0.49mm, `J2`/`J3` by 0.33mm and `J2`/`Q4` by 0.13mm. There is 9.15mm between the battery connector and the charger, and a USB-C shell is 9.04mm wide with a 10.73mm courtyard, so this does not fit and cannot be made to fit without moving a part the case is cut to. The parts themselves clear each other; it is the courtyards that overlap. Everything else V2 carried has been left as V2 had it.
- **Three parts moved to get copper off the USB-C shield tabs, and one of them faces the case.** The tabs are through-hole and stick out past the housing; `J3`'s mounting pad and `U5.3` were sitting *on* one, overlapping by 0.067mm and 0.120mm, which is a short and not a clearance. `U5` moved down 0.45mm, `J3` up 0.28mm, and `SW2` -- the BACK button -- up 0.20mm, because `J3` is pinched between the tab and the button and the corridor was 0.05mm too narrow to fit it otherwise. The button move is inside any plausible case tolerance but it is a real change to a case-facing part; the case spec records it. Two V2-inherited pad pairs are still under the 0.2mm rule (`Q4.3`/`R15.1` at 0.165mm, `R14.2`/`Q4.1` at 0.175mm) and have been left as V2 had them.
- **`VBUS` is a pour, and the split under it has not been thought about hard.** It sits on In2.Cu at higher priority than `+3V3`, over the nine pads of the charge-current block; `D4` and `D5` are still routed. That puts a hole in the `+3V3` plane, and anything routed on B.Cu across that hole has no continuous reference underneath it. At SPI rates and 12Mbps USB this should not matter, and the pair itself is on F.Cu over solid In1.Cu ground -- but nobody has looked at which B.Cu tracks actually cross the split.
- **The `VBACKUP` decision is reasoned, not measured.** Tying `VBACKUP` to `GND` rather than to a rail is argued from the direct-switchover behaviour described in the RV-3028-C7 application manual. Read that section before committing to it.
- **The USB-C receptacle is a footprint choice, not a sourcing decision.** `Connector_USB:USB_C_Receptacle_XKB_U262-16XN-4BVC11` is a common 16-pin part. Its *pose* has now been checked -- it is rotated 90 degrees, and its housing front face is flush with the board edge at x=102.5, which puts all sixteen pads and both shield tabs on the board. It was previously at 0 degrees, facing down the board, with six pads hanging over the right-hand edge in mid-air. The case cutout has still not been checked against it.
- **The board has no strap slots any more.** V2 cut two 2 x 28mm slots through the PCB for the band to pin through. They ran directly under the module and its decoupling and have been removed. Nothing on the PCB now takes the strap load -- the case has to, in full. See `docs/superpowers/specs/2026-08-18-waterproof-case-design.md`.
- **The module's thermal pads are tied to the ground plane with vias in the pads.** They have to be: the array is 1.2mm pads on a 1.65mm pitch, which leaves 0.45mm gaps that a pour cannot enter and a via cannot sit beside. Espressif's reference layout does the same. Tell the fab, and expect to plug or tent them -- an open via in an SMD pad wicks solder off it.
- **The firmware's pin map for this board was wrong in three places, and is now right by inspection only.** `RefCounter/board.h`'s ESP32-S3 block had the four button pins as 7/6/0/8 where that board wired them to IO4/5/6/7 -- every line wrong, and `PIN_BTN_UP 0` is the boot strapping pin, which this design uses as `TP_BOOT`. It also carried `BATT_DIVIDER` as `(360+100)/360` = 1.28 where this board's 1M/1M divider needs 2.0, so the battery would have read about 36% low. Both are corrected against `elec/src/watchy.ato` and the spec's pin map, and all five PlatformIO environments build -- but nothing has run on hardware, and a pin map that agrees with itself is not the same as one that agrees with a board. `RTC_INT` (IO4 on the C6) still has no firmware constant, and that is now a deliberate choice rather than an open question: the firmware never programs an RTC alarm -- it wakes on the four buttons and on its own deep-sleep timer -- so nothing would ever assert INT. `RefRtc::begin()` clears the RV-3028's control 2 to keep every interrupt enable off, precisely so a stray alarm cannot hold that line low against a wake-capable pin. If a future change does use the alarm, the ext1 mask needs `RTC_INT` and the wake handler must clear the alarm flag over I2C before sleeping again.
- **The six display GPIOs are ordered for the layout and do not match Watchy V3.** Stock Watchy firmware will drive the wrong lines on this board -- and since the module is now an ESP32-C6, there are no IO33-IO48 for it to match anyway. This was a deliberate choice and stock-firmware compatibility is explicitly not a goal; `RefCounter/board.h` is the authoritative map. See the spec's pin map section.
- **The GDEY0154D67 pinout is assumed to match the GDEH0154D67 it replaces.** The GDEH is end-of-life. Both are 1.54" 200x200 on an SSD1681 with a 24-pin FPC, GxEPD2 drives both with the same four-pin constructor, and the firmware builds -- but the panel's FPC pinout has not been read off a GDEY datasheet and compared pin by pin against what `J1` is wired to. Do that before powering a panel.
- **Nothing about the ESP32-C6-MINI-1 swap has been checked against hardware.** The pin map is derived from the datasheet's Table 3-1, Table 4-3 and Table 4-7 and from ESP-IDF's C6 GPIO and sleep-mode documentation: 22 GPIO brought out, IO0-IO7 the only deep-sleep wake pins, IO0-IO6 the only ADC1 channels, IO9 the only pin that decides boot mode, IO15 ignored unless an eFuse is burnt. `checks/netlist_check.py` asserts the design agrees with all of that, and mutation testing confirms the assertions bite -- but every one of those facts is a reading of a PDF, and the board has never been powered. The `watchy_c6` firmware env also builds on a *different* PlatformIO platform from the other four (the pioarduino fork, for Arduino-ESP32 3.x); that toolchain has never produced a binary that ran on anything.

- **The ESP32-C6-MINI-1 land pattern is Espressif's own** (github.com/espressif/kicad-libraries, CC-BY-SA 4.0), which is about as good as a sourced footprint gets, but it has still never been through a reflow oven on this board.
- **Nothing here has been fabricated, powered or tested.** No claim in this repository should be read as saying the design works.

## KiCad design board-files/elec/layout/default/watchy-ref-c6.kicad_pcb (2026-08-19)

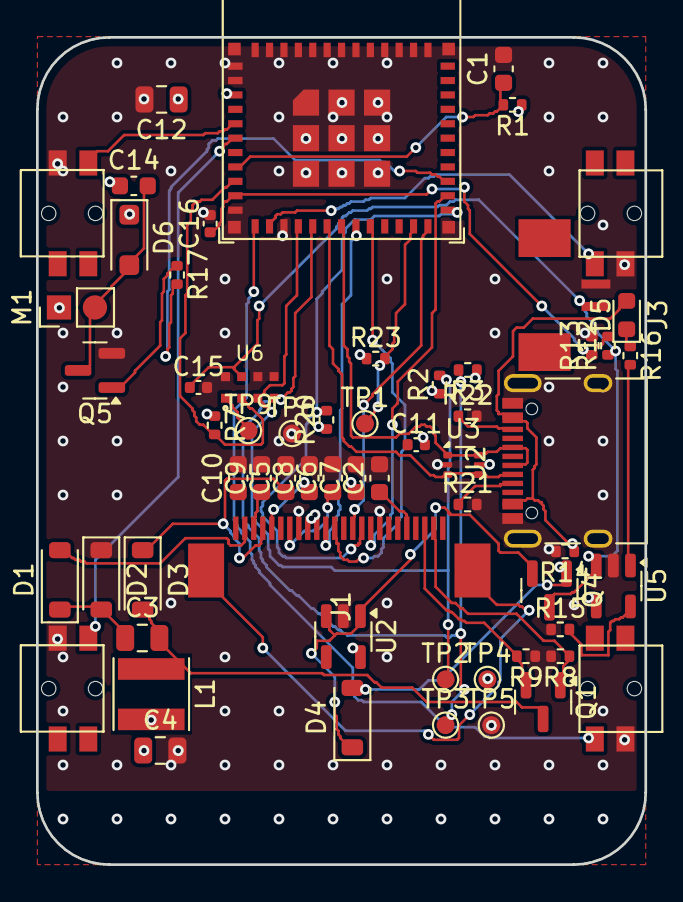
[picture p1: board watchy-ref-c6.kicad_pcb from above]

Board: 4 copper layers, 33.8 x 46.0 mm, 61 parts (0 on the bottom side), 43 nets.

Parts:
C1, C14: 100nF; C_0603_1608Metric
C2, C5, C6, C7, C8, C9, C10: 1uF/50V; C_0603_1608Metric
C3, C4, C12: 4.7uF/50V; C_0805_2012Metric
C11: 4.7uF; C_0402_1005Metric
C15, C16: 100nF; C_0402_1005Metric
D1, D2, D3, D4: MBR0530 Schottky; D_SOD-123
D5: LED (charge status); LED_0603_1608Metric
D6: 1N4001; D_SOD-123F
J1: FPC24 0.5mm ZIF; 24_Pins_0.5mm_Pitch_ZIF_Connector_UP
J2: USB-C 2.0 receptacle, 16 pin; USB_C_Receptacle_XKB_U262-16XN-4BVC11
J3: JST 1.25mm battery connector; 1.25T-2PWT (Molex 532610271)
L1: 10uH 1A; L_Taiyo-Yuden_NR-40xx
M1: Vibration motor pads; Motor_Header
Q1: AO3400A N-channel MOSFET; SOT-23
Q4: CJ2301 P-channel MOSFET; SOT-23
Q5: S8050 NPN; SOT-23
R1, R7, R8, R14, R15, R23: 10k; R_0402_1005Metric
R2, R3: 4.7k; R_0402_1005Metric
R9: 3R; R_0402_1005Metric
R12, R13: 1M; R_0402_1005Metric
R16, R17: 1k; R_0402_1005Metric
R20: 100k; R_0402_1005Metric
R21, R22: 5.1k; R_0402_1005Metric
SW1, SW2, SW3, SW4: Side tactile switch; K2-1114SA-A4SW-06
TP1: GPIO0; TestPoint_Pad_D1.0mm
TP2: SCL; TestPoint_Pad_D1.0mm
TP3: SDA; TestPoint_Pad_D1.0mm
TP4: 3V3; TestPoint_Pad_D1.0mm
TP5, TP6: GND; TestPoint_Pad_D1.0mm
TP9: 1.0mm test pad; TestPoint_Pad_D1.0mm
U1: ESP32-C6-MINI-1
U2: ME6211C33M5G-N 3.3V LDO; SOT-23-5
U3: USBLC6-2P6 USB ESD array; SOT-666
U5: TP4054 Li-ion charger; SOT-23-5
U6: RV-3028-C7 RTC; RV-3028-C7

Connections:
+3V3: C4.1, C7.1, C12.1, C14.1, D6.1, J1.15, J1.16, L1.2, M1.1, R1.1, R2.1, R3.1, R7.1, R20.1, R23.1, TP4.1, U1.3, U2.5
+BATT: C15.1, J3.1, Q4.3, R12.1, U5.3, U6.7
BATT_ADC: C16.1, R12.2, R13.1, U1.10
BTN_BACK: SW2.2, U1.13
BTN_DOWN: SW4.2, U1.6
BTN_MENU: SW1.2, U1.12
BTN_UP: SW3.2, U1.5
CC1: J2.A5, R21.1
CC2: J2.B5, R22.1
CHRG: R16.2, U5.1
CP_NEG: C3.1, D1.1, D2.2
CP_POS: C3.2, D3.2, L1.1, Q1.3
EN: C1.1, R1.2, U1.8
EPD_BUSY: J1.9, U1.26
EPD_C5: C2.1, J1.5
EPD_C18: C6.1, J1.18
EPD_C20: C8.1, J1.20
EPD_C22: C9.1, J1.22
EPD_C24: C10.1, J1.24
EPD_CS: J1.12, U1.22
EPD_DC: J1.11, U1.24
EPD_MOSI: J1.14, U1.19
EPD_RST: J1.10, R20.2, U1.25
EPD_SCK: J1.13, U1.20
GDR: J1.2, Q1.1, R8.1
GND: C1.2, C2.2, C4.2, C5.2, C6.2, C7.2, C8.2, C9.2, C10.2, C11.1, C12.2, C15.2, C16.2, D2.1, J1.8, J1.17, J2.A1, J2.A12, J2.B1, J2.B12, J2.S1, J3.2, Q5.2, R8.2, R9.1, R13.2, R14.2, R15.1, R21.2, R22.2, SW1.1, SW2.1, SW3.1, SW4.1, TP5.1, TP6.1, U1.1, U1.2, U1.11, U1.14, U1.36, U1.37, U1.38, U1.39, U1.40, U1.41, U1.42, U1.43, U1.44, U1.45, U1.46, U1.47, U1.48, U1.49, U1.50, U1.51, U1.52, U1.53, U2.2, U3.2, U5.2, U6.5, U6.6, U6.8
LED_A: D5.1, R16.1
MOTOR_DRV: C14.2, D6.2, M1.2, Q5.3
PREVGH: C5.1, D3.1, J1.21
PREVGL: D1.2, J1.23
PROG: R15.2, U5.5
RESE: J1.3, Q1.2, R9.2
RTC_CLKOUT: TP9.1, U6.1
RTC_INT: R7.2, U1.9, U6.2
SCL: R2.2, TP2.1, U1.15, U6.3
SDA: R3.2, TP3.1, U1.16, U6.4
TP_BOOT: R23.2, TP1.1, U1.23
USB_DM: J2.A7, J2.B7, U1.17, U3.3, U3.4
USB_DP: J2.A6, J2.B6, U1.18, U3.1, U3.6
VBUS: C11.2, D4.2, D5.2, J2.A4, J2.A9, J2.B4, J2.B9, Q4.1, R14.1, U3.5, U5.4
VIB_BASE: Q5.1, R17.1
VIB_PWM: R17.2, U1.27
VSYS: D4.1, Q4.2, U2.1, U2.3

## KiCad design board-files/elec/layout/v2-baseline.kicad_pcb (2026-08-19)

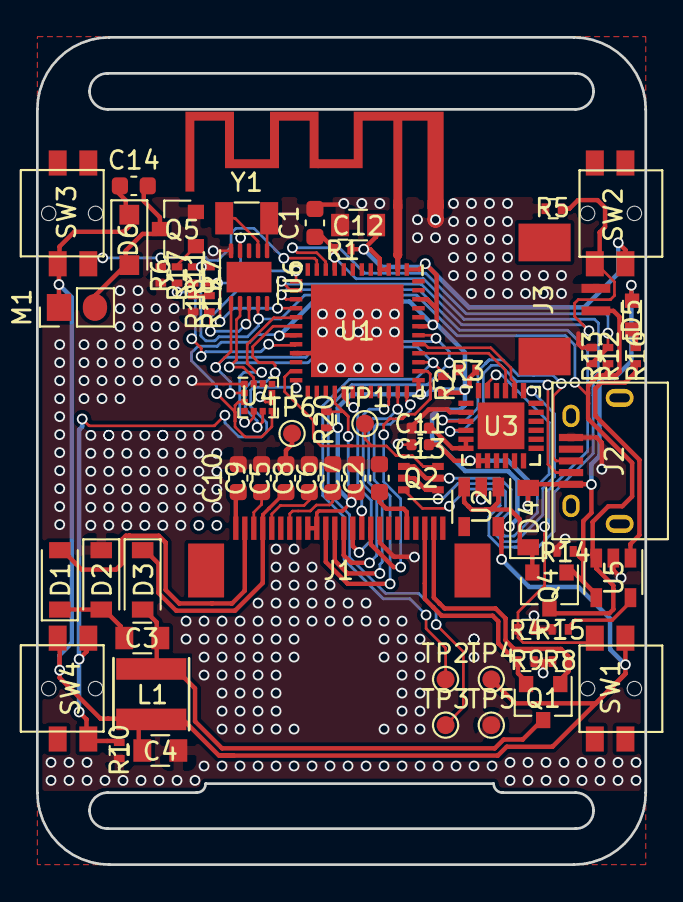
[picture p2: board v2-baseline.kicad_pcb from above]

Board: 4 copper layers, 33.8 x 46.0 mm, 67 parts (0 on the bottom side), 52 nets.

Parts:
AE1: SWRA117D
C1, C14: 100nF; C_0603_1608Metric
C2, C5, C6, C7, C8, C9, C10: 1uF/50V; C_0603_1608Metric
C3, C4, C12: 4.7uF/50V; C_0805
C11, C13: 4.7uF; C_0402_1005Metric
D1, D2, D3, D4: MBR0530; D_SOD-123
D5: LED; LED_0603
D6: 1N4001; D_SOD-123F
J1: FPC24(0.5MM); 24_Pins_0.5mm_Pitch_ZIF_Connector_UP
J2: Micro USB; USB_Micro-B
J3: Battery; 1.25T-2PWT (Molex 532610271)
L1: 10uH 1A; Inductor_Taiyo-Yuden_NR-40xx
M1: Vibration_Motor; Motor_Header
Q1: AO3400A; SOT-23
Q2: UMH3N; SOT-363_SC-70-6
Q4: CJ2301; SOT-23
Q5: S8050; SOT-23
R1, R4, R5, R6, R7, R8, R10, R14, R15: 10K; R_0402
R2, R3: 4.7K; R_0402
R9: 3; R_0402
R11: 680K; R_0402
R12, R13, R19, R20: 100K; R_0402
R16, R17: 1K; R_0402
R18: 220K; R_0402
SW1, SW2, SW3, SW4: BTN; K2-1114SA-A4SW-06
TP1: GPIO0; TestPoint_Pad_D1.0mm
TP2: SCL; TestPoint_Pad_D1.0mm
TP3: SDA; TestPoint_Pad_D1.0mm
TP4: 3V3; TestPoint_Pad_D1.0mm
TP5, TP6: GND; TestPoint_Pad_D1.0mm
U1: ESP32-PICO-D4; QFN-48-1EP_7x7mm_Pitch0.5mm
U2: ME6211C33M5G-N; SOT-23-5
U3: CP2102; QFN-24-1EP_4x4mm_Pitch0.5mm
U4: BMA423; LGA-12_2x2mm_Pitch0.5mm
U5: TP4054; SOT-23-5
U6: PCF8563BS; DFN-10-1EP_3x3mm_P0.5mm_EP1.7x2.5mm
Y1: 32.768KHz; Crystal_SMD_3215-2Pin_3.2x1.5mm

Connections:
32KHZ: R19.2, U1.13, U6.8
+3V3: C4.1, C7.1, C12.1, C14.1, D6.1, J1.15, J1.16, L1.2, M1.1, R1.1, R2.1, R3.1, R20.1, SW1.1, SW2.1, SW3.1, SW4.1, TP4.1, U1.1, U1.3, U1.4, U1.19, U1.37, U1.43, U1.46, U2.5, U4.3, U4.7
+BATT: J3.1, Q4.3, R7.1, R11.1, R12.1, U5.3, U6.9
ACC_INT_1: U1.17, U4.5
ACC_INT_2: U1.18, U4.6
ADC: R12.2, R13.1, U1.10
BTN_1: R4.2, SW1.2, U1.15
BTN_2: R5.2, SW2.2, U1.14
BTN_3: R6.2, SW3.2, U1.11
BTN_4: R10.2, SW4.2, U1.24
BUSY: J1.9, U1.38
DC: J1.11, U1.29
DTR: Q2.2, Q2.4, U3.23
EN: C1.1, Q2.6, R1.2, U1.9
GDR: J1.2, Q1.1, R8.1
GND: AE1.2, C1.2, C2.2, C4.2, C5.2, C6.2, C7.2, C8.2, C9.2, C10.2, C11.1, C12.2, C13.2, D2.1, J1.8, J1.17, J2.5, J3.2, Q5.2, R4.1, R5.1, R6.1, R8.2, R9.1, R10.1, R13.2, R14.2, R15.1, R18.2, TP5.1, TP6.1, U1.21, U1.49, U2.2, U3.2, U4.1, U4.8, U4.9, U5.2, U6.5
GPIO0: Q2.3, TP1.1, U1.23
MOSI: J1.14, U1.36
unnamed: AE1.1, U1.2
unnamed: C2.1, J1.5
unnamed: C3.1, D1.1, D2.2
unnamed: C3.2, D3.2, L1.1, Q1.3
unnamed: C6.1, J1.18
unnamed: C8.1, J1.20
unnamed: C9.1, J1.22
unnamed: C10.1, J1.24
unnamed: C13.1, U3.5, U3.6
unnamed: C14.2, D6.2, M1.2, Q5.3
unnamed: D4.1, Q4.2, U2.1, U2.3
unnamed: D5.1, R16.1
unnamed: J2.2, U3.4
unnamed: J2.3, U3.3
unnamed: Q5.1, R17.1
unnamed: R11.2, R18.1, R19.1
unnamed: R15.2, U5.5
unnamed: R16.2, U5.1
unnamed: U6.1, Y1.1
unnamed: U6.2, Y1.2
PREVGH: C5.1, D3.1, J1.21
PREVGL: D1.2, J1.23
RES: J1.10, R20.2, U1.28
RESE: J1.3, Q1.2, R9.2
RTC_INT: R7.2, U1.16, U6.4
RTS: Q2.1, Q2.5, U3.19
RX: U1.40, U3.21
SCK: J1.13, U1.35
SCL: R2.2, TP2.1, U1.39, U4.12, U6.7
SDA: R3.2, TP3.1, U1.42, U4.2, U6.6
SS: J1.12, U1.34
TX: U1.41, U3.20
VBUS: C11.2, D4.2, D5.2, J2.1, Q4.1, R14.1, U3.7, U3.8, U5.4
VIB_PWM: R17.2, U1.20

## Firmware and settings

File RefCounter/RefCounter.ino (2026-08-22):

// ---------------------------------------------------------------------------
// Watchy Ref Counter - a purpose built play clock for officiating football.
//
//   top right    hold -> start / reset the long clock  (40s by default)
//   bottom right hold -> start / reset the short clock (25s by default)
//   bottom left  hold -> on the ready screen, open the settings menu;
//                          otherwise clear the clock and go back to it
//   top left     hold -> low power mode, hold again to wake
//
// A short tap never does anything. Every tunable number lives in settings.h.
//
// This project is self-contained: it does not link against the Watchy library.
// The panel is driven through GxEPD2, the RTC chips over Wire, and NTP through
// the ESP32 core's SNTP client. Where the behaviour follows the reference
// firmware (sqfmi/Watchy) the comments say so, but none of its code is used.
// ---------------------------------------------------------------------------

#include <driver/rtc_io.h>
#include <esp_sleep.h>
#include <esp_timer.h>

#include "Buttons.h"
#include "Buzzer.h"
#include "RefDisplay.h"
#include "RefMenu.h"
#include "RefClock.h"
#include "RefSport.h"
#include "RefSyncSchedule.h"
#include "RefWifi.h"
#include "board.h"
#include "settings.h"

static RefClock refClock;

static AppState state       = STATE_IDLE;
static uint16_t durationSec = 0;
static uint16_t shownSec    = 0;

// Wall clock origin for the running countdown. Remaining time is always
// recomputed from this, never accumulated, so a blocking buzz or a slow screen
// refresh costs nothing in accuracy.
static int64_t startUs = 0;

// When the EXPIRED screen should give way back to the ready screen. Only
// meaningful while state == STATE_EXPIRED.
static uint32_t returnToIdleAt = 0;

// A manual clear redraws with a fast partial refresh so it feels immediate,
// then queues the slow ghost-clearing refresh for once things go quiet.
static bool     tidyPending = false;
static uint32_t tidyAt      = 0;

// Cached wall clock. The RTC is read over I2C at most once a second rather
// than every loop, and the header is only repainted when the minute changes.
static uint8_t  clockHour   = 0;
static uint8_t  clockMinute = 0;
static bool     clockValid  = false;
static uint32_t clockReadAt = 0;

static View currentView() {
  View v;
  v.state       = state;
  v.secondsLeft = shownSec;
  v.durationSec = durationSec;
  v.hour        = clockHour;
  v.minute      = clockMinute;
  v.clockValid  = clockValid;
  return v;
}

// Re-read the RTC at most once a second. Returns true when the displayed
// minute changed, which is the only time the header needs repainting.
static bool refreshClock() {
  const uint32_t now = millis();
  if (clockValid && (now - clockReadAt) < 1000) {
    return false;
  }
  clockReadAt = now;

  uint8_t h = clockHour, m = clockMinute;
  const bool ok = refClock.read(h, m);
  const bool changed = (ok != clockValid) || (ok && (h != clockHour || m != clockMinute));
  clockValid  = ok;
  clockHour   = h;
  clockMinute = m;
  return changed;
}

static void enterIdle(bool full) {
  state       = STATE_IDLE;
  tidyPending = false;
  refClock.noteActivity();
  RefDisplay::render(currentView(), full);
}

static void startTimer(uint16_t seconds) {
  // Take the timestamp first: the clock starts when the hold registered, not
  // after the confirmation buzz and the screen refresh have finished.
  startUs     = esp_timer_get_time();
  durationSec = seconds;
  shownSec    = seconds;
  state       = STATE_RUNNING;
  tidyPending = false;
  refClock.noteActivity();

  Buzzer::pulse(BUZZ_CONFIRM_MS);
  RefDisplay::render(currentView(), false);
}

// Abandon whatever is on the clock and go back to the ready screen. Uses a
// partial refresh so it responds straight away; the ghosting that leaves is
// cleaned up by the deferred full refresh queued here.
static void clearToIdle() {
  Buzzer::pulse(BUZZ_CONFIRM_MS);
  enterIdle(false);
  tidyPending = true;
  tidyAt      = millis() + SCREEN_TIDY_DELAY_MS;
}

// The bottom-left button does one of two things. On the ready screen there is
// no clock to clear, so it opens the reference settings menu instead; anywhere
// else it clears back to the ready screen.
static void bottomLeftHold() {
  if (state != STATE_IDLE) {
    clearToIdle();
    return;
  }
  Buzzer::pulse(BUZZ_CONFIRM_MS);
  RefMenu::open(refClock);
  refreshClock(); // the menu may have set the time or synced it
  enterIdle(true);
}

// Buzz for whatever mark the clock just landed on, using the active preset's
// numbers. Ordering matters: the per-second countdown takes precedence over
// both warnings, so a mark set inside finalCountdownFrom is silently swallowed.
static void buzzForMark(uint16_t secondsLeft) {
  const RefSport::Preset p = RefSport::active();

  if (secondsLeft == 0) {
    Buzzer::pulse(BUZZ_EXPIRE_MS);
  } else if (p.finalCountdownFrom > 0 && secondsLeft <= p.finalCountdownFrom) {
    Buzzer::pulse(BUZZ_SHORT_MS);
  } else if (WARNING_BUZZ_COUNT > 0 && p.warnAtSeconds > 0 &&
             secondsLeft == p.warnAtSeconds) {
    Buzzer::pulse(WARNING_BUZZ_COUNT, BUZZ_SHORT_MS, BUZZ_GAP_MS);
  } else if (WARNING_BUZZ_COUNT_2 > 0 && p.warn2AtSeconds > 0 &&
             secondsLeft == p.warn2AtSeconds) {
    Buzzer::pulse(WARNING_BUZZ_COUNT_2, BUZZ_SHORT_MS, BUZZ_GAP_MS);
  }
}

static void tickRunning() {
  const int64_t elapsedMs = (esp_timer_get_time() - startUs) / 1000;
  const int64_t totalMs   = (int64_t)durationSec * 1000;

  const uint16_t left =
      elapsedMs >= totalMs ? 0 : durationSec - (uint16_t)(elapsedMs / 1000);
  if (left == shownSec) {
    return;
  }
  shownSec = left;

  // Buzz before redrawing. The buzz is the cue an official acts on, and the
  // e-paper refresh would otherwise delay it by most of a second.
  buzzForMark(left);

  if (left == 0) {
    // Expiring rewrites the header and footer too, so this one is whole screen.
    state          = STATE_EXPIRED;
    returnToIdleAt = millis() + EXPIRED_HOLD_MS;
    RefDisplay::render(currentView(), false);
    return;
  }
  // Every other tick only changes the number, so only that window is repainted.
  RefDisplay::renderDigits(currentView());
}

static void deepSleepUntilButton() {
#ifdef ARDUINO_ESP32C6_DEV
  rtc_gpio_set_direction((gpio_num_t)BTN_SLEEP_PIN, RTC_GPIO_MODE_INPUT_ONLY);
  rtc_gpio_pullup_en((gpio_num_t)BTN_SLEEP_PIN);
#else
  // Stop driving the lines this sketch pulls, so none of them leaks current
  // over the hours the watch may spend asleep. The panel is already
  // hibernated, so releasing its control lines is safe.
  const uint8_t driven[] = {PIN_VIB_MOTOR,   PIN_DISPLAY_CS, PIN_DISPLAY_DC,
                            PIN_DISPLAY_RST, PIN_SPI_SCK,    PIN_SPI_MOSI};
  for (uint8_t pin : driven) {
    pinMode(pin, INPUT);
  }
#endif
  // Idle light sleep and the display driver's busy-wait both leave GPIO wake
  // armed, and GPIO is not a valid deep sleep source on the ESP32. Clear
  // everything first so ext1 is the only way back up.
  esp_sleep_disable_wakeup_source(ESP_SLEEP_WAKEUP_ALL);
  esp_sleep_enable_ext1_wakeup(BIT64(BTN_SLEEP_PIN), BTN_EXT1_WAKE_MODE);

  // Also arm a timer wake against the resync schedule, so the watch can pull
  // itself out of deep sleep to correct RTC drift rather than waiting for the
  // next button press, which might be hours past due. setup() recognises this
  // wake cause and syncs quietly before going straight back to sleep.
  const uint32_t untilSync = refClock.secondsUntilSyncDue();
  if (untilSync != RefSyncSchedule::NEVER) {
    // Clamp: an already-due sync would otherwise ask for a zero length timer.
    const uint32_t secs = untilSync < 60 ? 60 : untilSync;
    esp_sleep_enable_timer_wakeup((uint64_t)secs * 1000000ULL);
  }

  esp_deep_sleep_start();
}

static void enterSleep() {
  Buzzer::off();
  state = STATE_SLEEPING;

  // The hold that triggered sleep already counted as activity, but sleep
  // entry gets its own stamp too, since it is the moment the watch actually
  // goes quiet and the resync schedule should count its wait from.
  refClock.noteActivity();
  RefDisplay::renderSleeping();
  RefDisplay::hibernate();

  // Otherwise the button we are still holding wakes us straight back up.
  Buttons::waitForRelease();
  deepSleepUntilButton();
}

// Doze between button polls while nothing is counting down. This is where the
// watch spends most of a game, so it is worth the extra care.
static void idleSleep() {
  if (!LIGHT_SLEEP_WHEN_IDLE) {
    delay(BUTTON_POLL_MS);
    return;
  }

  // Buttons owns the pins' interrupt configuration, so it owns the arming too.
  Buttons::armLightSleepWake();
  // Timer wake as a backstop: if a GPIO wake is ever missed, the cost is one
  // poll interval rather than a watch that ignores its buttons.
  esp_sleep_enable_timer_wakeup((uint64_t)IDLE_SLEEP_MS * 1000ULL);

  esp_light_sleep_start();

  Buttons::disarmLightSleepWake();
  esp_sleep_disable_wakeup_source(ESP_SLEEP_WAKEUP_TIMER);
}

static void idleTick() {
  const bool busy = Buttons::anyDown();

  if (state == STATE_EXPIRED) {
    // Hold 00 on screen a moment, then fall back to the ready screen. Waiting
    // for the buttons to be clear keeps the 2.6s full refresh from swallowing
    // a hold that is already under way.
    if (!busy && (int32_t)(millis() - returnToIdleAt) >= 0) {
      enterIdle(true);
    } else {
      delay(BUTTON_POLL_MS);
    }
    return;
  }
  if (tidyPending) {
    if (!busy && (int32_t)(millis() - tidyAt) >= 0) {
      tidyPending = false;
      RefDisplay::render(currentView(), true);
    } else {
      delay(BUTTON_POLL_MS);
    }
    return;
  }
  if (busy) {
    refClock.noteActivity();
    delay(BUTTON_POLL_MS);
    return;
  }

  if (refreshClock()) {
    RefDisplay::renderHeader(currentView());
  }

  // Correct RTC drift, but only once the watch has been left alone for hours:
  // bringing the radio up blocks for several seconds.
  if (refClock.syncDue()) {
    refClock.connectAndSync();
    refClock.noteActivity();
    clockValid = false; // force a re-read at the new time
    if (refreshClock()) {
      RefDisplay::renderHeader(currentView());
    }
    return;
  }

  idleSleep();
}

void setup() {
  if (CPU_FREQ_MHZ > 0) {
    setCpuFrequencyMhz(CPU_FREQ_MHZ);
  }
  Buzzer::begin();
  Buttons::begin();
  RefSport::begin();
  RefWifi::begin();

  // A timer wake means deepSleepUntilButton() pulled the watch out of deep
  // sleep on its own, purely to resync the RTC. The SLEEPING screen is still
  // sitting on the panel from before, so this path must not touch the
  // display at all -- bringing it up would flash the panel awake for a
  // moment nobody asked to see.
  const esp_sleep_wakeup_cause_t cause = esp_sleep_get_wakeup_cause();
  const bool resyncWake = (cause == ESP_SLEEP_WAKEUP_TIMER);
  if (!resyncWake) {
    RefDisplay::begin();
  }
  refClock.begin(cause == ESP_SLEEP_WAKEUP_UNDEFINED);

  if (resyncWake) {
    refClock.connectAndSync();
    // Re-anchor the quiet period, exactly as the awake path does after its
    // own sync. Otherwise the schedule still reads as due the moment this
    // wake ends, and with NTP_MIN_SYNC_INTERVAL_HOURS set to 0 the watch
    // would wake, sync and re-sleep on the timer's one minute floor until the
    // battery was flat. Stamping after the sync cannot suppress that sync.
    refClock.noteActivity();
    // anyDown() reads debounced state from the last poll(), which is still
    // whatever it was before the multi-second sync ran. Poll once now so a
    // press held throughout the sync is actually seen: poll() debounces off
    // the ISR's edge timestamp, not the time of the poll, so a press from
    // seconds ago clears BUTTON_DEBOUNCE_MS on this first call.
    Buttons::poll();
    if (!Buttons::anyDown()) {
      deepSleepUntilButton(); // never returns
    }
    // That same edge timestamp now has to be thrown away. The press was
    // measured from its real moment of contact, seconds back inside the sync,
    // so the main loop would see a hold that had long since passed its
    // threshold and act on it at once -- putting the watch straight back to
    // sleep, or starting a clock nobody asked for. Re-seed the debounce state
    // instead, as RefMenu does after reading the pins behind Buttons' back.
    Buttons::resync();
    // The sleep button is down now that the sync has finished. Rather than
    // trying to queue that press, fall through into a normal start; the
    // watch simply wakes up instead of going back to sleep.
    RefDisplay::begin();
  }

  refreshClock();

  // Full refresh on the way in, whether this is a cold boot or a wake from
  // low power mode, so the panel starts clean.
  enterIdle(true);
}

void loop() {
  Buttons::poll();

  if (Buttons::heldFor(Buttons::SLEEP, SLEEP_HOLD_MS)) {
    enterSleep();
    return;
  }
  if (Buttons::heldFor(Buttons::LONG_TIMER, TIMER_HOLD_MS)) {
    startTimer(RefSport::active().longSeconds);
    return;
  }
  if (Buttons::heldFor(Buttons::SHORT_TIMER, TIMER_HOLD_MS)) {
    startTimer(RefSport::active().shortSeconds);
    return;
  }
  if (Buttons::heldFor(Buttons::RESET, TIMER_HOLD_MS)) {
    bottomLeftHold();
    return;
  }

  if (state == STATE_RUNNING) {
    tickRunning();
    delay(BUTTON_POLL_MS);
  } else {
    idleTick();
  }
}

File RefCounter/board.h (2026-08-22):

#ifndef REF_BOARD_H
#define REF_BOARD_H

// ---------------------------------------------------------------------------
// Watchy hardware map.
//
// This repo is self-contained: it does not link against the Watchy library.
// The pin numbers, button polarity and battery divider ratios below are facts
// about the hardware, and were read off the schematics and the pin map in the
// reference firmware, sqfmi/Watchy (MIT licence), by way of credit. No code
// from that project is used here.
//
// The revision is selected by the build: ARDUINO_WATCHY_V20 for the Watchy
// V2.0 (ESP32), ARDUINO_ESP32C6_DEV for this repo's own ESP32-C6-MINI-1
// board. See platformio.ini.
// ---------------------------------------------------------------------------

#include <Arduino.h>

// PlatformIO sets the revision from platformio.ini. The Arduino IDE has no
// build-flag field, so IDE users on a V2.0 uncomment the line below -- it has
// to live in this header, which every source file includes, rather than in
// the .ino, which only sets it for itself.
//
// #define ARDUINO_WATCHY_V20
//
// The C6 board needs nothing: selecting an ESP32-C6 board defines
// ARDUINO_ESP32C6_DEV.

// V1.0, V1.5 and V3 are no longer supported. The two V1 revisions put the up
// button and the battery tap on other pins than V2.0's -- 32/33 on V1.0 and
// 32/35 on V1.5, against 35/34 here -- and V3 is an ESP32-S3, a different pin
// map entirely, so the V2.0 numbers mean nothing on it (GPIO 26 is already
// tied up by the SPI flash on S3 modules). Quietly falling through to that
// map would read the battery off the wrong pin and never see the up button,
// so a stale build flag, an old #define left in this file, or simply picking
// an S3 board stops the build instead.
#if defined(ARDUINO_WATCHY_V10) || defined(ARDUINO_WATCHY_V15) ||              \
    defined(ARDUINO_ESP32S3_DEV)
#error "Watchy V1.0, V1.5 and V3 are no longer supported; build watchy_v2 or watchy_c6"
#endif

#if !defined(ARDUINO_ESP32C6_DEV) && !defined(ARDUINO_WATCHY_V20)
#warning "No Watchy revision defined; assuming V2.0"
#define ARDUINO_WATCHY_V20
#endif

#ifdef ARDUINO_ESP32C6_DEV
// --- watchy-ref-counter's own board (ESP32-C6-MINI-1 / RV-3028-C7) ---------
// What the About screen calls this board. The two supported boards do not
// share a numbering scheme -- one is a Watchy revision and one is this repo's
// own design -- so the screen prints a name rather than a number.
#define BOARD_NAME "C6"

// Every number here comes from board-files/elec/src/watchy.ato. Change them
// there and here together; board-files/checks/netlist_check.py asserts the
// netlist half, and nothing asserts this half.
//
// The C6 brings out 22 GPIO and only IO0-IO7 can wake it from deep sleep, so
// the four buttons and the RTC alarm take five of those eight and everything
// else lives higher up. See mcu.ato for the datasheet citations.
#define PIN_I2C_SDA 7
#define PIN_I2C_SCL 6

// The six display signals are assigned so that they leave the module in the
// same left-to-right order the panel's FPC presents them, which is what makes
// the fan-out planar. MISO is a spare, unconnected pin: the panel is
// write-only and nothing drives the line.
#define PIN_SPI_SCK  15
#define PIN_SPI_MISO 23
#define PIN_SPI_MOSI 14
#define PIN_SPI_SS   8

// IO0-IO3. All four are LP GPIOs, so one ESP_EXT1_WAKEUP_ANY_LOW mask covers
// them and the RTC alarm on IO4.
#define PIN_BTN_MENU 0
#define PIN_BTN_BACK 1
#define PIN_BTN_UP   2
#define PIN_BTN_DOWN 3

#define PIN_DISPLAY_CS   8
#define PIN_DISPLAY_DC   18
#define PIN_DISPLAY_RST  19
#define PIN_DISPLAY_BUSY 20

#define PIN_VIB_MOTOR 21
#define PIN_BATT_ADC  5

// Buttons pull their pin low when pressed.
#define BTN_PRESSED_LEVEL          LOW
#define BTN_EXT1_WAKE_MODE         ESP_EXT1_WAKEUP_ANY_LOW
#define BTN_LIGHT_SLEEP_WAKE_LEVEL GPIO_INTR_LOW_LEVEL

// 1M/1M divider: 2:1, and 2.1uA of standing drain against V2.0's 21uA.
#define BATT_DIVIDER 2.0f

#else
// --- Watchy V2.0 (ESP32) ---------------------------------------------------
#define BOARD_NAME "V2.0"

#define PIN_I2C_SDA 21
#define PIN_I2C_SCL 22

#define PIN_SPI_SCK  18
#define PIN_SPI_MOSI 23

#define PIN_BTN_MENU 26
#define PIN_BTN_BACK 25
#define PIN_BTN_DOWN 4
#define PIN_BTN_UP   35

#define PIN_DISPLAY_CS   5
#define PIN_DISPLAY_RST  9
#define PIN_DISPLAY_DC   10
#define PIN_DISPLAY_BUSY 19

#define PIN_VIB_MOTOR 13
#define PIN_BATT_ADC  34

// Buttons pull their pin high when pressed.
#define BTN_PRESSED_LEVEL          HIGH
#define BTN_EXT1_WAKE_MODE         ESP_EXT1_WAKEUP_ANY_HIGH
#define BTN_LIGHT_SLEEP_WAKE_LEVEL GPIO_INTR_HIGH_LEVEL

// Battery is measured through a plain 2:1 divider.
#define BATT_DIVIDER 2.0f

#endif

// --- Panel -----------------------------------------------------------------
#define DISPLAY_WIDTH  200
#define DISPLAY_HEIGHT 200
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

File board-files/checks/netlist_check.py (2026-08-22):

#!/usr/bin/env python3
"""Assert the things a netlist can be made to prove.

Reads the KiCad netlist atopile writes to build/default.net and checks:

  * the pin map, verbatim from the spec
  * that everything on the ext1 wake mask sits on an RTC GPIO
  * that the battery tap sits on ADC1
  * that no signal but the documented `TP_BOOT` test pad touches IO9, the
    boot strapping pin
  * that each USB-C CC pin has its own 5.1k pulldown, and that both halves of
    D+ and of D- are tied
  * the RV-3028-C7's supply arrangement
  * that the I2C and interrupt pull-ups go to +3V3 and not +BATT
  * that the buttons are active low with no external pull-downs left over
  * that the battery divider is 1M/1M with a filter cap
  * that the blocks carried over from watchy-hardware v2.0 are still wired
    exactly as V2 wires them
  * that the parts this board deletes stay deleted

None of this says the board works. No board has been fabricated. These are
consistency checks against the spec, nothing more.

    ./checks/netlist_check.py build/default.net
"""

import re
import sys

# --------------------------------------------------------------------------
# ESP32-C6-MINI-1 datasheet v1.5 Table 3-1. Pad number -> GPIO name.
MINI1_PADS = {
    5: "IO2", 6: "IO3", 8: "EN", 9: "IO4", 10: "IO5", 12: "IO0", 13: "IO1",
    15: "IO6", 16: "IO7", 17: "IO12", 18: "IO13", 19: "IO14", 20: "IO15",
    22: "IO8", 23: "IO9", 24: "IO18", 25: "IO19", 26: "IO20", 27: "IO21",
    28: "IO22", 29: "IO23", 30: "IO17", 31: "IO16",
}
MINI1_GND_PADS = {1, 2, 11, 14} | set(range(36, 54))
MINI1_VDD_PAD = 3
MINI1_EN_PAD = 8
# Pads 4, 7, 21 and 32-35 are NC and carry nothing.
MINI1_NC_PADS = {4, 7, 21, 32, 33, 34, 35}

# Only IO0-IO7 are LP (RTC) GPIOs, so only they can wake the chip from deep
# sleep. Everything else is light-sleep only.
RTC_GPIOS = {"IO%d" % n for n in range(0, 8)}
# ADC1_CH0..CH6 only. The C6 has no usable second ADC while WiFi is running.
ADC1_GPIOS = {"IO%d" % n for n in range(0, 7)}
# Boot strapping pins (Table 4-3). IO9 must be high when reset is released or
# the chip comes up in download mode; IO8 is "Any value" for SPI boot, so it
# is a normal GPIO here. MTMS (IO4), MTDI (IO5) and IO15 are latched too but
# only select the SDIO clock edge and the JTAG source, neither of which this
# design uses -- see elec/src/mcu.ato.
STRAPPING = {"IO9"}

MCU = "U1"
RTC = "U6"
USB = "J2"

# The spec's pin map, verbatim.
PIN_MAP = {
    "BTN_UP": "IO2",
    "BTN_DOWN": "IO3",
    "RTC_INT": "IO4",
    "BTN_MENU": "IO0",
    "BTN_BACK": "IO1",
    "BATT_ADC": "IO5",
    "SCL": "IO6",
    "SDA": "IO7",
    "USB_DM": "IO12",
    "USB_DP": "IO13",
    "EPD_MOSI": "IO14",
    "EPD_SCK": "IO15",
    "EPD_CS": "IO8",
    "EPD_DC": "IO18",
    "EPD_RST": "IO19",
    "EPD_BUSY": "IO20",
    "VIB_PWM": "IO21",
    "TP_BOOT": "IO9",
}

# The display fan-out is only planar if these six leave the module in the
# same left-to-right order the panel's FPC presents them. Pad number order
# round the module is the physical order: bottom row left to right, then up
# the right column.
EPD_FANOUT = [(19, "EPD_MOSI"), (20, "EPD_SCK"), (22, "EPD_CS"),
              (24, "EPD_DC"), (25, "EPD_RST"), (26, "EPD_BUSY")]

BUTTON_NETS = ["BTN_MENU", "BTN_BACK", "BTN_UP", "BTN_DOWN"]
BUTTON_SWITCHES = {"SW1": "BTN_MENU", "SW2": "BTN_BACK",
                   "SW3": "BTN_UP", "SW4": "BTN_DOWN"}

# RV-3028-C7 pin numbers, datasheet "Pin description".
RV3028 = {"CLKOUT": 1, "INT": 2, "SCL": 3, "SDA": 4, "VSS": 5,
          "VBACKUP": 6, "VDD": 7, "EVI": 8}
RV3028_EXPECT = {"VDD": "+BATT", "VSS": "GND", "VBACKUP": "GND", "EVI": "GND",
                 "INT": "RTC_INT", "SDA": "SDA", "SCL": "SCL"}

BANNED_VALUES = ["ESP32-PICO-D4", "CP2102", "BMA423", "PCF8563",
                 "UMH3N", "SWRA117D", "32.768"]

# Blocks carried over from sqfmi/watchy-hardware v2.0 unchanged. Generated
# from V2's Watchy.kicad_pcb, with V2's anonymous Net-(...) names mapped to
# the readable ones this design uses. Any difference here means a block that
# was meant to be transcribed verbatim has drifted.
V2_CARRIED = {
    "C1": {"1": "EN", "2": "GND"},
    "C2": {"1": "EPD_C5", "2": "GND"},
    "C3": {"1": "CP_NEG", "2": "CP_POS"},
    "C4": {"1": "+3V3", "2": "GND"},
    "C5": {"1": "PREVGH", "2": "GND"},
    "C6": {"1": "EPD_C18", "2": "GND"},
    "C7": {"1": "+3V3", "2": "GND"},
    "C8": {"1": "EPD_C20", "2": "GND"},
    "C9": {"1": "EPD_C22", "2": "GND"},
    "C10": {"1": "EPD_C24", "2": "GND"},
    "C11": {"1": "GND", "2": "VBUS"},
    "C12": {"1": "+3V3", "2": "GND"},
    "C14": {"1": "+3V3", "2": "MOTOR_DRV"},
    "D1": {"1": "CP_NEG", "2": "PREVGL"},
    "D2": {"1": "GND", "2": "CP_NEG"},
    "D3": {"1": "PREVGH", "2": "CP_POS"},
    "D4": {"1": "VSYS", "2": "VBUS"},
    "D5": {"1": "LED_A", "2": "VBUS"},
    "D6": {"1": "+3V3", "2": "MOTOR_DRV"},
    "J1": {"2": "GDR", "3": "RESE", "5": "EPD_C5", "8": "GND",
           "9": "EPD_BUSY", "10": "EPD_RST", "11": "EPD_DC", "12": "EPD_CS",
           "13": "EPD_SCK", "14": "EPD_MOSI", "15": "+3V3", "16": "+3V3",
           "17": "GND", "18": "EPD_C18", "20": "EPD_C20", "21": "PREVGH",
           "22": "EPD_C22", "23": "PREVGL", "24": "EPD_C24"},
    "J3": {"1": "+BATT", "2": "GND"},
    "L1": {"1": "CP_POS", "2": "+3V3"},
    "M1": {"1": "+3V3", "2": "MOTOR_DRV"},
    "Q1": {"1": "GDR", "2": "RESE", "3": "CP_POS"},
    "Q4": {"1": "VBUS", "2": "VSYS", "3": "+BATT"},
    "Q5": {"1": "VIB_BASE", "2": "GND", "3": "MOTOR_DRV"},
    "R1": {"1": "+3V3", "2": "EN"},
    "R2": {"1": "+3V3", "2": "SCL"},
    "R3": {"1": "+3V3", "2": "SDA"},
    "R8": {"1": "GDR", "2": "GND"},
    "R9": {"1": "GND", "2": "RESE"},
    "R14": {"1": "VBUS", "2": "GND"},
    "R15": {"1": "GND", "2": "PROG"},
    "R16": {"1": "LED_A", "2": "CHRG"},
    "R17": {"1": "VIB_BASE", "2": "VIB_PWM"},
    "R20": {"1": "+3V3", "2": "EPD_RST"},
    "TP2": {"1": "SCL"},
    "TP3": {"1": "SDA"},
    "TP4": {"1": "+3V3"},
    "TP5": {"1": "GND"},
    "TP6": {"1": "GND"},
    "U2": {"1": "VSYS", "2": "GND", "3": "VSYS", "5": "+3V3"},
    "U5": {"1": "CHRG", "2": "GND", "3": "+BATT", "4": "VBUS", "5": "PROG"},
}

# V2's four button pull-downs. Active-low buttons use the S3's internal
# pull-ups instead, so these must be gone.
V2_BUTTON_PULLDOWNS = ["R4", "R5", "R6", "R10"]
# V2's CLKOUT attenuator, which fed the PICO-D4 its external 32kHz slow clock.
V2_CLKOUT_ATTENUATOR = ["R11", "R18", "R19"]


# --------------------------------------------------------------------------
_TOKENS = re.compile(r'\(|\)|"(?:[^"\\]|\\.)*"|[^\s()]+')
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

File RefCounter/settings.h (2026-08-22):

#ifndef REF_SETTINGS_H
#define REF_SETTINGS_H

// ---------------------------------------------------------------------------
// Every tunable value for the ref play clock lives here. Change a value,
// reflash, done. Nothing else in the sketch hard-codes these numbers.
// ---------------------------------------------------------------------------

#include <stdint.h>

static const char REF_COUNTER_VERSION[] = "1.1";

// --- Sport preset ----------------------------------------------------------
// Which preset the watch starts on. This is only the starting point: the
// menu's "Sport" entry picks one on the watch and stores it, and from then on
// the stored value wins. Must match one of the names in RefSport.cpp, which
// are:
//
//   Football   Lacrosse   Base NCAA  Base NFHS  Soft NCAA  Soft NFHS  Custom
//
static const char DEFAULT_SPORT[] = "Football";

// Factory values for the menu's "Custom" slot, likewise overridden once "Edit
// Custom" has been used. Clocks are 1..199 seconds; the three marks are
// 0..199, where 0 means off. All three marks are in seconds *remaining*.
static const uint16_t CUSTOM_LONG_SECONDS  = 40;
static const uint16_t CUSTOM_SHORT_SECONDS = 25;
static const uint16_t CUSTOM_WARN_SECONDS  = 10;
static const uint16_t CUSTOM_WARN2_SECONDS = 0;
static const uint16_t CUSTOM_FINAL_FROM    = 5;

// --- Button hold thresholds ------------------------------------------------
// How long a right-hand button must be held before it starts (or restarts)
// its clock. A short tap is deliberately ignored so a bumped button during a
// game cannot reset the play clock.
static const uint32_t TIMER_HOLD_MS = 500;

// How long the top-left button must be held to drop into low power mode.
// Kept longer than TIMER_HOLD_MS so the two are hard to confuse.
static const uint32_t SLEEP_HOLD_MS = 1000;

// --- Buzzer ----------------------------------------------------------------
// Single long buzz when the clock reaches zero.
static const uint32_t BUZZ_EXPIRE_MS = 1000;

// Early warning: when a preset's first mark is reached, buzz this many times;
// its second mark buzzes WARNING_BUZZ_COUNT_2 times. Either may be 0 to
// silence that mark for every preset at once. Which second each mark falls on
// is per-sport and lives in RefSport.cpp; the menu's "Edit Custom" screen sets
// them for the Custom preset.
//
// Note: a mark at or below a preset's final-countdown value is swallowed by
// the per-second countdown, which buzzes there anyway.
static const uint8_t WARNING_BUZZ_COUNT   = 1;
static const uint8_t WARNING_BUZZ_COUNT_2 = 2;

// Length of a short buzz, and the silent gap between repeats.
static const uint32_t BUZZ_SHORT_MS = 150;
static const uint32_t BUZZ_GAP_MS   = 120;

// Tiny confirmation buzz the instant a hold registers, so you know the clock
// started without looking at the watch. Set to 0 to disable.
static const uint32_t BUZZ_CONFIRM_MS = 60;

// --- Display ---------------------------------------------------------------
// false = black digits on a white background. true = white on black, the way
// the stock Watchy 7_SEG face ships. This drives the panel border too.
static const bool DARK_MODE = true;

// How long `00` stays up after a clock expires before the watch drops back to
// the ready screen. That return is a full refresh, so it doubles as the ghost
// clear after a run of partial updates - deferred to here deliberately, so the
// 2.6s stall never lands in the middle of live play.
//
// Starting a new clock during this window cancels the return.
static const uint32_t EXPIRED_HOLD_MS = 3000;

// Clearing with the bottom-left button redraws instantly with a partial
// refresh so it feels immediate. That leaves ghosting behind, so a full
// refresh follows once this long has passed with nothing happening. Starting a
// clock cancels it, so the tidy-up never interrupts play.
static const uint32_t SCREEN_TIDY_DELAY_MS = 3000;

// --- Clock, menu and NTP ---------------------------------------------------
// The time shows at the top left of every screen. It comes from the watch's
// real time clock chip, which keeps running through low power mode and through
// a reflash.
static const bool CLOCK_24_HOUR = false;

// Time zone. This is only the starting point: the menu's "TZ" entry picks a
// zone on the watch and stores it, and from then on the stored value wins.
// Must match one of the names in RefZone.cpp, which are:
//
//   Eastern   Central   Mountain  Arizona   Pacific   Alaska
//   Aleutian  Hawaii    Samoa     Atlantic  Chamorro
//
// Arizona, Hawaii, Samoa, Atlantic (Puerto Rico and the USVI) and Chamorro
// (Guam and the Northern Marianas) do not observe daylight saving.
static const char DEFAULT_TIME_ZONE[] = "Eastern";
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

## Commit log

2026-08-18 add reset button and fix orientation for sleep button
    [Buttons.cpp, RefCounter.ino, board.h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]
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2026-08-18 fix: remove final-countdown from picker marks line; add missing comments
    [RefMenu.cpp]
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2026-08-18 docs+test: fix review round 1 — label, coverage claim, stale defaults
    - README: Edit Custom field list said "Final from"; the shipped label is
    "Final" (RefMenu.cpp's customFieldLabel default case).
    - segments_test: the exhaustive off-panel-edge check only ran STYLE_BIG;
    STYLE_SMALL (what the Ready screen actually draws both clocks in, up to
    199 on Custom) was checked at a single value. Extended the loop to check
    both styles for every value 0..199, aggregated into one summary line per
    style so passing output stays readable. README's Testing section now
    describes exactly what the test covers.
    - README Configuring sample block had stale values predating this branch:
    DARK_MODE sh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
2026-08-19 fix: review round 2 — description cap, editCustom timeout, ceiling assert
    - RefSport.h/spec/plan/sport_test: the documented description cap was 17,
    carried over from RefZone::region. pickSport draws the description and
    the position counter on the same baseline (y=180); with 7 presets the
    counter is always 3 glyphs starting at x=165, so the real ceiling is 14
    glyphs (ending at 156) -- 15 would already touch the counter. No shipped
    description exceeds 13. Corrected the cap and the reasoning behind it in
    all four places it's stated.
    - RefMenu.cpp editCustom: every other menu screen honours MENU_TIMEOUT_MS
    except this one, which looped forever with no cancel (BACK is inert on
    t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
    [RefMenu.cpp]
2026-08-19 fix: time out the Set Time screen instead of holding the panel forever
    Set Time looped unconditionally, repainting the whole panel with a partial
    refresh roughly twice a second. Its only exit was pressing MENU through all
    five fields -- BACK is inert on the first one, so there was no cancel either.
    A screen opened by accident and put back in a bag would keep refreshing until
    the cell went flat.
    It now bails after MENU_TIMEOUT_MS with nothing pressed, the same rule every
    picker already followed and the one the README already promised for the menu
    itself.
    The RTC write sits after the loop, so a timeout would have fallen straight
    into it and stored a half-finished time. A `committed` flag, se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
    [RefMenu.cpp]
2026-08-19 docs: plan for anchoring the NTP resync to activity
    Records the approved design: NTP_RESYNC_HOURS becomes a quiet period
    measured from the last button press or sleep entry, and a second setting
    floors how often a sync may run at all.
2026-08-19 Add RefSyncSchedule: pure due-time arithmetic for auto NTP resync
    RefClock.cpp cannot compile on the host (WiFi.h, Wire.h, esp_sntp.h),
    so the resync due-time calculation that a later change will re-anchor
    to activity instead of last sync moves into its own module, alongside
    RefZone and RefSegments, where it can be host-tested.
    Task 1 of the ntp-resync-anchor plan. Wiring this into RefClock and
    the sketch is deliberately left for a later task.
2026-08-19 Re-anchor NTP resync to idle time, not last sync
    RefClock now tracks lastActivity (survives deep sleep, like the
    existing sync bookkeeping) and gains noteActivity(), syncDue()
    rewritten around the two-condition schedule, and
    secondsUntilSyncDue() for arming the deep-sleep timer. The
    arithmetic itself lives in RefSyncSchedule (Task 1); RefClock only
    supplies the RTC-backed state and the unset-RTC one-shot guard.
    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
2026-08-19 Drive the resync schedule from the sketch, wake to sync silently
    RefCounter.ino now calls RefClock::noteActivity() on every button-
    driven state change and on sleep entry, replacing the local
    lastActivityAt/AUTO_SYNC_IDLE_MS gate with the schedule's own
    quiet-and-floor rule (refClock.syncDue()). AUTO_SYNC_IDLE_MS is
    deleted from settings.h along with its comment, its only use.
    deepSleepUntilButton() arms a timer wake against
    refClock.secondsUntilSyncDue(), clamped to at least 60s, alongside
    the existing ext1 button wake. setup() branches on
    esp_sleep_get_wakeup_cause(): a timer wake means the watch pulled
    itself out of deep sleep purely to resync, so it skips
    RefDisplay::begin() (the SLEEPI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
    [RefCounter.ino, settings.h]
2026-08-19 Fix: poll buttons before the resync-wake anyDown() check
    anyDown() reads Buttons' debounced `stable` state, which is only
    updated by poll(). The resync-wake branch in setup() checked it
    right after refClock.connectAndSync() -- a multi-second blocking
    call -- with no poll() in between, so it saw whatever the button
    state was before the sync started, not after. A press held through
    the sync window was therefore invisible, sending the watch back to
    deep sleep with the button physically down at the ext1 trigger
    level: the opposite of the intended "fall through into a normal
    start" behaviour.
    One Buttons::poll() call before the check is sufficient: poll()
    debounces off the ISR's edge timestamp,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
    [RefCounter.ino]
2026-08-19 Fix resync wake hazards and halve the idle RTC reads
    Four fixes from the final branch review, all on the automatic NTP
    resync path:
    - setup() now calls Buttons::resync() once a press is seen at the end
    of a resync wake. The press is debounced in from its real contact
    time, seconds back inside the sync, so the first loop() iteration
    would otherwise read it as an expired hold and act on it -- sleeping
    the watch again the instant it woke, against spec decision 4.
    - setup() re-anchors activity after the resync-wake sync, as the awake
    path already does. Without it, NTP_MIN_SYNC_INTERVAL_HOURS = 0 leaves
    the schedule permanently due and the watch wakes, syncs and re-sleeps
    on the ti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
    [RefClock.cpp, RefCounter.ino]
2026-08-19 feat: remember whether WiFi has ever been set up
    A single bool in NVS, written by the Setup WiFi screen and read by the menu,
    so deciding whether to offer Sync NTP costs no radio power. Follows the
    RefZone shape: cached in RAM, loaded once by begin(), written through on
    change, its own NVS namespace.
2026-08-19 feat: give the menu's row list its own host-tested module
    The order, the labels and the new Sync NTP visibility rule move out of
    RefMenu.cpp, which cannot be built off the watch. Following the RefSegments
    precedent: the logic that is cheap to check on a host and expensive to check
    on hardware gets its own translation unit.
    Sync NTP is left out of the list until WiFi credentials have been saved, and
    slotOf() is what lets the highlight follow a row when it appears or vanishes.
2026-08-19 feat: reorder the settings menu, gate Sync NTP on WiFi, drop the buzz test
    The menu now opens on About and runs About, Sync NTP, TZ, DST, Set Time,
    Setup WiFi, Sport, Edit Custom. The two sport rows move to the bottom: they
    are set once for the season, where everything above them is read or adjusted
    in the field.
    Sync NTP is only listed once Setup WiFi has connected, since with no
    credentials stored it could only ever report a failure. The highlight index is
    now a slot into the visible-row list rather than an Item id, and the list is
    rebuilt after every action -- running Setup WiFi inserts a row above itself,
    so the highlight has to follow the item, not the slot number.
    Vibrate Motor and s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
    [RefCounter.ino, RefMenu.cpp]
2026-08-19 Add the S3-MINI-1 / RV-3028-C7 board spec and plan
    A Watchy-compatible board that pairs V3's silicon with V2's independent
    timekeeping: an ESP32-S3-MINI-1 module in place of the PICO-D4, an
    RV-3028-C7 in place of the PCF8563, no CP2102, no BMA423, and USB-C.
    Derived from sqfmi/watchy-hardware v2.0 (MIT), which supplies the e-paper,
    charging, power and motor circuitry unchanged.
    The spec records the decisions and their reasoning -- why the module rather
    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
2026-08-19 board: add the S3-MINI-1 / RV-3028-C7 design as atopile source
    The board is defined in code under board-files/elec/src/ and compiled to a
    KiCad netlist, rather than drawn. KiCad 8+ is unavailable in this environment
    (the proxy denies the PPA, leaving 7.0.11), which rules out kicad-cli's ERC
    and DRC, and there is no GUI to draw a schematic in.
    Electrically: the PICO-D4 becomes an ESP32-S3-MINI-1, buttons move to IO4-IO7
    and go active low alongside RTC_INT on IO8 in one ext1 ANY_LOW mask, and no
    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
    [BOM.csv, watchy-ref-s3.kicad_pcb]
2026-08-19 board: apply the netlist to the PCB headlessly, and verify it
    KiCad's netlist import is a GUI dialog and kicad-cli has no equivalent, so
    scripts/apply_netlist.py does that job with pcbnew. The part that mattered
    was preserving placement: V2's footprints carry KiCad 5 library names, so a
    naive delete-and-re-add loses V2's coordinates for 39 parts over what is
    mostly just a rename. It now records each pose and restores it.
    It also adds and places the new parts, assigns all 249 pads across 73 nets,
    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
    [watchy-ref-s3.kicad_pcb]
2026-08-19 board: place the displaced parts by anchoring them to the pad they serve
    The module and the USB-C displaced seven of V2's parts. Rather than reporting
    them and stopping, apply_netlist.py now anchors each to the pad it actually
    serves -- C12 to the module's 3V3 pad, C1 and R1 to EN, R7 to the RTC's INT
    pin, Q5 to the motor pads, U2 and D4 to Q4 -- and takes the nearest clear
    spot to it. Five land within 3.5mm. U2 and D4 land 11mm and 12.8mm out
    because the area around the charger is dense; both carry DC rather than a
    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
    [v2-baseline.kicad_pcb, watchy-ref-s3.kicad_pcb]
2026-08-19 intial board work
    [BOM.csv, watchy-ref-c6.kicad_pcb, watchy-ref-s3.kicad_pcb]
2026-08-22 feat: set the clock from a phone over Bluetooth, alongside NTP
    A second outside time source for the watch, for the case WiFi does not
    cover: a field with no network you have credentials for, and a phone in
    your pocket that knows the time.
    The watch is the peripheral. While the new "Sync BT" menu screen is open
    it advertises the standard Current Time Service (0x1805) and a phone
    writes the time into it -- Gadgetbridge does that by itself, nRF Connect
    does it by hand. The other direction does not work: neither iOS nor
    Android hands its clock to a peripheral that asks for it.
    Three pieces, split the way the rest of the project splits:
    RefCtsTime the 0x2A2B and 0x2A0F byte layouts and the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
    [RefClock.cpp, RefCtsTime.cpp, RefMenu.cpp]
2026-08-22 board: drop the V1.0 and V1.5 revisions
    Their up button and battery tap sat on different pins from V2.0's, which
    is the only reason board.h's ESP32 branch had a three-way #if. Neither
    revision has ever been run against this firmware. The retired flags now
    stop the build rather than silently selecting the V2.0 map, and the
    surviving pin map is pinned by a host test.
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2026-08-22 docs: describe the two supported boards
    The README still walked a reader through building for V1.0, V1.5 and
    V3, quoted the DS3231's drift figures, and told them to ignore the C6
    env. Says what the firmware now supports, why the retired flags stop the
    build, and that a C6 build has no working RTC yet.
    [settings.h]
2026-08-22 docs: fix About row to say board name, not revision
    The row still claimed "board revision" after Task 4 replaced
    RefClock::boardRevision() with board.h's BOARD_NAME in showAbout().
    Re-verified the row against showAbout()'s actual print order; nothing
    else in it is stale.
2026-08-22 docs: fix inaccurate strapping-pin, S3 pin-count, and reflow in comments
    Final review of drop-watchy-v1-v3 found three false or malformed comments:
    README claimed IO0/MENU is the C6's bootloader strap (it's IO9, which has
    no button by design; forcing download mode means shorting TP1 to ground),
    board.h claimed the ESP32-S3 lacks GPIO 26/35 (it doesn't; the real issue
    is the S3's pin map is unrelated to V2.0's), and a settings.h comment had
    a stray line break from an earlier edit. No code or values changed.
    [board.h, settings.h]
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2026-08-22 rtc: drive the C6 board's RV-3028-C7
    The C6 board has always carried an RV-3028-C7 at 0x52 that RefRtc knew
    nothing about, so a watchy_c6 build probed for two chips it does not
    have, found neither, and reported no clock at all.
    The two register maps disagree where it hurts: the PCF8563 holds the
    date at 0x05 and the weekday at 0x06, the RV-3028 the weekday at 0x03
    and the date at 0x04. Reading one with the other's layout gives a day of
    the month between 0 and 6 -- wrong, and shaped like a date. So this also
    adds a stub I2C bus and tests both layouts against it, along with each
    chip's 'time is not set' flag and a write-then-read round trip. The
    README used to call RefRtc's BCD decoding one o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
    [RefMenu.cpp, RefRtc.cpp, settings.h]
2026-08-22 rtc: make the tests bite, and fix what review found wrong
    Review of the driver caught that most of the suite was passing on
    numbers that could not fail. Every fixture field was under 10, where BCD
    and binary are the same value, so dropping fromBcd or toBcd entirely
    still passed; the month was always August, so the range check that
    rejects a raw-read October would never have fired; and the hour was 14,
    which survives a 12-hour mask. The fixtures are now 2026-11-25 21:47:38
    and 2026-12-31 23:59:58, where every field is a number BCD changes.
    Three mutations that used to pass -- a 12-hour mask, a missing fromBcd
    on the month, a missing toBcd on the write -- now fail 4, 7 and 2
    assertions.
    The s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
    [RefRtc.cpp]
